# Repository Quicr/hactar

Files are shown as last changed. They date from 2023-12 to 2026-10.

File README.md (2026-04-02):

# HACTAR

Hardware design for test device

## Table of contents:
1. [License](#license)
2. [Quick Start](#quick-start)
3. [Where To Find Things](#where-to-find-things)
4. [LED Definitions](#led-definitions)
5. [Hardware Technologies](#hardware-technologies)
6. [Prerequisites](#prerequisites)
    1. [Debian](#debian-prerequisites)
    2. [MacOS](#macos-prerequisites)
    3. [Windows](#windows-prerequisites)
7. [Firmware](#firmware)
    1. [Management](#management)
    2. [User Interface](#user-interface)
    3. [Network](#network)
    4. [STM32 Toolchain](#stm32-toolchain-installation)
    5. [ESP32 Toolchain](#esp32-toolchain-installation)
8. [Software](#software)
    1. [Hactar-cli](#hactar-cli)
9. [Hactar Setup](#hactar_setup)
10. [Troubleshooting](#troubleshooting)

## License

The license for information in this repository is in [LICENSE](https://github.com/Quicr/hactar/blob/main/LICENSE).  This license covers everything in the repository except for the directory `firmware/ui/dependencies/cmox`, which is covered by the license in [firmware/ui/dependencies/cmox/LICENSE].

## Quick Start

The easiest way to build and flash all firmware is from the repository root:

```bash
# Build everything (requires Rust and ESP-IDF)
make all

# Flash all chips (requires device connected via USB)
make flash

# Or flash individual chips
make flash-mgmt
make flash-ui
make flash-net
```

For new developers looking to start developing on Hactar quickly there are quick start python scripts located in etc/quick-start, that will automatically download and setup your dev environment.

## Where To Find Things

- etc - Extra files

- firmware - Code for UI, Net, and Mgmt chips

- hardware - Schematics and PCB designs

- models - 3D models for project

- software - Tools and Utilities

## LED definitions

LED 1 - Power and Network status:
- Solid Blue - Everything is OK (Connected to MoQ + WiFi + Relay + AI)
- Pulsing Blue - Connecting / Searching (WiFi or MoQ)
- Pulsing Orange - WiFi OK but not connected MoQ
- Blinking Orange - Network Error (bad credentials or no WiFI in range)
- Solid Yellow - Low battery (<20%) - overrides blue states.
- Pulsing Yellow - Charging
- Solid Red - Unprogrammed
- Blinking Red - Hardware/Firmware Failure
- Blinking Purple - AI not connected/not working when user attempts to use it

LED 2 - User Activity & Notifications:
- Off - No messages / actions 
- Blinking Blue - Unread messages/notifications waiting
- Blinking Orange - User error (no headset detected)
- Solid Blue - User holding a PTT/PTTAI button.

## Hardware Technologies
- [KiCad 9](https://www.kicad.org/)
- [FreeCAD v1.0](https://www.freecad.org/)

## Prerequistites

### Debian Prerequistites

#### Groups
``` usermod $USER -aG dialout -aG plugdev ```

#### Rules.d

``` cp etc/rules.d/* /etc/udev/rules.d/ ```

### MacOS Prerequistites

[Homebrew](https://brew.sh/) is the recommended for installing everything in this project.

### Windows Prerequistites

We only support using [WSL2](https://learn.microsoft.com/en-us/windows/wsl/install) for development, you are free to use native windows, but it is untested on actually getting everything in this codebase running.

Any and all instructions for Debian will work on WSL and is recommended you follow those.

## Firmware

### Firmware Technologies
- [Rust](https://www.rust-lang.org/tools/install) (for MGMT chip and CTL tool)
- [GNU arm-none-eabi](https://developer.arm.com/downloads/-/gnu-rm) (for UI chip)
- [ESP-IDF v5.4.2](https://docs.espressif.com/projects/esp-idf/en/v5.4.2/esp32/get-started/index.html) (for NET chip)
- [STM32 CubeMX](https://www.st.com/en/development-tools/stm32cubemx.html)

The Firmware is split into 3 categories. Management, User Interface, and Network.
- Management - STM32F072 (Rust, in `link/mgmt`)
- User Interface - STM32F405 (C++, in `firmware/ui`)
- Network - ESP32S3 (C++, in `firmware/net`)

### CTL Tool

The `ctl` tool (in `link/ctl`) is a Rust command-line program that handles flashing and device communication. It auto-detects connected Hactar devices and provides commands for:

- Flashing firmware to all chips
- Sending commands to chips (ping, version, config)
- Monitoring device logs

Build and run the CTL tool:
```bash
# From repository root
make run-ctl

# Or directly
cd link/ctl && cargo run --release
```

### [___Management___](#management)

The management chip (STM32F072) is responsible for flashing firmware to the UI and NET chips, and routing communication between the USB interface and the other chips.

The MGMT firmware is written in Rust and located in `link/mgmt`.

##### To view your device list

- ##### Debian/MacOS

    `ls /dev/ttyUSB*` or `ls /dev/cu.usbserial-*`

- ##### Windows

    `Open printers and devices`

    `Find serial com ports`

    [Attach to WSL](https://learn.microsoft.com/en-us/windows/wsl/connect-usb)

    `In WSL check dmesg to find which serial port your device binded to`

*Flashing*

From the repository root:

```bash
make flash-mgmt
```

Or using the CTL tool directly:

```bash
link/ctl/target/release/ctl mgmt flash link/mgmt/target/thumbv6m-none-eabi/release/mgmt.bin
```

#### Commands

Run the CTL tool to interact with the device:

```bash
make run-ctl
```

Or use individual commands directly:

```bash
# Test connectivity
link/ctl/target/release/ctl hello

# Ping that traverses all chips (MGMT -> UI -> NET -> MGMT)
link/ctl/target/release/ctl circular-ping

# MGMT commands
link/ctl/target/release/ctl mgmt ping
link/ctl/target/release/ctl mgmt version

# UI commands
link/ctl/target/release/ctl ui ping
link/ctl/target/release/ctl ui version

# NET commands
link/ctl/target/release/ctl net ping
link/ctl/target/release/ctl net version
```

Legacy commands (via hactar-cli monitor):

- **hard reset** - Restarts the main function of the management chip
- **reset** - Resets `ui` chip and then `net` chip
- **reset ui** - Resets `ui` chip
- **reset net** - Resets `net` chip
- **stop ui** - Hold `ui` chip in reset
- **stop net** - Hold `net` chip in reset
- **enable logs** - Enables logs on the management side
- **disable logs** - Disable logs on the management side

#### UI commands

- **ui version** - Get the ui version
- **ui clear_config** - Clear the eeprom config on the ui
- **ui set_sframe** - Sets the sframe key
- **ui get_sframe** - Gets the sframe key
- **ui toggle_logs** - Toggles logging on the ui side
- **ui disable_logs** - Disables logging on the ui side
- **ui enable_logs** - Enables logging on the ui side

#### NET commands

- **net version** - Get the net version
- **net clear_storage** - Clears the storage to default values
- **net set_ssid** - Sets the wifi ssid name and password and saves it in the NVS
- **net get_ssid_names** - Gets all of the ssid names stored
- **net get_ssid_passwords** - Gets all of the ssid passwords stored
- **net clear_ssids** - Clears all ssids from storage
- **net set_moq_url** - Sets the moq url
- **net get_moq_url** - Gets the current moq url
- **net toggle_logs** - Toggles logs on the net side
- **net disable_logs** - Disables logs on the net side
- **net enable_logs** - Enables logs on the net side
- **net disable_loopback** - Disables looping outputted data back in
- **net enable_loopback** - Enables looping outputted data back in
- **net set_fl_config** - Sets the frontline config
- **net burn_efuse** - Burns the efuse to enable jtag debugging

#### Root Makefile Targets

From the repository root:

- `make all` - Build all firmware (MGMT, UI, NET) and the CTL tool
- `make flash` - Flash all chips
- `make flash-mgmt` - Flash only the MGMT chip
- `make flash-ui` - Flash only the UI chip
- `make flash-net` - Flash only the NET chip
- `make run-ctl` - Run the CTL tool interactively
- `make clean` - Clean all build artifacts

**Source code**

The Management Chip firmware is written in Rust and located in `link/mgmt`.

### User Interface

The User Interface chip is where most of the processing takes place. It utilizes a STM32F405 chip empowered by the STM HAL Library. To generate the baseline HAL Library code and Makefile, ST's CubeMX was used.

**Makefile Target Overview**

- `all` - Builds the target bin, elf, and binary files and uploads the code to the User Interface chip. Output firmware/build/ui

- `compile` - Builds the target bin, elf, and binary. Output firmware/build/ui

- `upload` - Uploads the build target to the User Interface chip using the our custom flasher tool with serial usb-c uploading. See [Python Flasher](#py_flasher)

- `upload_debugger` - Uploads the build target to the User Interface chip using the st-flash tools. Please see
[st-flash installation](#stflash_installation) for instructions on installing.

- `upload_cube_uart` - Uploads the build target to the User Interface chip using the STM32_Programmer_CLI with serial usb-c uploading. See [Installation](#stm_installation) for instructions on installing the STM32_Programmer_CLI.

- `upload_cube_swd` - Uploads the build target to the User Interface chip using the STM32_Programmer_CLI with st-link using SWD uploading. See [Installation](#stm_installation) for instructions on installing the STM32_Programmer_CLI.

- `docker` - Uses docker to compile, flash, and monitor the ui chip. By default it will compile the code. To change the functionality, pass a target of the Makefile into the parameter `mft` when being invoked.
    - Ex. `make docker mft=upload`
    - Ex. `make docker mft=monitor`

- `monitor` - Opens a serial communication line with the management chip with a python script that allows for sending of commands.

- `openocd` - Opens a openocd debugging instance. See [Installation](#stm_installation) for instructions on installing openocd.

- `docker-clean` - Removes dockere image that was generated when running docker target.

- `clean` - Deletes the firmware/build/ui directory.

**Source code**

All source code for the User Interface can be found in firmware/ui, firmware/shared, and firmware/shared_inc. Adding C/C++ files in firmware/ui/src and firmware/ui/inc does not require any changes in the makefile.

Making a shared header between chips should be added into firmware/shared_inc.

### **Network**

The network chip is a MOQ client using [quicr](https://github.com/Quicr/libquicr). The network chip communicates with the UI chip via UART serial communication.

We are leveraging the **esp-idf** framework.

**Makefile Target Overview**

- `all` - Runs the `compile` and `upload` targets.

- `compile` - Compiles the net code using the command `idf.py compile`

- `upload` - Uploads the build target to the Network chip using the our custom flasher tool with serial usb-c uploading. See [Python Flasher](#py_flasher)

- `upload_debugger` - Uploads the net code using openocd over an ESP-PROG

- `upload_esptool` - Uploads the network chip code by first sending a command to the mgmt chip to put the board into **net upload** mode. Then uses `esptool.py upload`

- `docker` - Uses docker to compile, flash, and monitor the ui chip. By default it will compile the code. To change the functionality, pass a target of the Makefile into the parameter `mft` when being invoked.
    - Ex. `make docker mft=upload`
    - Ex. `make docker mft=monitor`

- `monitor` - Opens a serial communication line with the management chip with a python script that allows for sending of commands.

- `clean` - Deletes the firmware/net/build directory.

- `fullclean` - Invokes idf.py fullclean.

- `docker-clean` - Removes dockere image that was generated when running docker target.

<b>Source code</b>

All source code for the network chip can be found in `firmware/net`, `firmware/shared`, and `firmware/shared_inc`.

## MGMT Toolchain Installation

The following tools are required for building the Management chip firmware and CTL tool.
- [Make](#make) \[required]
- [Rust](#rust) \[required]

##### **Make**

Make is used for compiling and uploading automation for each chip firmware.

*Debian*

```bash
sudo apt install make
```
*MacOS*

```brew
brew install make
```

##### Rust with Embedded ARM Target

Rust is required for building the MGMT firmware and CTL tool. **The MGMT chip requires the `thumbv6m-none-eabi` target** for cross-compilation to the STM32F072 (ARM Cortex-M0).

*All Platforms*

1. Install Rust:
```bash
curl --proto '=https' --tlsv1.2 -sSf https://sh.rustup.rs | sh
```

2. **Required:** Add the ARM Cortex-M0 target and tools for MGMT firmware:
```bash
rustup target add thumbv6m-none-eabi
cargo install cargo-binutils
rustup component add llvm-tools
```

Without the `thumbv6m-none-eabi` target, you will not be able to build the MGMT firmware.

## UI Toolchain Installation

The following tools are used for building the User Interface chip firmware.
- [ARM None Eabi Toolchain](#arm-none-eabi-toolchain) \[required]
- [Python3](https://www.python.org/downloads/) \[optional]
- [ST-Flash](#st-flash) \[optional]
- [STM32_Programmer_CLI](#stm32-programmer-cli) \[optional]
- [OpenOCD](#openocd) \[optional]

##### ARM None Eabi Toolchain

*Debian*

```bash
sudo apt install gcc-arm-none-eabi binutils-arm-none-eabi
```

*MacOS*

```sh
brew install --cask gcc-arm-embedded
```

##### ST Flash

*Debian*

```bash
sudo apt install stlink-tools
```

*MacOS*

```bash
brew install stm32flash
```

##### STM32 Programmer CLI

The STM32 Programmer CLI comes packages with the STM32 Cube Programmer. You'll need to download and install The STM32 Cube Programmer and add the STM32_Programmer_CLI binary to your path.
```
https://www.st.com/en/development-tools/stm32cubeprog.html
```

*Debian*

- Open your `.bashrc` file:
    ```
    sudo nano ~/.bashrc
    ```

- Add the following line to the `.bashrc` file
    ```bash
    export PATH="$PATH:/path/to/stm_cube_programmer/bin"
    ```

*MacOS*

- TODO

#### OpenOCD

Open On Chip Debugger, created by Dominic Rath, is a debugging software that can be used with micro-controllers to run debugging tools and stepping through code.

*Debian*

Run the following command:

```bash
sudo apt install openocd gdb-arm-none-eabi libnewlib-arm-none-eabi libstdc++-arm-none-eabi-newlib
```

If you don't have python3.8 installed, which is used for arm-none-eabi-gdb, then you'll need to install it
```bash
sudo add-apt-repository ppa:deadsnakes/ppa
apt update
sudo apt install python3.8
```

*MacOS*

Run the following commands in a terminal to install `openocd`

```brew
brew update
```

```brew
brew install open-ocd --HEAD
```
## ESP32 Toolchain Installation

This project leverages the usage of the ESP-IDF Library for the network chip.

The following tools are used for the Network.
- [Make](#make) \[required]
- [esp-idf v5.4.2](#esp-idf) \[required]

##### ESP IDF

- [Debian](https://docs.espressif.com/projects/esp-idf/en/v5.4.2/esp32/get-started/linux-macos-setup.html)
- [MacOS](https://docs.espressif.com/projects/esp-idf/en/v5.4.2/esp32/get-started/linux-macos-setup.html)

## Software 

### Hactar-cli

Hactar-cli is a multi-faceted tool, where it can flash, monitor, and send commands. We ship a version of python that includes pyserial with it.

#### Flasher

Generally the flasher is used automatically in the Makefile. However, you can flash whatever binary you want onto a chip that the flasher is designed for by running it as python script in the firmware/flasher folder.

ex.

```sh
python3 main.py flash --port=<port> --baud=<baudrate> --chip="<chip>" -bin="./build/app.bin"
```

You can omit passing a port and the flasher will attempt to find a Hactar board by searching your active usb serial ports.

```sh
python3 main.py flash --baud=115200 --chip="ui" -bin="./build/ui.bin"
```

#### Monitor

The serial monitor is a very simple serial monitor that allows a user to send commands to the mgmt chip as well as read serial logs.

This monitor can be used by the following command:

```sh
python main.py monitor --port=<port> --baud=<baudrate>
```

Ex.
```sh
python main.py monitor --port=/dev/ttyUSB0
```

### Hactar Setup

#### Prerequisites

- USB-C Cable
- [Rust](https://www.rust-lang.org/tools/install) with `thumbv6m-none-eabi` target
- arm-none-eabi toolchain (for UI chip)
- ESP-IDF v5.4 (for NET chip)
- make

Install Rust target for MGMT:
```bash
rustup target add thumbv6m-none-eabi
cargo install cargo-binutils
rustup component add llvm-tools
```

#### Flash All Chips

The simplest way to set up a Hactar device is to flash all chips at once from the repository root:

```bash
# Build everything
make all

# Flash all chips (MGMT, UI, NET)
make flash
```

#### Flash Individual Chips

*Management Chip*

```bash
make flash-mgmt
```

The MGMT chip must be flashed first as it handles flashing the other chips.

*UI Chip*

```bash
make flash-ui
```

*Network Chip*

```bash
make flash-net
```

Note: The NET chip firmware is large and takes about 4 minutes to upload.

*Debug mode example*

- Prerequisites
    - Python3
        - **pyserial** - download using `pip3 install pyserial`
    - make
    - USB-C Cable
- Have your hactar board programmed and plugged in using a USB-C cable
- Navigate to either `hactar/firmware/ui` or `hactar/firmware/net`
    - **NOTE** - Update your ports appropriately in the makefile
- Enter `make py_monitor` into your terminal
- You should see a serial monitor open in your terminal requesting a command. Enter `debug` to put the hactar board into debugging mode.
    - See [Management Commands](#management_commands) for more commands that can be sent to the hactar board.
- The first and third LED from the left will turn blue indicating debug mode and your console will receive serial debug messages from the UI and Net chips.
- Enter `exit` to leave the monitor

## Troubleshooting

### USB device disconnects shortly after connecting randomly

- CH340 chips are shared with a program called brltty which is for braille devices. Debian automatically will try to connect it to brltty and therefore is in use, you can unplug and replug until it doesn't take control of the device or you can uninstall brltty if you don't need braille device.
    - ``` sudo apt remove brltty ```

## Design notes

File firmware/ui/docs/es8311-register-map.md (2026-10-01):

# ES8311 Register Map

Transcribed from `ES8311 DS.pdf`, revision 8.0 (May 2020). Fields not listed in a table are reserved or undocumented by the datasheet.

## 0x00 Reset (default `0x1F`)

- `CSM_ON` [7]: 0 = CSM power down (default); 1 = CSM power on.
- `MSC` [6]: 0 = serial port slave (default); 1 = serial port master.
- `SEQ_DIS` [5]: 0 = power-up sequence enabled (default); 1 = disabled.
- `RST_DIG` [4]: 0 = digital logic not reset; 1 = reset digital logic except control port (default).
- `RST_CMG` [3]: 0 = clock manager not reset; 1 = reset clock manager (default).
- `RST_MST` [2]: 0 = master block not reset; 1 = reset master block (default).
- `RST_ADC_DIG` [1]: 0 = ADC digital block not reset; 1 = reset ADC digital block (default).
- `RST_DAC_DIG` [0]: 0 = DAC digital block not reset; 1 = reset DAC digital block (default).

Remarks:
Chip must be reset at the start of each program. 0b0011'1111
given we are using ES8311 as master, then we should ensure that we select slave mode on bit 6

Hold in reset: 0b0011'1111
Running: 0b1100'0000

## 0x01 Clock Manager (default `0x00`)

- `MCLK_SEL` [7]: 0 = use MCLK pin (default); 1 = use BCLK pin.
- `MCLK_INV` [6]: 0 = normal MCLK (default); 1 = invert MCLK.
- `MCLK_ON` [5]: 0 = MCLK off (default); 1 = MCLK on.
- `BCLK_ON` [4]: 0 = BCLK off (default); 1 = BCLK on.
- `CLKADC_ON` [3]: 0 = ADC digital clock off (default); 1 = on.
- `CLKDAC_ON` [2]: 0 = DAC digital clock off (default); 1 = on.
- `ANACLKADC_ON` [1]: 0 = ADC analog clock off; 1 = on (default).
- `ANACLKDAC_ON` [0]: 0 = DAC analog clock off; 1 = on (default).

Remarks:
Using MCLK. Bit 5, MLK in control, enables/disables the mclk input pin. Since we are using our ES8311 in master, then we need sdp, adc, dac, analog adc and analog dac on

Set to: 0b0011'1111

## 0x02 Clock Manager (default `0x00`)

- `DIV_PRE` [7:5]: MCLK pre-divider; `mclk_prediv = mclk / (DIV_PRE + 1)`.
- `MULT_PRE` [4:3]: pre-multiplier; 0 = x1 (default), 1 = x2, 2 = x4, 3 = x8.
- `PATHSEL` [2]: 0 = no DFF path (default); 1 = DFF path.
- `DELYSEL` [1:0]: clock-doubler delay; 0 = 5 ns (default), 1 = 10 ns, 2 = 15 ns, 3 = 15 ns.

Remarks:
Digital clock aim is to be some defaulted value provided by the table on page 16 in the User Guide 
At MCLK 12Mhz 0x00 DIV1, MULT1 - 0b0000'0000, which doesn't make sense, because that gives an internal clock of 12Mhz, which
according to the User Guide, on page 14, that the clock divider needs to output <10Mhz. Their table is whack.
Roughly, I think given we are running at 3.0V, then we should be no higher than 8.9Mhz, by some crazy math, on the divider.

Therefore, to get the ratio integral ratio of 16 mentioned on pg 15 of the user guide, we can divide by 5, and multiply by 8
to get dig_mclk = 19.2Mhz.

This should be acceptable for 8Khz too.

For 19.2Mhz set register to 0x98

## 0x03 Clock Manager (default `0x10`)

- `ADC_FSMODE` [6]: 0 = single speed (default); 1 = double speed.
- `ADC_OSR` [5:0]: ADC delta-sigma oversampling rate. 0-14 unused; 15 = 60 x Fs; 16 = 64 x Fs single-speed or 32 x Fs double-speed (default); 31 = 124 x Fs or 62 x Fs; 32 = 128 x Fs or 64 x Fs; 63 = 252 x Fs or 126 x Fs.

Remarks:
Defaulting to table entry 12mhz 48khz 0x19 - 0b0001'1001
Not sure what the function of 

## 0x04 Clock Manager (default `0x10`)

- `DAC_OSR` [6:0]: DAC oversampling rate. 0-15 unused; 16 = 64 x Fs (default); 17 = 68 x Fs; 32 = 128 x Fs; 64 = 256 x Fs; 127 = 508 x Fs.

Remarks:
Defaulting to table entry 12mhz 48khz 0x19 - 0b0001'1001

## 0x05 Clock Manager (default `0x00`)

- `DIV_CLKADC` [7:4]: ADC MCLK divider; `adc_mclk = dig_mclk / (DIV_CLKADC + 1)`.
- `DIV_CLKDAC` [3:0]: DAC MCLK divider; `dac_mclk = dig_mclk / (DIV_CLKDAC + 1)`.

Remarks:
The ratio for 48khz with a dig_mclk = 19.2mhz is 400 % 16 = 0
The ratio for 8Khz with a dig_mclk = 19.2mhz = 2400 % 16 = 0
This can stay untouched at 0x00

## 0x06 Clock Manager (default `0x03`)

- `BCLK_CON` [6]: master BCLK output control; 0 = continuous (default); 1 = stop after transfer.
- `BCLK_INV` [5]: 0 = normal BCLK (default); 1 = inverted BCLK.
- `DIV_BCLK` [4:0]: master BCLK divider. 0-19 = MCLK / (`DIV_BCLK` + 1), default 3; 20 = /22; 21 = /24; 22 = /25; 23 = /30; 24 = /32; 25 = /33; 26 = /34; 27 = /36; 28 = /44; 29 = /48; 30 = /66; 31 = /72.

Remarks:
Since we are using a non-standard clock, we need to stop the BCLK early, so bit 6 should be a 1
Note, we are aiming to have a BCLK = LRCLK * 32 bits * 2 channels, given we are early stopping the bclk then 
we can need to have a bclk > than our minimum bclk in a perfect division.

Ex. 
48KHz * 32 * 2 = 3.072MHz
12Mhz / 3.072Mhz = 3.90625

So we need to divide by 3 so we still have a faster bclk

Therefore, DIV_BCLK = 2
Giving us 

BCLK = MCLK / DIV_BCLK+1 
BCLK = 12MHz / 2+1 = 4MHz

## 0x07 Clock Manager (default `0x00`)

- `TRI_BLRCK` [5]: 0 = normal BCLK/LRCK output (default); 1 = tri-state output.
- `TRI_ADCDAT` [4]: 0 = normal ADCDAT output (default); 1 = tri-state output.
- `DIV_LRCK[11:8]` [3:0]: upper four bits of the master LRCK divider; `LRCK = MCLK / (LRCK_DIV + 1)`.

Remarks:
48KHz DIV_LRCK=0
32KHz DIV_LRCK=1
8KHz DIV_LRCK=5

## 0x08 Clock Manager (default `0xFF`)

- `DIV_LRCK[7:0]` [7:0]: lower eight bits of the master LRCK divider; `LRCK = MCLK / (LRCK_DIV + 1)`. A divider of zero holds LRCK high.

Remarks:
48Khz DIV_LCK=249
32Khz DIV_LCK=118
8Khz DIV_LCK=219

## 0x09 SDP Input (default `0x00`)

- `SDP_IN_SEL` [7]: 0 = left input data to DAC (default); 1 = right input data to DAC.
- `SDP_IN_MUTE` [6]: 0 = unmute (default); 1 = mute.
- `SDP_IN_LRP` [5]: I2S/justified: 0 = normal L/R polarity (default), 1 = inverted. DSP/PCM: 0 = MSB on second BCLK rising edge after LRCK (default), 1 = first edge.
- `SDP_IN_WL` [4:2]: 0 = 24 bit (default); 1 = 20 bit; 2 = 18 bit; 3 = 16 bit; 4 = 32 bit.
- `SDP_IN_FMT` [1:0]: 0 = I2S (default); 1 = left justified; 2 = reserved; 3 = DSP/PCM.

Remarks: 
Soft mute exists in this register. 
We are doing 16 bit on 32 bit frames, could change if needed
I2S serial audio data format is what we normally use

In the STM32 settings it is set to I2S Phillips, and so should the ES8311,
but there is an error in the datasheet.

Correction!
bit[1:0] - 0 = Left justified, 1 = I2S Phillips, 2 = reserved 3 = DSP/PCM

Set to 0b0|0|0|1'00|00 (0x10)

## 0x0A SDP Output (default `0x00`)

- `SDP_OUT_MUTE` [6]: 0 = unmute (default); 1 = mute.
- `SDP_OUT_LRP` [5]: I2S/justified: 0 = normal L/R polarity (default), 1 = inverted. DSP/PCM: 0 = MSB on second BCLK rising edge after LRCK (default), 1 = first edge.
- `SDP_OUT_WL` [4:2]: 0 = 24 bit (default); 1 = 20 bit; 2 = 18 bit; 3 = 16 bit; 4 = 32 bit.
- `SDP_OUT_FMT` [1:0]: 0 = I2S (default); 1 = left justified; 2 = reserved; 3 = DSP/PCM.

Remarks:
Same as above

Set to 0b0|0|0|1'00|00 (0x10)

## 0x0B System (default `0x00`)

- `PWRUP_A` [7:3]: power-up stage A delay. At 8 kHz, 0-31 corresponds to 120 us-1392 ms.
- `PWRUP_B[3:1]` [2:0]: upper three bits of power-up stage B delay. At 8 kHz, 0-31 corresponds to 120 us-624 ms.

Remarks:
Leave at zero

## 0x0C System (default `0x20`)

- `PWRUP_B[0]` [7]: low bit of power-up stage B delay.
- `PWRUP_C` [6:0]: power-up stage C delay. At 8 kHz, 0-31 corresponds to 120 us-1401 ms.

Remarks:
Leave at zero

## 0x0D System (default `0xFC`)

- `PDN_ANA` [7]: 0 = enable analog circuits; 1 = power down (default).
- `PDN_IBIASGEN` [6]: 0 = enable analog bias; 1 = power down (default).
- `PDN_ADCBIASGEN` [5]: 0 = enable ADC bias; 1 = power down (default).
- `PDN_ADCVERFGEN` [4]: 0 = enable ADC reference; 1 = power down (default).
- `PDN_DACVREFGEN` [3]: 0 = enable DAC reference; 1 = power down (default).
- `PDN_VREF` [2]: 0 = disable internal reference; 1 = enable (default).
- `VMIDSEL` [1:0]: 0 = VMID power down (default); 1 = normal-speed startup; 2 = normal operation; 3 = fast startup.

Remarks:
0xFE

## 0x0E System (default `0x6A`)

- `PDN_PGA` [6]: 0 = enable analog PGA; 1 = power down (default).
- `PDN_MOD` [5]: 0 = enable analog ADC modulator; 1 = power down (default).
- `RST_MOD` [4]: 0 = normal (default); 1 = reset modulator.
- `VROI` [3]: 0 = normal impedance; 1 = low impedance (default).
- `LPVREFBUF` [2]: 0 = normal internal reference mode (default); 1 = low-power mode.

Remarks:
0b000'1010
0x0A

## 0x0F System (default `0x00`)

- `LPDAC` [7]: 0 = normal (default); 1 = DAC low-power mode.
- `LPPGA` [6]: 0 = normal (default); 1 = PGA low-power mode.
- `LPPGAOUT` [5]: 0 = normal (default); 1 = PGA output low-power mode.
- `LPVCMMOD` [4]: 0 = normal (default); 1 = ADC low-power mode.
- `LPADCVRP` [3]: 0 = normal (default); 1 = ADC reference low-power mode.
- `LPDACVRP` [2]: 0 = normal (default); 1 = DAC reference low-power mode.
- `LPFLASH` [1]: 0 = normal (default); 1 = ADC low-power mode.
- `LPINT1` [0]: 0 = normal (default); 1 = ADC low-power mode.

Remarks:
Only need to worry about this when we want to do low power

## 0x10 System (default `0x13`)

- `SYNCMODE` [7]: 0 = normal (default); 1 = sync mode.
- `VMIDLOW` [6:5]: 0 = VDDA/2 (default); 1 = VDDA/2 - 75 mV; 2 = VDDA/2 - 145 mV; 3 = VDDA/2 - 175 mV.
- `DAC_IBIAS_SW` [4]: 0 = normal DAC bias; 1 = higher DAC bias (default).
- `IBIAS_SW` [3:2]: 0 = bias level 0 (default); 1 = level 1; 2 = level 2; 3 = level 3.
- `VX2OFF` [1]: 0 = enable internal reference doubler; 1 = off (default).
- `VX1SEL` [0]: 0 = 1.45 V; 1 = 1.65 V (default).

- Remarks, not sure what sync mode means, but we can leave this for now

## 0x11 System (default `0x7C`)

- `VSEL` [6:0]: internal use.

## 0x12 System (default `0x02`)

- `PDN_DAC` [1]: 0 = enable DAC; 1 = power down (default).
- `ENREFR` [0]: 0 = disable DAC output reference (default); 1 = enable it.

Remarks:
0x01

## 0x13 System (default `0x40`)

- `HPSW` [4]: 0 = line-output drive (default); 1 = headphone drive.

Remarks:
We want headphones not line output
0x50

## 0x14 System (default `0x10`)

- `DMIC_ON` [6]: 0 = no DMIC; 1 = select DMIC and DMIC_SDA from MIC1P.
- `LINSEL` [4]: 0 = no input selection; 1 = select MIC1P-MIC1N.
- `PGAGAIN` [3:0]: ADC PGA gain: 0 = 0 dB through 10 = 30 dB in 3 dB steps.

Remarks:
We are using an analog mic 
0x10

## 0x15 ADC (default `0x00`)

- `ADC_RAMPRATE` [7:4]: ADC volume-control ramp: 0 = disabled; 1-15 = 0.25 dB per 4-65536 LRCKs.
- `DMIC_SENSE` [0]: 0 = latch DMIC on positive edge; 1 = negative edge.

Remarks:
We are not using DMIC 
Keep the ramp rate at default
0x00

## 0x16 ADC (default `0x04`)

- `ADC_SYNC` [5]: 0 = non-standard audio clock; 1 = standard audio clock.
- `ADC_INV` [4]: 0 = normal; 1 = inverted.
- `ADC_RAMCLR` [3]: clear ADC RAM when LRCK/ADC MCLK is active.
- `ADC_SCALE` [2:0]: ADC gain scale: 0 = 0 dB; 1 = 6 dB; 2 = 12 dB; 3 = 18 dB; 4 = 24 dB (default); 5 = 30 dB; 6 = 36 dB; 7 = 42 dB.

Remarks: 48khz and 8khz are standard audio clocks so we should keep ADC_SYNC=0

## 0x17 ADC Volume (default `0x00`)

- `ADC_VOLUME` [7:0]: 0x00 = -95.5 dB; 0x01 = -90.5 dB; then 0.5 dB/step; 0xBE = -0.5 dB; 0xBF = 0 dB; 0xC0 = +0.5 dB; 0xFF = +32 dB. With ALC enabled, this is `MAXGAIN`.

Remarks: Leave as default

## 0x18 ADC ALC (default `0x00`)

- `ALC_EN` [7]: 0 = disable (default); 1 = enable ADC automatic level control.
- `ADC_AUTOMUTE_EN` [6]: 0 = disable (default); 1 = enable ADC automute.
- `ALC_WINSIZE` [3:0]: ALC window: 0 = 0.25 dB/2 LRCK; 1-15 increase through 0.25 dB/65536 LRCK.

Remarks: Leave as default, we don't want the ALC yet

## 0x19 ADC ALC Level (default `0x00`)

- `ALC_MAXLEVEL` [7:4]: ALC maximum target: 0 = -30.1 dB through 15 = -6.0 dB.
- `ALC_MINLEVEL` [3:0]: ALC minimum target: 0 = -30.1 dB through 15 = -6.0 dB.

## 0x1A ADC Automute (default `0x00`)

- `ADC_AUTOMUTE_WS` [7:4]: detect window: samples = 2048 x (`winsize` + 1); 0 = 2048 samples / 42 ms, 15 = 32768 samples / 688 ms.
- `ADC_AUTOMUTE_NG` [3:0]: noise gate: 0 = -96 dB, increasing by 6 dB through 7 = -54 dB, then 3 dB through 15 = -30 dB.

## 0x1B ADC Automute/HPF (default `0x0C`)

- `ADC_AUTOMUTE_VOL` [7:5]: mute output gain; gain = value x -4 dB, 0 = 0 dB through 7 = -28 dB.
- `ADC_HPFS1` [4:0]: ADC HPF stage-1 coefficient.

## 0x1C ADC EQ/HPF (default `0x4C`)

- `ADC_EQBYPASS` [6]: 0 = normal; 1 = bypass (default).
- `ADC_HPF` [5]: 0 = freeze offset; 1 = dynamic HPF.
- `ADC_HPFS2` [4:0]: ADC HPF stage-2 coefficient.

## 0x1D ADCEQ B0[29:24] (default `0x00`

- `ADCEQ_B0[29:24]` [5:0]: upper six bits of the 30-bit ADCEQ B0 coefficient.

## 0x1E ADCEQ B0[23:16] (default `0x00`)

- `ADCEQ_B0[23:16]` [7:0]: ADCEQ B0 coefficient bits 23:16.

## 0x1F ADCEQ B0[15:8] (default `0x00`)

- `ADCEQ_B0[15:8]` [7:0]: ADCEQ B0 coefficient bits 15:8.

## 0x20 ADCEQ B0[7:0] (default `0x00`)

- `ADCEQ_B0[7:0]` [7:0]: ADCEQ B0 coefficient bits 7:0.

## 0x21 ADCEQ A1[29:24] (default `0x00`)

- `ADCEQ_A1[29:24]` [7:0]: upper byte of the 30-bit ADCEQ A1 coefficient, per datasheet.

## 0x22 ADCEQ A1[23:16] (default `0x00`)

- `ADCEQ_A1[23:16]` [7:0]: ADCEQ A1 coefficient bits 23:16.

## 0x23 ADCEQ A1[15:8] (default `0x00`)

- `ADCEQ_A1[15:8]` [7:0]: ADCEQ A1 coefficient bits 15:8.

## 0x24 ADCEQ A1[7:0] (default `0x00`)

- `ADCEQ_A1[7:0]` [7:0]: ADCEQ A1 coefficient bits 7:0.

## 0x25 ADCEQ A2[29:24] (default `0x00`)

- `ADCEQ_A2[29:24]` [7:0]: upper byte of the 30-bit ADCEQ A2 coefficient, per datasheet.

## 0x26 ADCEQ A2[23:16] (default `0x00`)

- `ADCEQ_A2[23:16]` [7:0]: ADCEQ A2 coefficient bits 23:16.

## 0x27 ADCEQ A2[15:8] (default `0x00`)

- `ADCEQ_A2[15:8]` [7:0]: ADCEQ A2 coefficient bits 15:8. The datasheet has a likely typo calling this B0.

## 0x28 ADCEQ A2[7:0] (default `0x00`)

- `ADCEQ_A2[7:0]` [7:0]: ADCEQ A2 coefficient bits 7:0.

## 0x29 ADCEQ B1[29:24] (default `0x00`)

- `ADCEQ_B1[29:24]` [7:0]: upper byte of the 30-bit ADCEQ B1 coefficient, per datasheet.

## 0x2A ADCEQ B1[23:16] (default `0x00`)

- `ADCEQ_B1[23:16]` [7:0]: ADCEQ B1 coefficient bits 23:16.

## 0x2B ADCEQ B1[15:8] (default `0x00`)

- `ADCEQ_B1[15:8]` [7:0]: ADCEQ B1 coefficient bits 15:8. The datasheet has a likely typo calling this B0.

## 0x2C ADCEQ B1[7:0] (default `0x00`)

- `ADCEQ_B1[7:0]` [7:0]: ADCEQ B1 coefficient bits 7:0.

## 0x2D ADCEQ B2[29:24] (default `0x00`)

- `ADCEQ_B2[29:24]` [7:0]: upper byte of the 30-bit ADCEQ B2 coefficient, per datasheet.

## 0x2E ADCEQ B2[23:16] (default `0x00`)

- `ADCEQ_B2[23:16]` [7:0]: ADCEQ B2 coefficient bits 23:16.

## 0x2F ADCEQ B2[15:8] (default `0x00`)

- `ADCEQ_B2[15:8]` [7:0]: ADCEQ B2 coefficient bits 15:8.

## 0x30 ADCEQ B2[7:0] (default `0x00`)

- `ADCEQ_B2[7:0]` [7:0]: ADCEQ B2 coefficient bits 7:0.

## 0x31 DAC (default `0x00`)

- `DAC_DSMMUTE_TO` [7]: 0 = mute to 8 (default); 1 = mute to 7/9.
- `DAC_DSMMUTE` [6]: 0 = unmute (default); 1 = mute.
- `DAC_DEMMUTE` [5]: 0 = unmute (default); 1 = mute.
- `DAC_INV` [4]: 0 = no phase inversion (default); 1 = 180 degree phase inversion.
- `DAC_RAMCLR` [3]: 0 = normal (default); 1 = clear DAC RAM when LRCK/DAC MCLK is active.
- `DAC_DSMDITH_OFF` [2]: 0 = dither on (default); 1 = dither off.

## 0x32 DAC Volume (default `0x00`)

- `DAC_VOLUME` [7:0]: 0x00 = -95.5 dB; 0x01 = -95.0 dB; then 0.5 dB/step; 0xBE = -0.5 dB; 0xBF = 0 dB; 0xC0 = +0.5 dB; 0xFF = +32 dB.

## 0x33 DAC Offset (default `0x00`)

- `DAC_OFFSET` [7:0]: DAC offset.

## 0x34 DAC DRC (default `0x00`)

- `DRC_EN` [7]: 0 = disable DRC (default); 1 = enable.
- `DRC_WINSIZE` [3:0]: DRC window: 0 = 0.25 dB/2 LRCK (default); 1-15 increase through 0.25 dB/65536 LRCK.

## 0x35 DAC DRC Level (default `0x00`)

- `DRC_MAXLEVEL` [7:4]: DRC maximum target: 0 = -30.1 dB through 15 = -6.0 dB.
- `DRC_MINLEVEL` [3:0]: DRC minimum target: 0 = -30.1 dB through 15 = -6.0 dB.

## 0x36 DAC (default `0x00`)

- No bit mappings are provided for this register in the supplied datasheet.

## 0x37 DAC (default `0x08`)

- `DAC_RAMPRATE` [7:4]: DAC VC/DRC ramp: 0 = disabled (default); 1-15 = 0.25 dB per 4-65536 LRCKs.
- `DAC_EQBYPASS` [3]: 0 = DACEQ enabled (default); 1 = bypass.

## 0x38 DACEQ B0[29:24] (default `0x00`)

- `DACEQ_B0[29:24]` [5:0]: upper six bits of the 30-bit DACEQ B0 coefficient.

## 0x39 DACEQ B0[23:16] (default `0x00`)

- `DACEQ_B0[23:16]` [7:0]: DACEQ B0 coefficient bits 23:16.

## 0x3A DACEQ B0[15:8] (default `0x00`)

- `DACEQ_B0[15:8]` [7:0]: DACEQ B0 coefficient bits 15:8.

## 0x3B DACEQ B0[7:0] (default `0x00`)

- `DACEQ_B0[7:0]` [7:0]: DACEQ B0 coefficient bits 7:0.

## 0x3C DACEQ B1[29:24] (default `0x00`)

- `DACEQ_B1[29:24]` [7:0]: upper byte of the 30-bit DACEQ B1 coefficient, per datasheet.

## 0x3D DACEQ B1[23:16] (default `0x00`)

- `DACEQ_B1[23:16]` [7:0]: DACEQ B1 coefficient bits 23:16.

## 0x3E DACEQ B1[15:8] (default `0x00`)

- `DACEQ_B1[15:8]` [7:0]: DACEQ B1 coefficient bits 15:8.

## 0x3F DACEQ B1[7:0] (default `0x00`)

- `DACEQ_B1[7:0]` [7:0]: DACEQ B1 coefficient bits 7:0.

## 0x40 DACEQ A1[29:24] (default `0x00`)

- `DACEQ_A1[29:24]` [7:0]: upper byte of the 30-bit DACEQ A1 coefficient, per datasheet.

## 0x41 DACEQ A1[23:16] (default `0x00`)

- `DACEQ_A1[23:16]` [7:0]: DACEQ A1 coefficient bits 23:16.

## 0x42 DACEQ A1[15:8] (default `0x00`)

- `DACEQ_A1[15:8]` [7:0]: DACEQ A1 coefficient bits 15:8.

## 0x43 DACEQ A1[7:0] (default `0x00`)

- `DACEQ_A1[7:0]` [7:0]: DACEQ A1 coefficient bits 7:0.

## 0x44 GPIO (default `0x00`)

- `ADC2DAC_SEL` [7]: 0 = disable ADC-to-DAC path (default); 1 = enable.
- `ADCDAT_SEL` [6:4]: ADCDAT output: 0 = ADC + ADC (default); 1 = ADC + 0; 2 = 0 + ADC; 3 = 0 + 0; 4 = DACL + ADC; 5 = ADC + DACR; 6 = DACL + DACR; 7 = N/A.
- `I2C_WL` [3]: internal use.
- `GPIO_SEL` [2:0]: internal use.

## 0x45 GP (default `0x00`)

- `FORCECSM` [7:4]: internal use.
- `ADC_DLY_SEL` [3]: internal use.
- `DAC_DLY_SEL` [2]: internal use.
- `DAC_AUTOCHN` [1]: internal use.
- `PULLUP_SE` [0]: BCLK/LRCK pull-up: 0 = on (default); 1 = off.

## 0xFA I2C (default `0x00`)

- `I2C_RETIME` [1]: internal use.
- `INI_REG` [0]: 0 = no reset (default); 1 = reset registers to defaults except this register.

## 0xFC Flag (default `0x00`, read-only fields)

- `FLAG_CSM_CHIP` [6:4]: CSM state: 0 = S0; 1 = S1; 2 = S2; 3 = S3; 6 = S6; 7 = S7; other values are dummy states.
- `FLAG_ADCAM` [1]: ADC automute flag.
- `FLAG_DACAM` [0]: internal use.

## 0xFD Chip ID 1 (default `0x83`)

- `CHIP_ID1` [7:0]: chip ID, `0x83`.

## 0xFE Chip ID 2 (default `0x11`)

- `CHIP_ID2` [7:0]: chip ID, `0x11`.

## 0xFF Chip Version (default `0x00`)

- `CHIP_VER` [7:0]: chip version information.

## Comments

- The datasheet states that MCLK, LRCK, and SCLK should be present before control-register configuration; otherwise reset the codec after the clocks are provided.
- Registers `0x21`, `0x25`, `0x29`, `0x2D`, `0x3C`, and `0x40` describe 30-bit coefficient upper portions as `[29:24]` while exposing eight bits. This is reproduced as documented.
- Register `0x36` has no bit definitions in the supplied revision.
- Do not write undocumented or internal-use fields unless validated by the vendor.

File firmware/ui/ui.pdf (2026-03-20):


20/03/2026

ui Project
Configuration Report

## 1. Description

### 1.1. Project

Project Name | ui
Board Name | custom
Generated with: | STM32CubeMX 6.16.1
Date | 03/20/2026

### 1.2. MCU

MCU Series | STM32F4
MCU Line | STM32F405/415
MCU name | STM32F405RGTx
MCU Package | LQFP64
MCU Pin number | 64

### 1.3. Core(s) information

Core(s) | Arm Cortex-M4

## 2. Pinout Configuration

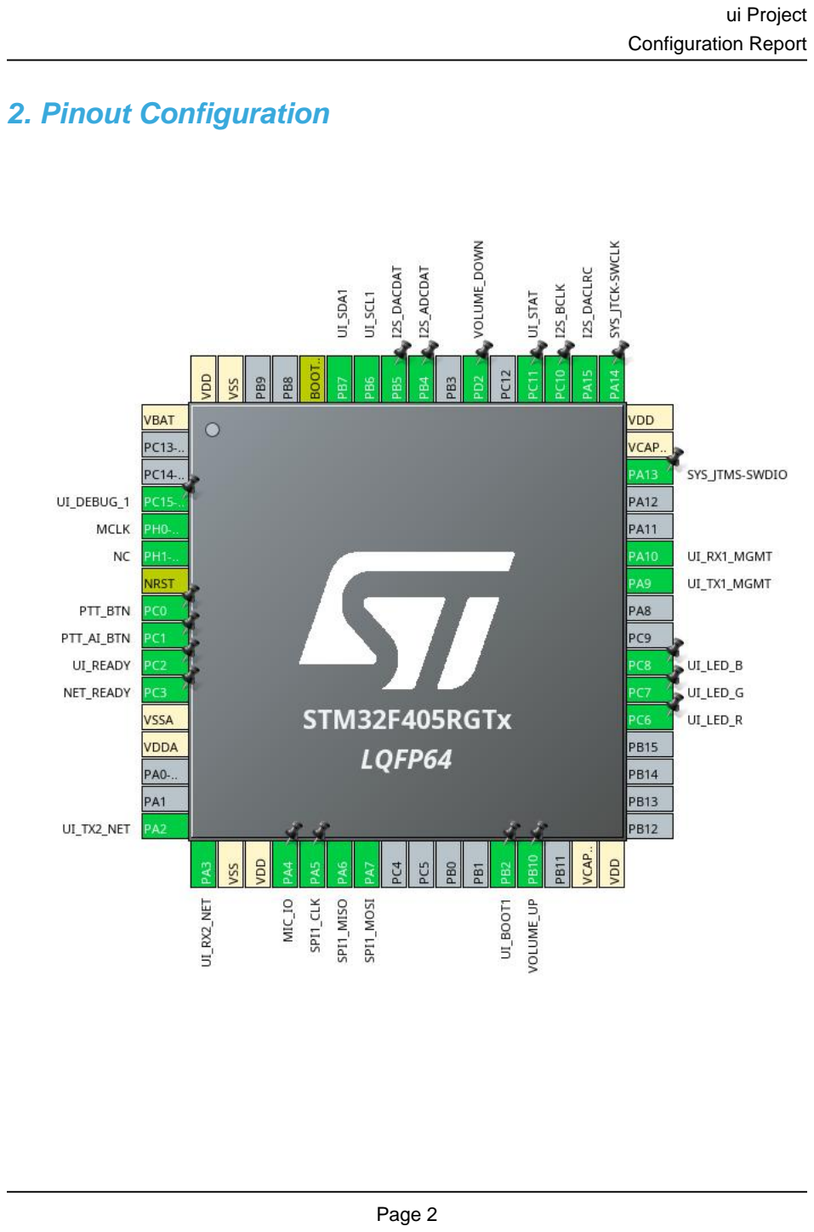
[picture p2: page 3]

## 3. Pins Configuration

Pin Number LQFP64 | Pin Name (function after reset) | Pin Type | Alternate Function(s) | Label
1 | VBAT | Power
4 | PC15-OSC32_OUT * | I/O | GPIO_Output | UI_DEBUG_1
5 | PH0-OSC_IN | I/O | RCC_OSC_IN | MCLK
6 | PH1-OSC_OUT | I/O | RCC_OSC_OUT | NC
7 | NRST | Reset
8 | PC0 * | I/O | GPIO_Input | PTT_BTN
9 | PC1 * | I/O | GPIO_Input | PTT_AI_BTN
10 | PC2 * | I/O | GPIO_Output | UI_READY
11 | PC3 | I/O | GPIO_EXTI3 | NET_READY
12 | VSSA | Power
13 | VDDA | Power
16 | PA2 | I/O | USART2_TX | UI_TX2_NET
17 | PA3 | I/O | USART2_RX | UI_RX2_NET
18 | VSS | Power
19 | VDD | Power
20 | PA4 * | I/O | GPIO_Input | MIC_IO
21 | PA5 | I/O | SPI1_SCK | SPI1_CLK
22 | PA6 | I/O | SPI1_MISO
23 | PA7 | I/O | SPI1_MOSI | SPI1_MOSI
28 | PB2 * | I/O | GPIO_Input | UI_BOOT1
29 | PB10 * | I/O | GPIO_Input | VOLUME_UP
31 | VCAP_1 | Power
32 | VDD | Power
37 | PC6 | I/O | TIM3_CH1 | UI_LED_R
38 | PC7 | I/O | TIM3_CH2 | UI_LED_G
39 | PC8 | I/O | TIM3_CH3 | UI_LED_B
42 | PA9 | I/O | USART1_TX | UI_TX1_MGMT
43 | PA10 | I/O | USART1_RX | UI_RX1_MGMT
46 | PA13 | I/O | SYS_JTMS-SWDIO
47 | VCAP_2 | Power
48 | VDD | Power
49 | PA14 | I/O | SYS_JTCK-SWCLK
50 | PA15 | I/O | I2S3_WS | I2S_DACLRC
51 | PC10 | I/O | I2S3_CK | I2S_BCLK
52 | PC11 * | I/O | GPIO_Output | UI_STAT
54 | PD2 * | I/O | GPIO_Input | VOLUME_DOWN

Pin Number LQFP64 | Pin Name (function after reset) | Pin Type | Alternate Function(s) | Label
56 | PB4 | I/O | I2S3_ext_SD | I2S_ADCDAT
57 | PB5 | I/O | I2S3_SD | I2S_DACDAT
58 | PB6 | I/O | I2C1_SCL | UI_SCL1
59 | PB7 | I/O | I2C1_SDA | UI_SDA1
60 | BOOT0 | Boot
63 | VSS | Power
64 | VDD | Power

* The pin is affected with an I/O function

## 4. Clock Tree Configuration

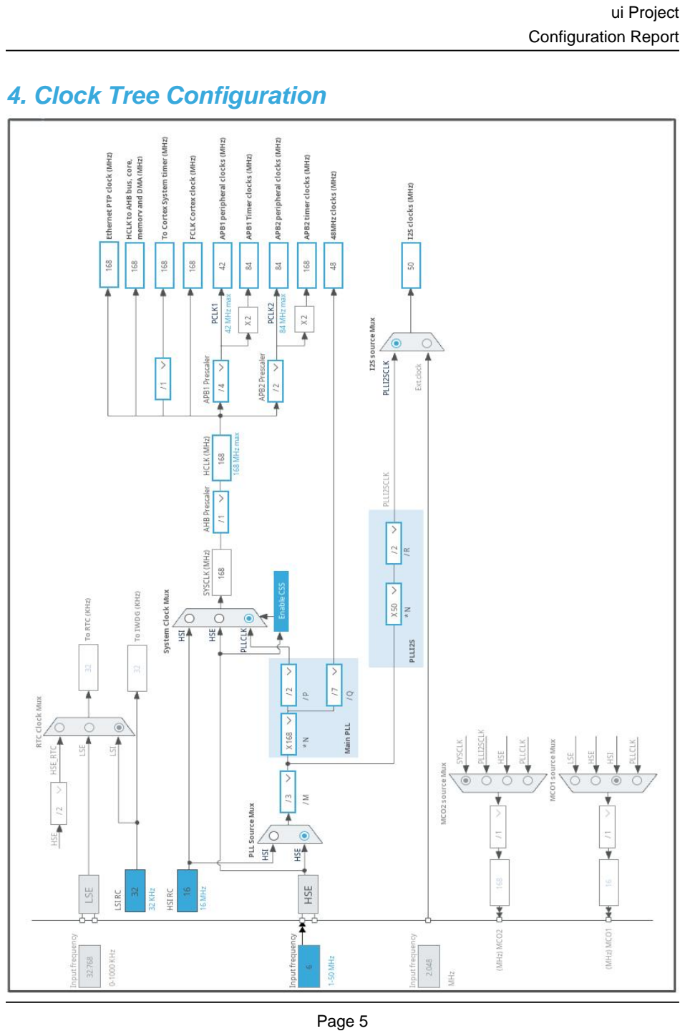
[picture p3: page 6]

## 1. Power Consumption Calculator report

### 1.1. Microcontroller Selection

Series | STM32F4
Line | STM32F405/415
MCU | STM32F405RGTx
Datasheet | DS8626_Rev8

### 1.2. Parameter Selection

Temperature | 25
Vdd | 3.3

### 1.3. Battery Selection

Battery | Li-SOCL2(A3400)
Capacity | 3400.0 mAh
Self Discharge | 0.08 %/month
Nominal Voltage | 3.6 V
Max Cont Current | 100.0 mA
Max Pulse Current | 200.0 mA
Cells in series | 1
Cells in parallel | 1

### 1.4. Sequence

Step | Step1 | Step2
Mode | RUN | STOP
Vdd | 3.3 | 3.3
Voltage Source | Battery | Battery
Range | Scale1-High | No Scale
Fetch Type | FLASH | n/a
CPU Frequency | 168 MHz | 0 Hz
Clock Configuration | HSE PLL | Regulator_LP Flash-PwrDwn
Clock Source Frequency | 4 MHz | 0 Hz
Peripherals
Additional Cons. | 0 mA | 0 mA
Average Current | 46 mA | 280 µA
Duration | 0.1 ms | 0.9 ms
DMIPS | 210.0 | 0.0
Ta Max | 98.02 | 104.96
Category | In DS Table | In DS Table

### 1.5. Results

Sequence Time | 1 ms | Average Current | 4.85 mA
Battery Life | 29 days, 4 hours | Average DMIPS | 210.0 DMIPS

### 1.6. Chart

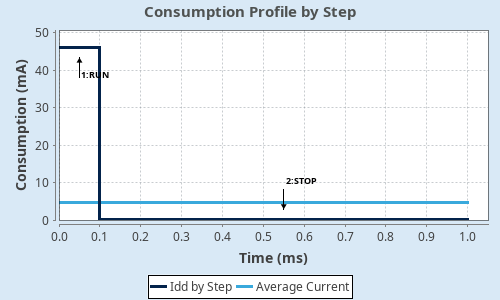
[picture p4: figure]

## 2. Software Project

### 2.1. Project Settings

Name | Value
Project Name | ui
Project Folder | /mnt/cisco/code/hactar/firmware/ui
Toolchain / IDE | CMake
Firmware Package Name and Version | STM32Cube FW_F4 V1.28.1
Application Structure | Advanced
Generate Under Root | No
Do not generate the main() | No
Minimum Heap Size | 0x200
Minimum Stack Size | 0x400

### 2.2. Code Generation Settings

Name | Value
STM32Cube MCU packages and embedded software | Copy all used libraries into the project folder
Generate peripheral initialization as a pair of '.c/.h' files | No
Backup previously generated files when re-generating | No
Keep User Code when re-generating | Yes
Delete previously generated files when not re-generated | Yes
Set all free pins as analog (to optimize the power consumption) | No
Enable Full Assert | No

### 2.3. Advanced Settings - Generated Function Calls

Rank | Function Name | Peripheral Instance Name
1 | SystemClock_Config | RCC
2 | MX_GPIO_Init | GPIO
3 | MX_DMA_Init | DMA
4 | MX_I2C1_Init | I2C1
5 | MX_I2S3_Init | I2S3
6 | MX_SPI1_Init | SPI1
7 | MX_USART1_UART_Init | USART1
8 | MX_USART2_UART_Init | USART2
9 | MX_TIM2_Init | TIM2
10 | MX_RNG_Init | RNG
11 | MX_CRC_Init | CRC

Rank | Function Name | Peripheral Instance Name
12 | MX_TIM3_Init | TIM3
13 | MX_TIM4_Init | TIM4
14 | MX_TIM5_Init | TIM5

## 3. Peripherals and Middlewares Configuration

### 3.1. CRC

mode: Activated

### 3.2. I2C1

I2C: I2C
3.2.1. Parameter Settings:

Master Features:

I2C Speed Mode | Standard Mode
I2C Clock Speed (Hz) | 100000
Slave Features:
Clock No Stretch Mode | Disabled
Primary Address Length selection | 7-bit
Dual Address Acknowledged | Disabled
Primary slave address | 0
General Call address detection | Disabled

### 3.3. I2S3

Mode: Full-Duplex Slave
3.3.1. Parameter Settings:

Generic Parameters:

Transmission Mode | Mode Slave Transmit
Communication Standard | I2S Philips
Data and Frame Format | 16 Bits Data on 32 Bits Frame *
Selected Audio Frequency | 8 KHz
Real Audio Frequency | 7.971 KHz *
Error between Selected and Real | -0.36 % *
Clock Parameters:
Clock Source | I2S PLL Clock
Clock Polarity | Low

### 3.4. RCC

High Speed Clock (HSE): BYPASS Clock Source
3.4.1. Parameter Settings:

System Parameters:

VDD voltage (V) | 3.3
Instruction Cache | Enabled
Prefetch Buffer | Enabled
Data Cache | Enabled
Flash Latency(WS) | 5 WS (6 CPU cycle)
RCC Parameters:
HSI Calibration Value | 16
HSE Startup Timout Value (ms) | 100
LSE Startup Timout Value (ms) | 5000
Power Parameters:
Power Regulator Voltage Scale | Power Regulator Voltage Scale 1

### 3.5. RNG

mode: Activated

### 3.6. SPI1

Mode: Full-Duplex Master
3.6.1. Parameter Settings:

Basic Parameters:

Frame Format | Motorola
Data Size | 8 Bits
First Bit | MSB First
Clock Parameters:
Prescaler (for Baud Rate) | 2
Baud Rate | 42.0 MBits/s *
Clock Polarity (CPOL) | Low
Clock Phase (CPHA) | 1 Edge
Advanced Parameters:
CRC Calculation | Disabled
NSS Signal Type | Software

### 3.7. SYS

Debug: Serial Wire
Timebase Source: SysTick

### 3.8. TIM2

Clock Source : Internal Clock
3.8.1. Parameter Settings:

Counter Settings:

Prescaler (PSC - 16 bits value) | 16800 *
Counter Mode | Up
Counter Period (AutoReload Register - 32 bits value ) | 200 *
Internal Clock Division (CKD) | No Division
auto-reload preload | Disable
Trigger Output (TRGO) Parameters:
Master/Slave Mode (MSM bit) | Disable (Trigger input effect not delayed)
Trigger Event Selection | Reset (UG bit from TIMx_EGR)

### 3.9. TIM3

Clock Source : Internal Clock
Channel1: PWM Generation CH1 Channel2: PWM Generation CH2 Channel3: PWM Generation CH3 mode: One Pulse Mode
3.9.1. Parameter Settings:

Counter Settings:

Prescaler (PSC - 16 bits value) | 168 *
Counter Mode | Up
Counter Period (AutoReload Register - 16 bits value ) | 10 *
Internal Clock Division (CKD) | No Division
auto-reload preload | Disable
Trigger Output (TRGO) Parameters:
Master/Slave Mode (MSM bit) | Disable (Trigger input effect not delayed)
Trigger Event Selection | Reset (UG bit from TIMx_EGR)
PWM Generation Channel 1:
Mode | PWM mode 1

Pulse (16 bits value) | 0
Output compare preload | Enable
Fast Mode | Disable
CH Polarity | High
PWM Generation Channel 2:
Mode | PWM mode 1
Pulse (16 bits value) | 0
Output compare preload | Enable
Fast Mode | Disable
CH Polarity | High
PWM Generation Channel 3:
Mode | PWM mode 1
Pulse (16 bits value) | 0
Output compare preload | Enable
Fast Mode | Disable
CH Polarity | High

### 3.10. TIM4

mode: Clock Source
3.10.1. Parameter Settings:

Counter Settings:

Prescaler (PSC - 16 bits value) | 8399 *
Counter Mode | Up
Counter Period (AutoReload Register - 16 bits value ) | 4999 *
Internal Clock Division (CKD) | No Division
auto-reload preload | Disable
Trigger Output (TRGO) Parameters:
Master/Slave Mode (MSM bit) | Disable (Trigger input effect not delayed)
Trigger Event Selection | Reset (UG bit from TIMx_EGR)

### 3.11. TIM5

mode: Clock Source
3.11.1. Parameter Settings:

Counter Settings:

Prescaler (PSC - 16 bits value) | 8399 *

Counter Mode | Up
Counter Period (AutoReload Register - 32 bits value ) | 4999 *
Internal Clock Division (CKD) | No Division
auto-reload preload | Disable
Trigger Output (TRGO) Parameters:
Master/Slave Mode (MSM bit) | Disable (Trigger input effect not delayed)
Trigger Event Selection | Reset (UG bit from TIMx_EGR)

### 3.12. USART1

Mode: Asynchronous
3.12.1. Parameter Settings:

Basic Parameters:

Baud Rate | 115200
Word Length | 9 Bits (including Parity) *
Parity | Even *
Stop Bits | 1
Advanced Parameters:
Data Direction | Receive and Transmit
Over Sampling | 16 Samples

### 3.13. USART2

Mode: Asynchronous
3.13.1. Parameter Settings:

Basic Parameters:

Baud Rate | 460800 *
Word Length | 8 Bits (including Parity)
Parity | None
Stop Bits | 2 *
Advanced Parameters:
Data Direction | Receive and Transmit
Over Sampling | 16 Samples

* User modified value

## 4. System Configuration

### 4.1. GPIO configuration

IP | Pin | Signal | GPIO mode | GPIO pull/up pull down | Max Speed | User Label
I2C1 | PB6 | I2C1_SCL | Alternate Function Open Drain | No pull-up and no pull-down | Very High * | UI_SCL1
| PB7 | I2C1_SDA | Alternate Function Open Drain | No pull-up and no pull-down | Very High * | UI_SDA1
I2S3 | PA15 | I2S3_WS | Alternate Function Push Pull | No pull-up and no pull-down | Low | I2S_DACLRC
| PC10 | I2S3_CK | Alternate Function Push Pull | No pull-up and no pull-down | Low | I2S_BCLK
| PB4 | I2S3_ext_SD | Alternate Function Push Pull | No pull-up and no pull-down | Low | I2S_ADCDAT
| PB5 | I2S3_SD | Alternate Function Push Pull | No pull-up and no pull-down | Low | I2S_DACDAT
RCC | PH0-OSC_IN | RCC_OSC_IN | n/a | n/a | n/a | MCLK
| PH1-OSC_OUT | RCC_OSC_OUT | n/a | n/a | n/a | NC
SPI1 | PA5 | SPI1_SCK | Alternate Function Push Pull | No pull-up and no pull-down | Very High * | SPI1_CLK
| PA6 | SPI1_MISO | Alternate Function Push Pull | No pull-up and no pull-down | Very High *
| PA7 | SPI1_MOSI | Alternate Function Push Pull | No pull-up and no pull-down | Very High * | SPI1_MOSI
SYS | PA13 | SYS_JTMS-SWDIO | n/a | n/a | n/a
| PA14 | SYS_JTCK-SWCLK | n/a | n/a | n/a
TIM3 | PC6 | TIM3_CH1 | Alternate Function Push Pull | No pull-up and no pull-down | Low | UI_LED_R
| PC7 | TIM3_CH2 | Alternate Function Push Pull | No pull-up and no pull-down | Low | UI_LED_G
| PC8 | TIM3_CH3 | Alternate Function Push Pull | No pull-up and no pull-down | Low | UI_LED_B
USART1 | PA9 | USART1_TX | Alternate Function Push Pull | No pull-up and no pull-down | Very High * | UI_TX1_MGMT
| PA10 | USART1_RX | Alternate Function Push Pull | No pull-up and no pull-down | Very High * | UI_RX1_MGMT
USART2 | PA2 | USART2_TX | Alternate Function Push Pull | No pull-up and no pull-down | Very High * | UI_TX2_NET
| PA3 | USART2_RX | Alternate Function Push Pull | Pull-down * | Very High * | UI_RX2_NET
GPIO | PC15-OSC32_OU T | GPIO_Output | Output Push Pull | No pull-up and no pull-down | Low | UI_DEBUG_1

IP | Pin | Signal | GPIO mode | GPIO pull/up pull down | Max Speed | User Label
| PC0 | GPIO_Input | Input mode | Pull-up * | n/a | PTT_BTN
| PC1 | GPIO_Input | Input mode | Pull-up * | n/a | PTT_AI_BTN
| PC2 | GPIO_Output | Output Push Pull | No pull-up and no pull-down | Low | UI_READY
| PC3 | GPIO_EXTI3 | External Interrupt Mode with Rising edge trigger detection | No pull-up and no pull-down | n/a | NET_READY
| PA4 | GPIO_Input | Input mode | No pull-up and no pull-down | n/a | MIC_IO
| PB2 | GPIO_Input | Input mode | No pull-up and no pull-down | n/a | UI_BOOT1
| PB10 | GPIO_Input | Input mode | No pull-up and no pull-down | n/a | VOLUME_UP
| PC11 | GPIO_Output | Output Push Pull | Pull-down * | Medium * | UI_STAT
| PD2 | GPIO_Input | Input mode | No pull-up and no pull-down | n/a | VOLUME_DOWN

### 4.2. DMA configuration

DMA request | Stream | Direction | Priority
USART2_RX | DMA1_Stream5 | Peripheral To Memory | Very High *
USART2_TX | DMA1_Stream6 | Memory To Peripheral | Very High *
USART1_RX | DMA2_Stream5 | Peripheral To Memory | Low
USART1_TX | DMA2_Stream7 | Memory To Peripheral | Low
SPI3_TX | DMA1_Stream7 | Memory To Peripheral | High *
I2S3_EXT_RX | DMA1_Stream0 | Peripheral To Memory | High *
SPI1_RX | DMA2_Stream0 | Peripheral To Memory | Low
SPI1_TX | DMA2_Stream3 | Memory To Peripheral | Low

USART2_RX: DMA1_Stream5 DMA request Settings:

Mode: | Circular *
Use fifo: | Disable
Peripheral Increment: | Disable
Memory Increment: | Enable *
Peripheral Data Width: | Byte
Memory Data Width: | Byte

USART2_TX: DMA1_Stream6 DMA request Settings:

Mode: | Normal
Use fifo: | Disable
Peripheral Increment: | Disable
Memory Increment: | Enable *
Peripheral Data Width: | Byte
Memory Data Width: | Byte

USART1_RX: DMA2_Stream5 DMA request Settings:

Mode: | Circular *
Use fifo: | Disable
Peripheral Increment: | Disable
Memory Increment: | Enable *
Peripheral Data Width: | Byte
Memory Data Width: | Byte

USART1_TX: DMA2_Stream7 DMA request Settings:

Mode: | Normal
Use fifo: | Disable
Peripheral Increment: | Disable
Memory Increment: | Enable *
Peripheral Data Width: | Byte
Memory Data Width: | Byte

SPI3_TX: DMA1_Stream7 DMA request Settings:

Mode: | Circular *
Use fifo: | Disable
Peripheral Increment: | Disable
Memory Increment: | Enable *
Peripheral Data Width: | Half Word *
Memory Data Width: | Half Word *

I2S3_EXT_RX: DMA1_Stream0 DMA request Settings:

Mode: | Circular *
Use fifo: | Disable
Peripheral Increment: | Disable
Memory Increment: | Enable *
Peripheral Data Width: | Half Word *
Memory Data Width: | Half Word *

SPI1_RX: DMA2_Stream0 DMA request Settings:

Mode: | Normal
Use fifo: | Disable
Peripheral Increment: | Disable
Memory Increment: | Enable *
Peripheral Data Width: | Byte
Memory Data Width: | Byte

SPI1_TX: DMA2_Stream3 DMA request Settings:

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

### 4.3. NVIC configuration

4.3.1. NVIC
Interrupt Table | Enable | Preenmption Priority | SubPriority
Non maskable interrupt | true | 0 | 0
Hard fault interrupt | true | 0 | 0
Memory management fault | true | 0 | 0
Pre-fetch fault, memory access fault | true | 0 | 0
Undefined instruction or illegal state | true | 0 | 0
System service call via SWI instruction | true | 0 | 0
Debug monitor | true | 0 | 0
Pendable request for system service | true | 0 | 0
System tick timer | true | 15 | 0
RCC global interrupt | true | 0 | 0
DMA1 stream0 global interrupt | true | 0 | 0
DMA1 stream5 global interrupt | true | 1 | 0
DMA1 stream6 global interrupt | true | 1 | 0
TIM2 global interrupt | true | 0 | 0
TIM3 global interrupt | true | 0 | 0
TIM4 global interrupt | true | 0 | 0
SPI1 global interrupt | true | 0 | 0
USART1 global interrupt | true | 0 | 0
USART2 global interrupt | true | 0 | 0
DMA1 stream7 global interrupt | true | 0 | 0
TIM5 global interrupt | true | 0 | 0
SPI3 global interrupt | true | 0 | 0
DMA2 stream0 global interrupt | true | 0 | 0
DMA2 stream3 global interrupt | true | 0 | 0
DMA2 stream5 global interrupt | true | 1 | 0
DMA2 stream7 global interrupt | true | 1 | 0
PVD interrupt through EXTI line 16 | | unused
Flash global interrupt | | unused
EXTI line3 interrupt | | unused
I2C1 event interrupt | | unused
I2C1 error interrupt | | unused
HASH and RNG global interrupts | | unused
FPU global interrupt | | unused
4.3.2. NVIC Code generation

Enabled interrupt Table Select for init
sequence ordering
| | Generate IRQ
| | handler | Call HAL handler

Enabled interrupt Table | Select for init sequence ordering | Generate IRQ handler | Call HAL handler
Non maskable interrupt | false | true | false
Hard fault interrupt | false | true | false
Memory management fault | false | true | false
Pre-fetch fault, memory access fault | false | true | false
Undefined instruction or illegal state | false | true | false
System service call via SWI instruction | false | true | false
Debug monitor | false | true | false
Pendable request for system service | false | true | false
System tick timer | false | true | true
RCC global interrupt | false | true | false
DMA1 stream0 global interrupt | false | true | true
DMA1 stream5 global interrupt | false | true | true
DMA1 stream6 global interrupt | false | true | true
TIM2 global interrupt | false | true | true
TIM3 global interrupt | false | true | true
TIM4 global interrupt | false | true | true
SPI1 global interrupt | false | true | true
USART1 global interrupt | false | true | true
USART2 global interrupt | false | true | true
DMA1 stream7 global interrupt | false | true | true
TIM5 global interrupt | false | true | true
SPI3 global interrupt | false | true | true
DMA2 stream0 global interrupt | false | true | true
DMA2 stream3 global interrupt | false | true | true
DMA2 stream5 global interrupt | false | true | true
DMA2 stream7 global interrupt | false | true | true

* User modified value

## 5. System Views

5.1. Category view
5.1.1. Current

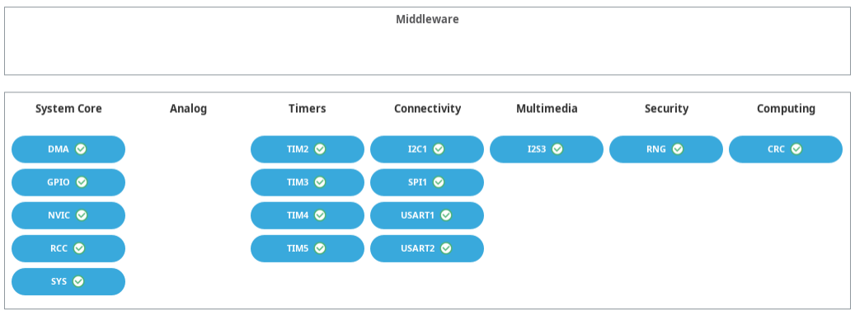
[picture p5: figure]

## 6. Docs & Resources

Type | Link
BSDL files | https://www.st.com/resource/en/bsdl_model/stm32f405-415_407-417_bsdl.zip
IBIS models | https://www.st.com/resource/en/ibis_model/stm32f405-415_407-417_ibis.zip
System View Description | https://www.st.com/resource/en/svd/stm32f4-svd.zip
Presentations | https://www.st.com/resource/en/product_presentation/stm32-stm8_embedded_software_solutions.pdf
Presentations | https://www.st.com/resource/en/product_presentation/stm32_eval-tools_portfolio.pdf
Presentations | https://www.st.com/resource/en/product_presentation/stm32_stm8_functi onal-safety-packages.pdf
Presentations | https://www.st.com/resource/en/product_presentation/stm32-stm8_software_development_tools.pdf
Presentations | https://www.st.com/resource/en/product_presentation/microcontrollers-stm32-family-overview.pdf
Brochures | https://www.st.com/resource/en/brochure/products-and-solutions-for-plcs-and-smart-i-os.pdf
Brochures | https://www.st.com/resource/en/brochure/expansion-boards-for-intelligent-power-switches.pdf
Flyers | https://www.st.com/resource/en/flyer/flstm32nucleo.pdf
Flyers | https://www.st.com/resource/en/flyer/flstm32trust.pdf
Product Certifications | https://www.st.com/resource/en/certification_document/stm32_authentication_can.pdf
Security Bulletin | https://www.st.com/resource/en/technical_note/tn1489-security-bulletin-tn1489stpsirt-physical-attacks-on-stm32-and-stm32cube-firmware-stmicroelectronics.pdf
Application Notes | https://www.st.com/resource/en/application_note/an1709-emc-design-guide-for-stm8-stm32-and-legacy-mcus-stmicroelectronics.pdf

Application Notes | https://www.st.com/resource/en/application_note/an2945-stm8s-and-stm32-mcus-a-consistent-832bit-product-line-for-painless-migration-stmicroelectronics.pdf
Application Notes | https://www.st.com/resource/en/application_note/an3070-managing-the-driver-enable-signal-for-rs485-and-iolink-communications-with-the-stm32s-usart-stmicroelectronics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
Application Notes | https://www.st.com/resource/en/application_note/an3126-audio-and-waveform-generation-using-the-dac-in-stm32-products-stmicroelectronics.pdf
Application Notes | https://www.st.com/resource/en/application_note/an3155-usart-protocol-used-in-the-stm32-bootloader-stmicroelectronics.pdf
Application Notes | https://www.st.com/resource/en/application_note/an3156-usb-dfu-protocol-used-in-the-stm32-bootloader-stmicroelectronics.pdf
Application Notes | https://www.st.com/resource/en/application_note/an3364-migration-and-compatibility-guidelines-for-stm32-microcontroller-applications-stmicroelectronics.pdf
Application Notes | https://www.st.com/resource/en/application_note/an3371-using-the-hardware-realtime-clock-rtc-in-stm32-f0-f2-f3-f4-and-l1-series-of-mcus-stmicroelectronics.pdf
Application Notes | https://www.st.com/resource/en/application_note/an3997-audio-playback-and-recording-using-the-stm32f4discovery-stmicroelectronics.pdf
Application Notes | https://www.st.com/resource/en/application_note/an3998-pdm-audio-software-decoding-on-stm32-microcontrollers-stmicroelectronics.pdf
Application Notes | https://www.st.com/resource/en/application_note/an4031-using-the-stm32f2-stm32f4-and-stm32f7-series-dma-controller-stmicroelectronics.pdf
Application Notes | https://www.st.com/resource/en/application_note/an4073-how-to-improve-adc-accuracy-when-using-stm32f2xx-and-stm32f4xx-microcontrollers-stmicroelectronics.pdf
Application Notes | https://www.st.com/resource/en/application_note/an4076-two-or-three-shunt-resistor-based-current-sensing-circuit-design-in-3phase-inverters-stmicroelectronics.pdf
Application Notes | https://www.st.com/resource/en/application_note/an4221-i2c-protocol-used-in-the-stm32-bootloader-stmicroelectronics.pdf

Application Notes | https://www.st.com/resource/en/application_note/an4286-spi-protocol-used-in-the-stm32-bootloader-stmicroelectronics.pdf
Application Notes | https://www.st.com/resource/en/application_note/an4488-getting-started-with-stm32f4xxxx-mcu-hardware-development-stmicroelectronics.pdf
Application Notes | https://www.st.com/resource/en/application_note/an4640-peripherals-interconnections-on-stm32f4057xx-stm32f4157xx-stm32f42xxx-stm32f43xxx-stm32f446xx-and-stm32f469479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
Application Notes | https://www.st.com/resource/en/application_note/an4655-virtually-increasing-the-number-of-serial-communication-peripherals-in-stm32-applications-stmicroelectronics.p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
Application Notes | https://www.st.com/resource/en/application_note/an4739-stm32cube-firmware-examples-for-stm32f4-series-stmicroelectronics.pdf
Application Notes | https://www.st.com/resource/en/application_note/an4750-handling-of-soft-errors-in-stm32-applications-stmicroelectronics.pdf
Application Notes | https://www.st.com/resource/en/application_note/an4776-generalpurpose-timer-cookbook-for-stm32-microcontrollers-stmicroelectronics.pdf
Application Notes | https://www.st.com/resource/en/application_note/an4803-highspeed-si-simulations-using-ibis-and-boardlevel-simulations-using-hyperlynx-si-on-stm32-mcus-and-mpus-stmic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
Application Notes | https://www.st.com/resource/en/application_note/an4821-migrating-from-stm32f405415-line-and-stm32f407417-line-to-stm32l4-series-and-stm32l4-series-microcontrollers-s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
Application Notes | https://www.st.com/resource/en/application_note/an4850-stm32-mcus-spreadspectrum-clock-generation-principles-properties-and-implementation-stmicroelectronics.pdf
Application Notes | https://www.st.com/resource/en/application_note/an4989-stm32-microcontroller-debug-toolbox-stmicroelectronics.pdf
Application Notes | https://www.st.com/resource/en/application_note/an4995-using-an-electromyogram-technique-to-detect-muscle-activity-stmicroelectronics.pdf
Application Notes | https://www.st.com/resource/en/application_note/an5027-interfacing-pdm-digital-microphones-using-stm32-mcus-and-mpus-stmicroelectronics.pdf
Application Notes | https://www.st.com/resource/en/application_note/an5073-receiving-spdif-

| audio-stream-with-the-stm32f4f7h7-series-stmicroelectronics.pdf
Application Notes | https://www.st.com/resource/en/application_note/an4899-stm32-microcontroller-gpio-hardware-settings-and-lowpower-consumption-stmicroelectronics.pdf
Application Notes | https://www.st.com/resource/en/application_note/an5612-esd-protection-of-stm32-mcus-and-mpus-stmicroelectronics.pdf
Application Notes | https://www.st.com/resource/en/application_note/an4838-introduction-to-memory-protection-unit-management-on-stm32-mcus-stmicroelectronics.pdf
Application Notes | https://www.st.com/resource/en/application_note/an4879-introduction-to-usb-hardware-and-pcb-guidelines-using-stm32-mcus-stmicroelectronics.pdf
Application Notes | https://www.st.com/resource/en/application_note/an5225-introduction-to-usb-typec-power-delivery-for-stm32-mcus-and-mpus-stmicroelectronics.pdf
Application Notes | https://www.st.com/resource/en/application_note/an5537-how-to-use-adc-oversampling-techniques-to-improve-signaltonoise-ratio-on-stm32-mcus-stmicroelectronics.pdf
Application Notes | https://www.st.com/resource/en/application_note/an5036-guidelines-for-thermal-management-on-stm32-applications-stmicroelectronics.pdf
Application Notes | https://www.st.com/resource/en/application_note/an4230-introduction-to-random-number-generation-validation-using-the-nist-statistical-test-suite-for-stm32-mcus-and-m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
Application Notes | https://www.st.com/resource/en/application_note/an2867-guidelines-for-oscillator-design-on-stm8afals-and-stm32-mcusmpus-stmicroelectronics.pdf
Application Notes | https://www.st.com/resource/en/application_note/an4013-introduction-to-timers-for-stm32-mcus-stmicroelectronics.pdf
Application Notes | https://www.st.com/resource/en/application_note/an4277-how-to-use-pwm-shutdown-for-motor-control-and-digital-power-conversion-on-stm32-mcus-stmicroelectronics.pdf
Application Notes | https://www.st.com/resource/en/application_note/an4759-introduction-to-using-the-hardware-realtime-clock-rtc-and-the-tamper-management-unit-tamp-with-stm32-mcus-stmi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

Application Notes | https://www.st.com/resource/en/application_note/an4908-getting-started-with-usart-automatic-baud-rater-detection-for-stm32-mcus-stmicroelectronics.pdf
Application Notes | https://www.st.com/resource/en/application_note/an5156-introduction-to-security-for-stm32-mcus-stmicroelectronics.pdf
Application Notes | https://www.st.com/resource/en/application_note/an5543-guidelines-for-enhanced-spi-communication-on-stm32-mcus-and-mpus-stmicroelectronics.pdf
Application Notes | https://www.st.com/resource/en/application_note/cd00211314-how-to-optimize-the-adc-accuracy-in-the-stm32-mcus-stmicroelectronics.pdf
Application Notes | https://www.st.com/resource/en/application_note/an2639-soldering-recommendations-and-package-information-for-leadfree-ecopack2-mcus-and-mpus-stmicroelectronics.pdf
Application Notes | https://www.st.com/resource/en/application_note/an3154-how-to-use-can-protocol-in-bootloader-on-stm32-mcus-stmicroelectronics.pdf
Application Notes | https://www.st.com/resource/en/application_note/an4566-how-to-extend-the-dac-performance-on-stm32-mcus-stmicroelectronics.pdf
Application Notes | https://www.st.com/resource/en/application_note/an5647-the-goertzel-algorithm-to-compute-individual-terms-of-the-discrete-fourier-transform-dft-in-stm32-products-stm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
Application Notes | https://www.st.com/resource/en/application_note/an2606-introduction-to-system-memory-boot-mode-on-stm32-mcus-stmicroelectronics.pdf
Application Notes for related Tools & Software | https://www.st.com/resource/en/application_note/an2656-stm32f10xxx-lcd-glass-driver-firmware-stmicroelectronics.pdf
Application Notes for related Tools & Software | https://www.st.com/resource/en/application_note/an2790-tft-lcd-interfacing-with-the-highdensity-stm32f10xxx-fsmc-stmicroelectronics.pdf
Application Notes for related Tools & Software | https://www.st.com/resource/en/application_note/an3078-stm32-inapplication-programming-over-the-ic-bus-stmicroelectronics.pdf
Application Notes for related Tools & Software | https://www.st.com/resource/en/application_note/an3116-stm32s-adc-modes-and-their-applications-stmicroelectronics.pdf

Application Notes for related Tools & Software | https://www.st.com/resource/en/application_note/an3174-implementing-receivers-for-infrared-remote-control-protocols-using-stm32f10xxx-microcontrollers-stmicroelectro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
Application Notes for related Tools & Software | https://www.st.com/resource/en/application_note/an3241-qvga-tftlcd-direct-drive-using-the-stm32f10xx-fsmc-peripheral-stmicroelectronics.pdf
Application Notes for related Tools & Software | https://www.st.com/resource/en/application_note/an3307-guidelines-for-obtaining-iec-60335-class-b-certification-for-any-stm32-application-stmicroelectronics.pdf
Application Notes for related Tools & Software | https://www.st.com/resource/en/application_note/an3364-migration-and-compatibility-guidelines-for-stm32-microcontroller-applications-stmicroelectronics.pdf
Application Notes for related Tools & Software | https://www.st.com/resource/en/application_note/an3965-stm32f40xstm32f41x-inapplication-programming-using-the-usart-stmicroelectronics.pdf
Application Notes for related Tools & Software | https://www.st.com/resource/en/application_note/an3969-eeprom-emulation-in-stm32f40xstm32f41x-microcontrollers-stmicroelectronics.pdf
Application Notes for related Tools & Software | https://www.st.com/resource/en/application_note/an3988-clock-configuration-tool-for-stm32f40xx41xx427x437x-microcontrollers-stmicroelectronics.pdf
Application Notes for related Tools & Software | https://www.st.com/resource/en/application_note/an3990-upgrading-stm32f4discovery-board-firmware-using-a-usb-key-stmicroelectronics.pdf
Application Notes for related Tools & Software | https://www.st.com/resource/en/application_note/an3997-audio-playback-and-recording-using-the-stm32f4discovery-stmicroelectronics.pdf
Application Notes for related Tools & Software | https://www.st.com/resource/en/application_note/an3998-pdm-audio-software-decoding-on-stm32-microcontrollers-stmicroelectronics.pdf
Application Notes for related Tools & Software | https://www.st.com/resource/en/application_note/an4044-floating-point-unit-demonstration-on-stm32-microcontrollers-stmicroelectronics.pdf
Application Notes | https://www.st.com/resource/en/application_note/an4323-getting-started-

for related Tools & Software | with-stemwin-library-stmicroelectronics.pdf
Application Notes for related Tools & Software | https://www.st.com/resource/en/application_note/an4365-using-stm32f4-mcu-power-modes-with-best-dynamic-efficiency-stmicroelectronics.pdf
Application Notes for related Tools & Software | https://www.st.com/resource/en/application_note/an4435-guidelines-for-obtaining-ulcsaiec-607301603351-class-b-certification-in-any-stm32-application-stmicroelectroni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
Application Notes for related Tools & Software | https://www.st.com/resource/en/application_note/an4457-implementing-an-emulated-uart-on-stm32f4-microcontrollers-stmicroelectronics.pdf
Application Notes for related Tools & Software | https://www.st.com/resource/en/application_note/an4499-stm32--nrf51822-bluetooth-low-energy-system-solution-stmicroelectronics.pdf
Application Notes for related Tools & Software | https://www.st.com/resource/en/application_note/an4657-stm32-inapplication-programming-iap-using-the-usart-stmicroelectronics.pdf
Application Notes for related Tools & Software | https://www.st.com/resource/en/application_note/an4666-parallel-synchronous-transmission-using-gpio-and-dma-stmicroelectronics.pdf
Application Notes for related Tools & Software | https://www.st.com/resource/en/application_note/an4678-full-duplex-spi-emulation-for-stm32f4-microcontrollers-stmicroelectronics.pdf
Application Notes for related Tools & Software | https://www.st.com/resource/en/application_note/an4701-proprietary-code-readout-protection-on-microcontrollers-of-the-stm32f4-series-stmicroelectronics.pdf
Application Notes for related Tools & Software | https://www.st.com/resource/en/application_note/an4739-stm32cube-firmware-examples-for-stm32f4-series-stmicroelectronics.pdf
Application Notes for related Tools & Software | https://www.st.com/resource/en/application_note/an4758-proprietary-code-readout-protection-on-stm32l4-stm32l4-stm32g4-and-stm32wb-series-mcus-stmicroelectronics.pdf

Application Notes
for related Tools

https://www.st.com/resource/en/application_note/an4841-digital-signalprocessing-for-stm32-microcontrollers-using-cmsis-stmicroelectronics.pdf

& Software
Application Notes for related Tools & Software | https://www.st.com/resource/en/application_note/an4968-proprietary-code-read-out-protection-pcrop-on-stm32f72xxx-and-stm32f73xxx-microcontrollers-stmicroelectronics.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
Application Notes for related Tools & Software | https://www.st.com/resource/en/application_note/an5056-integration-guide-for-the-xcubesbsfu-stm32cube-expansion-package-stmicroelectronics.pdf
Application Notes for related Tools & Software | https://www.st.com/resource/en/application_note/an5360-getting-started-with-projects-based-on-the-stm32mp1-series-in-stm32cubeide-stmicroelectronics.pdf
Application Notes for related Tools & Software | https://www.st.com/resource/en/application_note/an5361-getting-started-with-projects-based-on-dualcore-stm32h7-microcontrollers-in-stm32cubeide-stmicroelectronics.pd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
Application Notes for related Tools & Software | https://www.st.com/resource/en/application_note/an5394-getting-started-with-projects-based-on-the-stm32l5-series-in-stm32cubeide-stmicroelectronics.pdf
Application Notes for related Tools & Software | https://www.st.com/resource/en/application_note/an5418-how-to-build-a-simple-usbpd-sink-application-with-stm32cubemx-stmicroelectronics.pdf
Application Notes for related Tools & Software | https://www.st.com/resource/en/application_note/an5426-migrating-graphics-middleware-projects-from-stm32cubemx-540-to-stm32cubemx-550-stmicroelectronics.pdf
Application Notes for related Tools & Software | https://www.st.com/resource/en/application_note/an5464-position-control-of-a-threephase-permanent-magnet-motor-using-xcubemcsdk-or-xcubemcsdkful-stmicroelectronics.p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
Application Notes for related Tools & Software | https://www.st.com/resource/en/application_note/an5564-getting-started-with-projects-based-on-dualcore-stm32wl-microcontrollers-in-stm32cubeide-stmicroelectronics.pd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
Application Notes for related Tools & Software | https://www.st.com/resource/en/application_note/an5698-adapting-the-xcubestl-functional-safety-package-for-stm32-iec-61508-compliant-to-other-safety-standards-stmicr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
Application Notes for related Tools & Software | https://www.st.com/resource/en/application_note/an5731-stm32cubemx-and-stm32cubeide-threadsafe-solution-stmicroelectronics.pdf

Application Notes for related Tools & Software | https://www.st.com/resource/en/application_note/an4502-stm32-smbuspmbus-expansion-package-for-stm32cube-stmicroelectronics.pdf
Application Notes for related Tools & Software | https://www.st.com/resource/en/application_note/an5952-how-to-use-cmake-in-stm32cubeide-stmicroelectronics.pdf
Application Notes for related Tools & Software | https://www.st.com/resource/en/application_note/an5054-how-to-perform-secure-programming-using-stm32cubeprogrammer-stmicroelectronics.pdf
Application Notes for related Tools & Software | https://www.st.com/resource/en/application_note/an6179-how-to-integrate-the-stl-firmware-into-a-time-critical-user-application-stmicroelectronics.pdf
Application Notes for related Tools & Software | https://www.st.com/resource/en/application_note/an6127-getting-started-with-stm32h7rx7sx-mcus-in-stm32cubeide-stmicroelectronics.pdf
Application Notes for related Tools & Software | https://www.st.com/resource/en/application_note/an6265-getting-started-with-stm32n6-mcus-in-stm32cubeide-stmicroelectronics.pdf
Errata Sheets | https://www.st.com/resource/en/errata_sheet/es0182-stm32f405407xx-and-stm32f415417xx-device-errata-stmicroelectronics.pdf
Datasheet | https://www.st.com/resource/en/datasheet/dm00037051.pdf
Programming Manuals | https://www.st.com/resource/en/programming_manual/pm0214-stm32-cortexm4-mcus-and-mpus-programming-manual-stmicroelectronics.pdf
Reference Manuals | https://www.st.com/resource/en/reference_manual/rm0090-stm32f405415-stm32f407417-stm32f427437-and-stm32f429439-advanced-armbased-32bit-mcus-stmicroelectronics.pdf
Technical Notes & Articles | https://www.st.com/resource/en/technical_note/tn0516-overview-of-the-stm32f0xf100xxf103xx-and-stm32f2xxf30xf4xx-mcus-pmsm-singledual-foc-sdk-v40-stmicroelectronics.p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
Technical Notes & Articles | https://www.st.com/resource/en/technical_note/tn1163-description-of-wlcsp-for-microcontrollers-and-recommendations-for-its-use-stmicroelectronics.pdf

Technical Notes
& Articles

https://www.st.com/resource/en/technical_note/tn1204-tape-and-reelshipping-media-for-stm32-microcontrollers-in-bga-packages-

| stmicroelectronics.pdf
Technical Notes & Articles | https://www.st.com/resource/en/technical_note/tn1205-tape-and-reel-shipping-media-for-stm8-and-stm32-microcontrollers-in-fpn-packages-stmicroelectronics.pdf
Technical Notes & Articles | https://www.st.com/resource/en/technical_note/tn1206-tape-and-reel-shipping-media-for-stm8-and-stm32-microcontrollers-in-qfp-packages-stmicroelectronics.pdf
Technical Notes & Articles | https://www.st.com/resource/en/technical_note/tn1207-tape-and-reel-shipping-media-for-stm8-and-stm32-microcontrollers-in-so-packages-stmicroelectronics.pdf
Technical Notes & Articles | https://www.st.com/resource/en/technical_note/tn1208-tape-and-reel-shipping-media-for-stm8-and-stm32-microcontrollers-in-tssop-and-ssop-packages-stmicroelectronics.p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
Technical Notes & Articles | https://www.st.com/resource/en/technical_note/tn1433-reference-device-marking-schematics-for-stm32-microcontrollers-and-microprocessors-stmicroelectronics.pdf
User Manuals | https://www.st.com/resource/en/user_manual/um3461-stm32f4-series-ulcsaiec-607301603351-selftest-library-user-guide-stmicroelectronics.pdf

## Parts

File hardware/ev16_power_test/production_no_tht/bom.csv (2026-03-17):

Designator | Footprint | Quantity | Value | LCSC Part #
C1, C13, C17, C21, C23, C25, C38, C39, C40, C41, C42, C43, C46, C47, C49, C50, C6, C8, C9 | 0402 | 19 | 100n | C1525
C10, C11, C14, C19, C22 | 0805 | 5 | 100n | C85866
C12, C4, C5 | 0402 | 3 | 10u | C307415
C15, C16 | 0805 | 2 | 10u | C17024
C18, C32, C36, C7 | 0402 | 4 | 1u | C52923
C2, C3 | 0805 | 2 | 33p | C107115
C20 | 0805 | 1 | 2p2 | C519933
C24, C27, C29, C30, C31, C35 | 0805 | 6 | 22u | C5674
C26, C28, C33, C37 | 0402 | 4 | 4u7 | C23733
C34, C48 | 1206 | 2 | 100u | C15008
C44, C45 | 0402 | 2 | 2u2 | C12530
CN1 | IDC-SMD_10P-P1.27_X1270WVS-2X05B-6TV01 | 1 | Conn_05x02_Female | C2962222
CN2 | AUDIO-SMD_PJ-242D-SMT | 1 | PJ-242 | C431536
D1 | 0805 | 1 | LED | C130114
D5 | LED-ARRAY-SMD_4P-L1.6-W1.5-TL_NH-B1515RGBA | 1 | LED_BGAR | C2874115
D7, D9 | LED-ARRAY-SMD_HS-1204-RGB | 2 | LED_BGAR | C965884
J1 | USB-C_SMD-TYPE-C-31-M-12 | 1 | USB_C_Receptacle | C165948
J11, J6, J7, J8, J9 | HDR-SMD_10P-P2.54-V-F-R2-C5-LS7.1-1 | 5 | Conn_02x05_Counter_Clockwise | C3975150
J2 | JST_PH_S2B-PH-SM4-TB_1x02-1MP_P2.00mm_Horizontal | 1 | Conn_01x02_Socket | C295747
J3 | AUDIO-SMD_PJ-320D | 1 | AudioJack4 | C431535
J4, J5 | HDR-SMD_6P-P2.54-V-M-R2-C3-LS7.5-2 | 2 | Conn_02x03_Odd_Even | C3294461
L2 | L_Coilcraft_XxL4020 | 1 | 1.5uH | C3033018
Q1, Q2, Q3 | SOT-23 | 3 | 2N7002 | C8545
R1 | 0402 | 1 | 680R | C25130
R10, R17, R24, R4, R40, R44, R45, R46, R49, R5, R50, R57, R58, R70, R71, R72, R73, R74, R9 | 0402 | 19 | 1k0 | C11702
R11, R16, R19 | 0402 | 3 | 1k5 | C25867
R12, R47, R6 | 0402 | 3 | 10k | C25744
R13, R29, R53 | 0402 | 3 | 15k | C25756
R14, R48, R52 | 0603 | 3 | 0R1 | C111027
R15, R33, R56 | 0402 | 3 | 180R | C25087
R18, R28, R32, R65, R75 | 0402 | 5 | 100k | C25741
R2, R22, R23, R30, R36, R37, R38, R39, R41, R42, R43, R51, R54, R55, R61, R62, R66, R67, R68, R69 | 0402 | 20 | 4k7 | C25900
R20, R21, R34, R35, R59, R60 | 0402 | 6 | 150R | C25082
R25, R3, R64 | 0402 | 3 | 47k | C25792
R26 | 0402 | 1 | 360k | C45956
R27 | 0402 | 1 | 64k9 | C26984
R31 | 0402 | 1 | 2k2 | C25879
R7, R8 | 0402 | 2 | 5k1 | C25905
SW2, SW3 | KEY-SMD_4P-L4.2-W3.2-P2.20-LS4.6 | 2 | SW_Push | C139797
SW4, SW5 | SW-SMD_4P-L5.1-W5.1-P3.70-LS6.5-TL_H1.5 | 2 | SW_Push | C318884
SW6, SW7 | SW-SMD_SHOU_TS36CA-0.6 | 2 | SW_Push | C2906288
U1 | SOT-23-6 | 1 | BQ21040DBV | C202311
U10 | LQFP-64_10x10mm_P0.5mm | 1 | STM32F405RGTx | C15742
U12 | SOT-23-5 | 1 | XC6227C301MR-G | C484285
U2 | SOT-666 | 1 | USBLC6-2P6 | C2827693
U3 | LQFP-48_7x7mm_P0.5mm | 1 | STM32F072CBTx | C80488
U4 | SOIC-16_3.9x9.9mm_P1.27mm | 1 | CH340C | C84681
U5 | Texas_S-PWSON-N10_ThermalVias | 1 | TPS63060 | C48567
U6 | QFN-32-1EP_5x5mm_P0.5mm_EP3.45x3.45mm_ThermalVias | 1 | WM8960CGEFL/RV | C18752
U7 | ESP32-S3-WROOM-1 | 1 | ESP32-S3-WROOM-1 | C2913204
U8 | SOIC-8_3.9x4.9mm_P1.27mm | 1 | M24C02-RMN6TP | C83836
U9 | SOT-583-8 | 1 | TPS2116DRL | C3235557
Y1 | Crystal_SMD_3225-4Pin_3.2x2.5mm | 1 | Crystal_GND24 | C13738

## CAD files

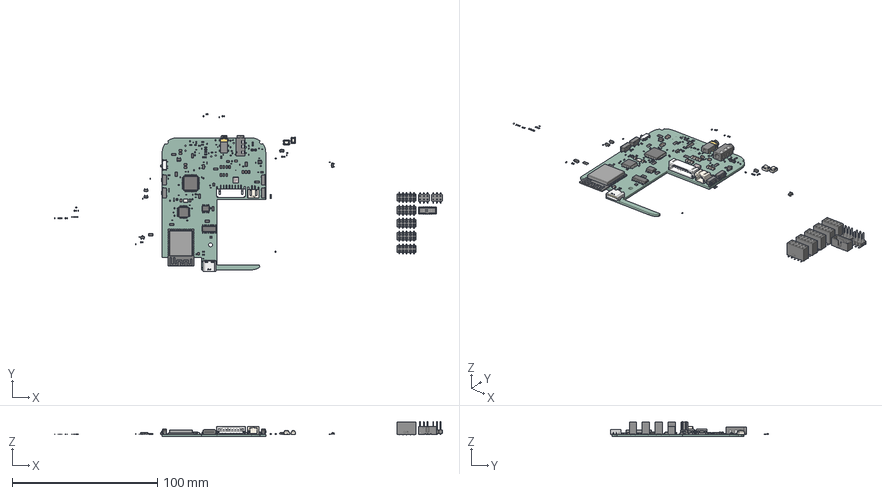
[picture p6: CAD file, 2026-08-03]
hardware/debug_board/.step
267.4 x 108.7 x 10.6 mm
SOIC-8_3.9x4.9mm_P1.27mm
C_0805_2012Metric x 19
R_1206_3216Metric x 11
R_0402_1005Metric x 79
SOT-23 x 6
C_0402_1005Metric x 42
ESP32-S3-WROOM-1
HDR-SMD_10P-P2.54-V-F-R2-C5-LS7.1-1 x 5
USB-C_SMD-TYPE-C-31-M-12
LQFP-48_7x7mm_P0.5mm
SOT-23-6
LED-ARRAY-SMD_4P-L1.6-W1.5-TL_NH-B1515RGBA x 3
HDR-SMD_6P-P2.54-V-M-R2-C3-LS7.5-2 x 2
SOT-23-5
R_0603_1608Metric x 4
KEY-SMD_4P-L4.2-W3.2-H2.5-LS4.6-P2.2 x 2
L_0402_1005Metric x 4
C_0603_1608Metric x 4
SW-SMD_SHOU_TS36CA-0.6 x 4
AUDIO-SMD_L12.1-W6.1-H5.0-4P
SOIC-16_3.9x9.9mm_P1.27mm
D_0805
IDC-SMD_10P-P1.27_X1270WVS-2X05B-6TV01
零件16
CONN-SMD_P2.00_S2B-PH-SM4-TB-LF-SN
LQFP-64_10x10mm_P0.5mm
SOT_666
Crystal_SMD_3225-4Pin_3.2x2.5mm
AUDIO-SMD_L10.5-W5.0-H3.2
S8B-PH-SM4-TB(LF)(SN)
SOT-583-8
ev19-unsaved-export-IkgWtF_PCB

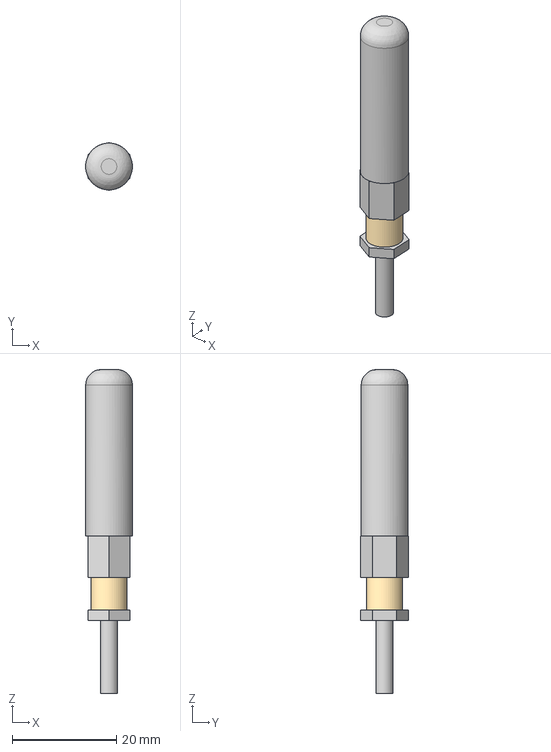
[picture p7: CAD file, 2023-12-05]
models/antenna/Antenna.stp
9.00 x 9.24 x 62.2 mm

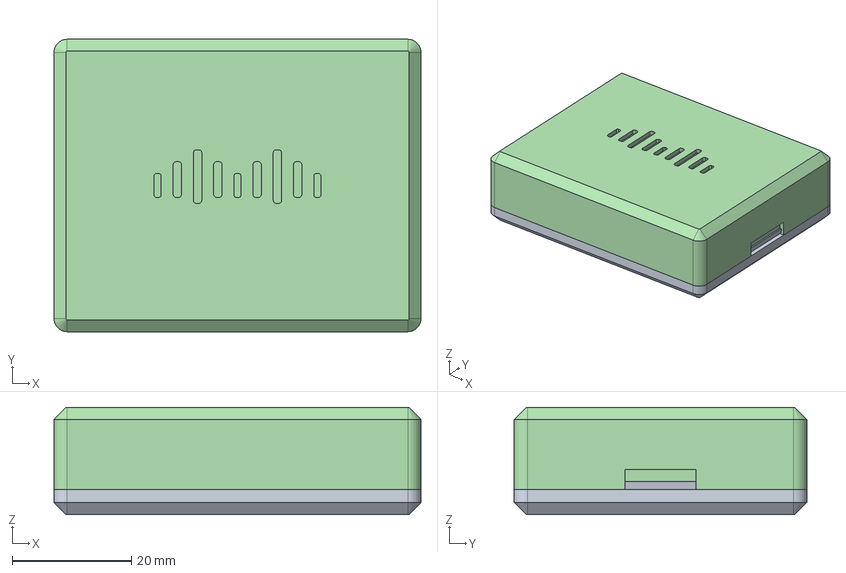
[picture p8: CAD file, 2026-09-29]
models/debug_board_case/debug-board-case.FCStd
61.6 x 49.1 x 18.0 mm
bottom
IDC-SMD_10P-P1.27_X1270WVS-2X05B-6TV01
lock
pins
PinHeader_2x03_P254mm_Vertical_SMD
PinHeader_2x17_P254mm_Vertical_SMD
PinHeader_2x17_P254mm_Vertical_SMD001
PinSocket_2x05_P2.54mm_Vertical_SMD
debug_board-unsaved-export-d8EK0W_silkscreen
debug_board-unsaved-export-d8EK0W_PCB
top

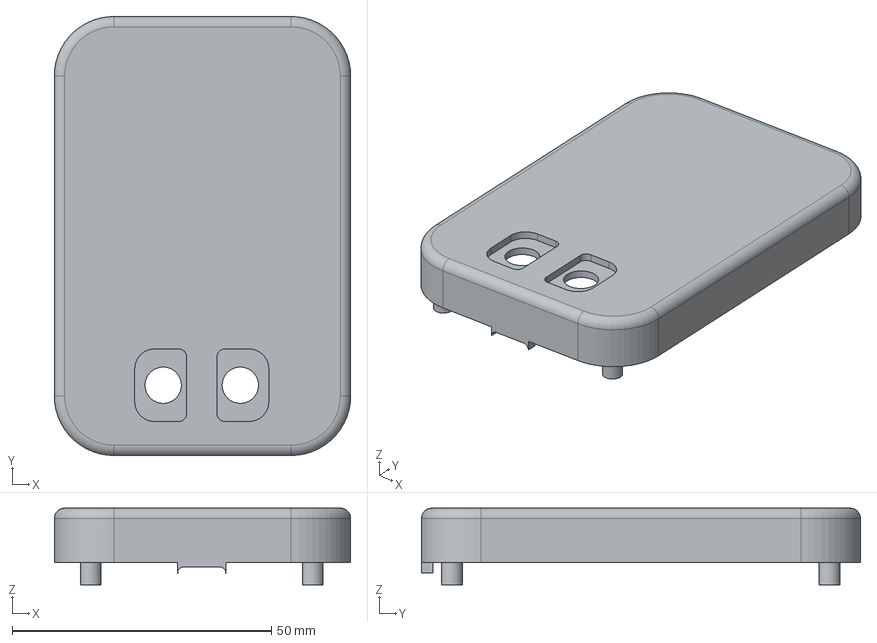
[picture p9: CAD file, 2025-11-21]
models/ev15/brett_model/demo/demo-ev15-case-top-screenless.step
57.2 x 84.7 x 14.8 mm

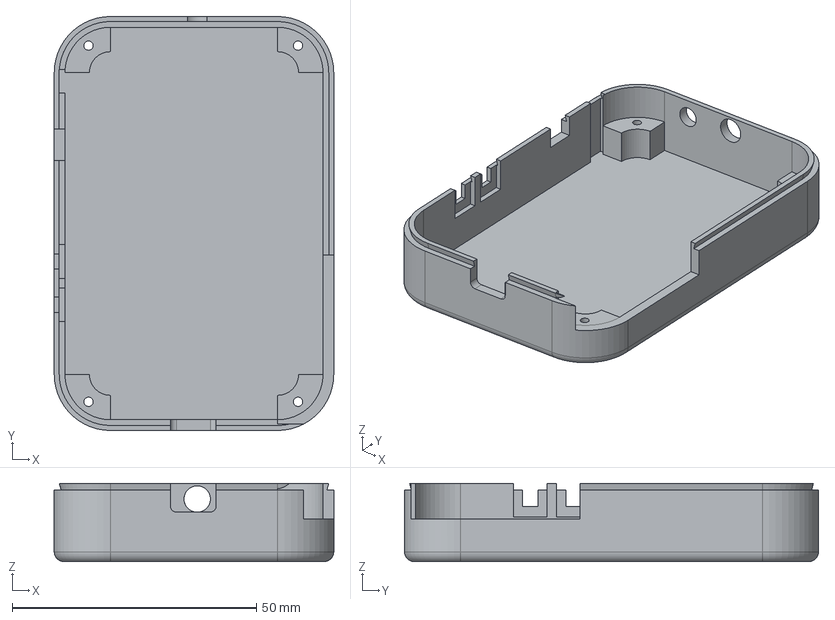
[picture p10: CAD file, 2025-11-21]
models/ev15/brett_model/step/dev-ev15-case-bottom.step
57.2 x 84.7 x 16.0 mm

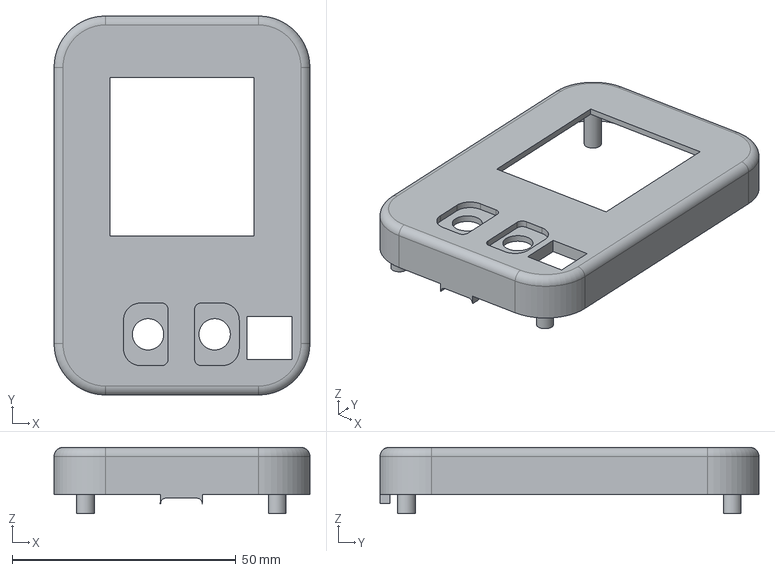
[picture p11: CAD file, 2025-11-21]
models/ev15v2/case-steps/ev15-case-top-screen-dev.step
57.2 x 84.7 x 14.8 mm

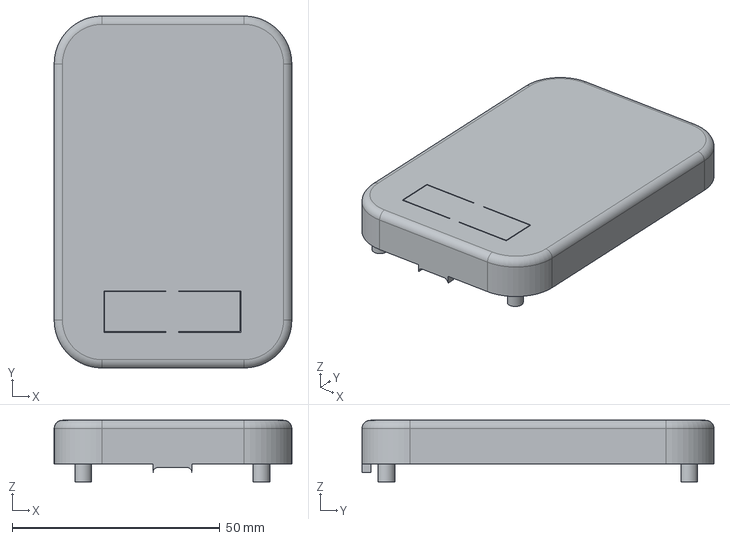
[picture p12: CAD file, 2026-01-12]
models/ev15v2/ev15-case-top-screenless.step
57.2 x 84.7 x 14.8 mm

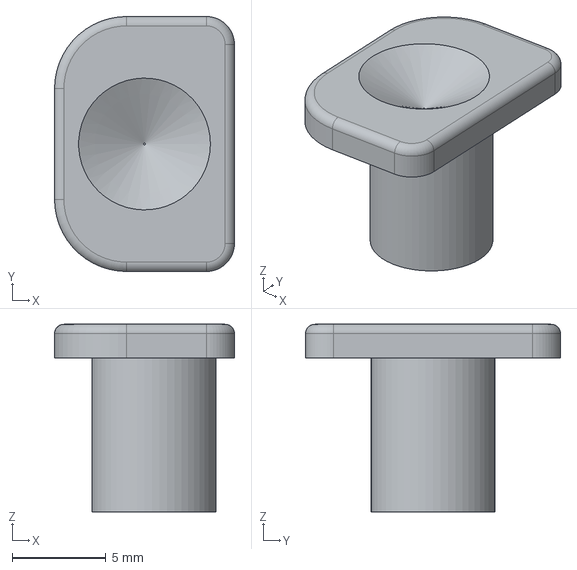
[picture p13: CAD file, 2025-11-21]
models/ev15v2/front-buttons-steps/ev15-case-front-button-divot.step
9.60 x 13.6 x 10.0 mm

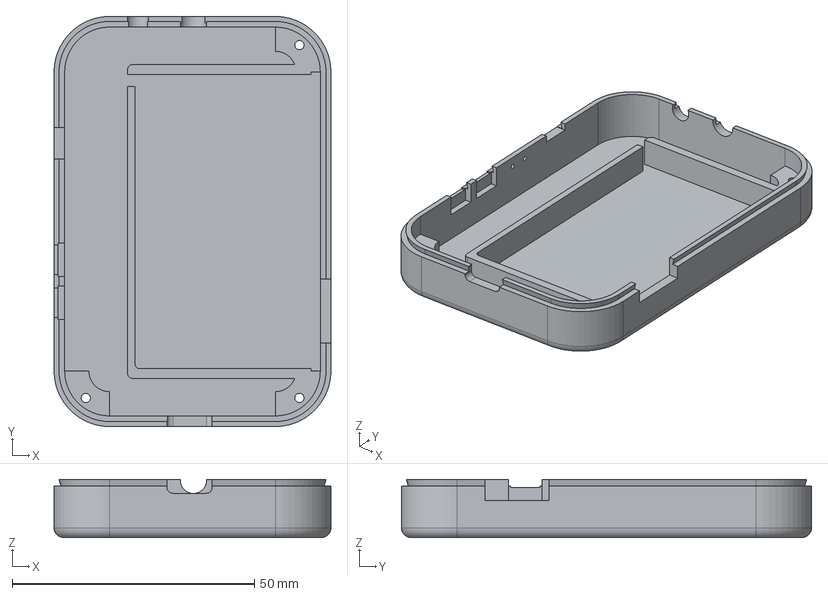
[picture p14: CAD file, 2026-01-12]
models/ev16/ev16-case-bottom-dev.step
57.2 x 84.7 x 12.0 mm

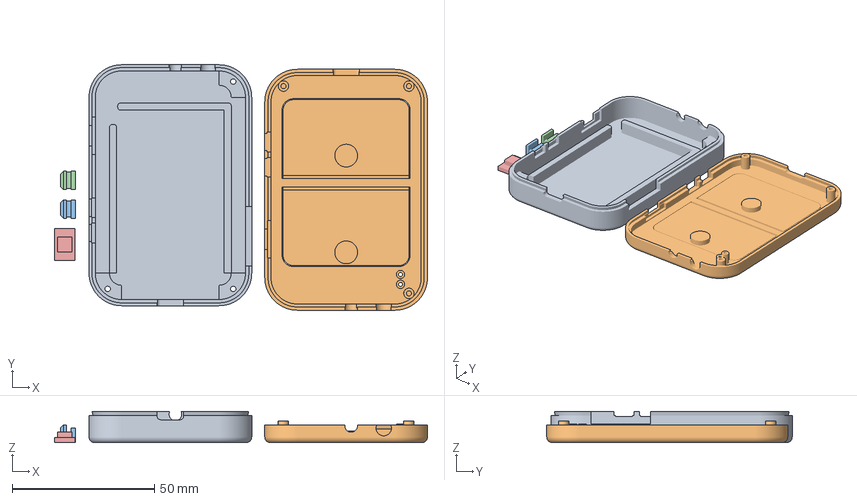
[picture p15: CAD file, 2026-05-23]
models/ev17/ev17-case.3mf
131.1 x 86.3 x 11.0 mm
ev17-case-bottom.step
ev17-case-top.step
ev17-case-side-buttons.step x 2
ev17-case-power-switch.step

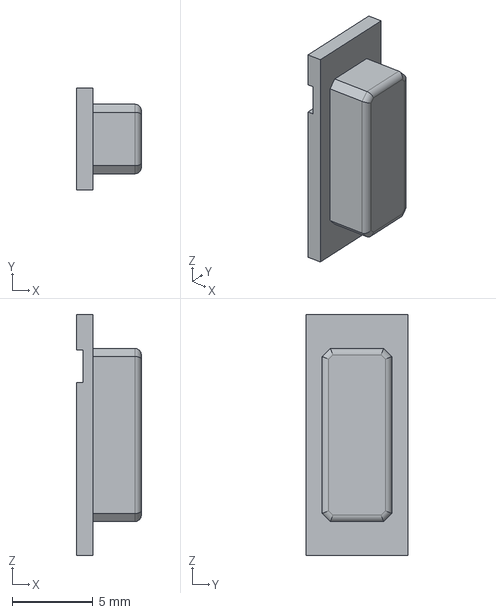
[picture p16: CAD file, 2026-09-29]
models/ev19/keytar/ev19-keytar-case-side-buttons.step
4.00 x 6.30 x 14.9 mm

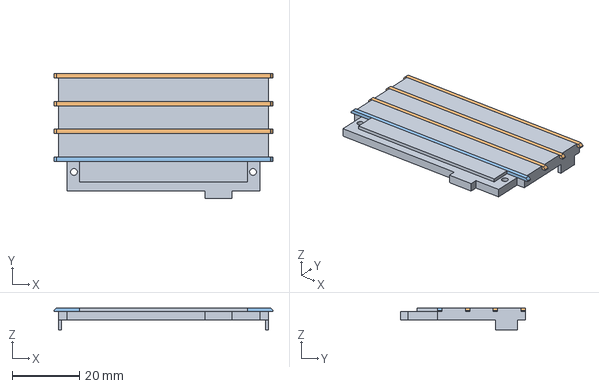
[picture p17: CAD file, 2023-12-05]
models/keyboard/keyboard.stp
65.2 x 37.1 x 6.50 mm

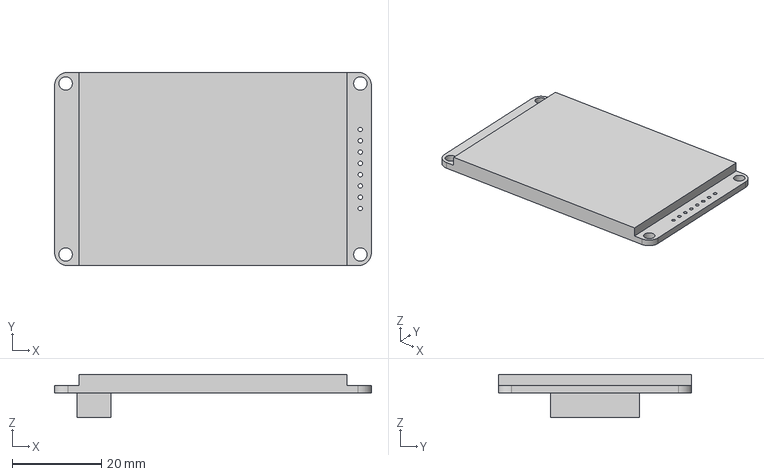
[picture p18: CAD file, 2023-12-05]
models/lcd/lcd.stp
71.0 x 43.3 x 9.67 mm

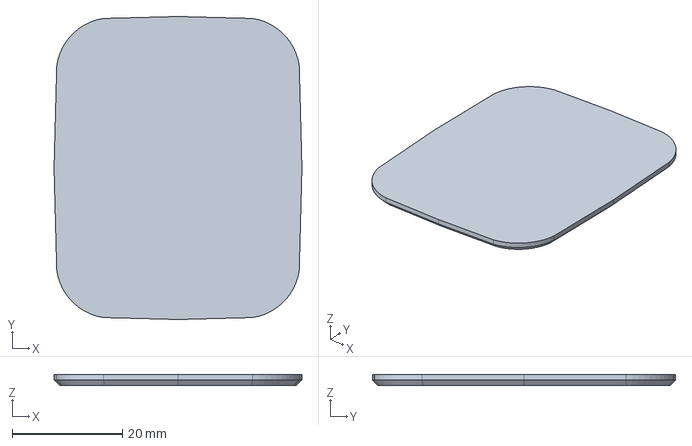
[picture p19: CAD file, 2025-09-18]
models/lcd_cover_glass/lcd_cover_glass.FCStd
45.0 x 55.0 x 2.00 mm

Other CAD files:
hardware/ev19/ev19.step
models/debug_board_case/debug-board-case-top.step
models/ev15/brett_model/demo/demo-ev15-case-top.step
models/debug_board_case/debug-board-case-bottom.step
models/ev15/brett_model/demo/demo-ev15-case-bottom.step
models/ev15/brett_model/demo/ev15-case-front-button.step
models/ev15/brett_model/demo/ev15-case-screen-platform.step
models/ev15/brett_model/demo/ev15-case-top-screenless.step
models/ev15/brett_model/step/dev-ev15-case-top.step
models/ev15v2/case-steps/ev15-case-bottom-demo.step
models/ev15v2/case-steps/ev15-case-bottom-dev.step
models/ev15v2/case-steps/ev15-case-screen-platform.step
models/ev15v2/case-steps/ev15-case-top-screen-demo.step
models/ev15v2/case-steps/ev15-case-top-screenless-demo.step
models/ev15v2/case-steps/ev15-case-top-screenless-dev.step
models/ev15v2/ev15-case-topPad051.step
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

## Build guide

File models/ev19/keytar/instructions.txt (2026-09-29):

Print collection:
1 ev19-keytar-case-top.step
1 ev19-keytar-case-bottom.step
1 ev19-keytar-case-keyboard-shim.step
1 ev19-keytar-case-shelf.step
1 ev19-keytar-case-power-switch.step
4 ev19-keytar-case-side-buttons.step

How to print: 
- Print everything flat
- supports should be enabled only for the bottom half of the case 
- Bambu labs 0.20mm Standard @BBL X1C
- Let er rip!

What you need:
2 M1.4x3 for keyboard to shim.
6 M2x4 for screen to shelf and shim to shelf.
4 M2x14 or M2x15 to close the case. 
Electrical tape 
Precision acrew driver

Steps: 
1. Using the 2 M1.4x3 screws attach the keyboard to the shim at the bottom with the two screw holes.
2. Using 2 M2x4 screws attach the shim to the shelf.
3. Position the screen and attach using 4 M2x4 screws
4. Plug in the screen connectors other end into the EV19 board.
5. Bend the cables enough out of the way that the battery can slip under.
6. Flip over the shelf and run the screen cable very sharply into the cable management channel. Once run, add electrical tape to hold the cable in the channel.
7. Plug in the battery to the EV19 board
8. Tape battery cable flat on top of the battery.
9. Attach the power switch 3D print to the power switch such that the little hole will be near the bottom of the EV19 board.
10. Put EV19 board, power switch, and battery into the bottom of the case. The battery cable should be coming out of the battery on the left hand side with the battery protection circuit face up.
11. Put all 4 buttons into the button imprints on the left and right side of the case.
12. Add some electrical tape to the outside of the buttons and power switch to hold them in place while you finangle. 
13. Carefully place the shelf into the bottom of the case, the pegs should align to the screw holes on the board. 
14. Carefully place the top onto the bottom+shelf make sure the buttons and the power switch are aligned to the holes.
15. Tightly hold the top and bottom case closed and use 4 M2x14 or M2x15 screws to attach the bottom and top together, the screw should slide into the hole until it hits the top screw holes where it will need to be driven into the plastic.
16. Congratulations! Enjoy your EV19.

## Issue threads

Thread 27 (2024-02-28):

Move battery connector so does not interfere with keyboard connector

fluffy, 2024-02-28:

BrettRegnier, 2024-08-09:
Fixed on EV11
https://github.com/Quicr/hactar/tree/ev11

Closed 2024-08-09.

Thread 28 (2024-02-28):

Add on / off switch to case

fluffy, 2024-02-28:

BrettRegnier, 2024-03-25:
Could these be a good candidate for the switch?
https://www.aliexpress.com/item/4001207529493.html?spm=a2g0o.order_list.order_list_main.41.23e41802mUHuyH

fluffy, 2024-03-26:
I think we would be better off to get a switch we could source from JLCPCB or a place like digikey. We need to figure out how it mounts in the case and then figure out if goes on the PCB, or if it is seperate with wires that go to a connector on the PCB.

BrettRegnier, 2024-08-09:
Added to EV11 https://github.com/Quicr/hactar/tree/ev11

Closed 2024-08-09.

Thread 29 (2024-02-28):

Add battery low voltage turn off protection

fluffy, 2024-02-28:

BrettRegnier, 2024-03-25:
Where could I find more information on how to design the circuit for this?

fluffy, 2024-03-26:
This is a bit complicated - lets push it out to after EV11.

fluffy, 2025-05-01:
I want to push this off to later - we have too many other problems first. The rough design is there is CPU monitors voltage, and if too low, it can turn off the power supply chip. The chip stays off until the device gets turned off then on again.

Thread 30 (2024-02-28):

move reset / boot buttons so easier to push

fluffy, 2024-02-28:

BrettRegnier, 2024-08-09:
Hopefully its better on EV11, but it could be annoying since the screen may make it harder to get to
https://github.com/Quicr/hactar/tree/ev11

Closed 2024-08-09.

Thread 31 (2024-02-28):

one led that is RED before MGMT chip is programmed

fluffy, 2024-02-28:

BrettRegnier, 2024-03-25:
Tested this out, I erased the firmware on ui, net, and mgmt chips, all of the leds were off before they were programmed, I think the mgmt chip in the Hactar you observed must've been programmed.

fluffy, 2024-03-26:
Ah, I was unclear what I want. When nothing is programmed, I want one of the LEDs to be red (or some color) so we have a clear error for the board works but is not programmed. Overall we need to sort out what color the LEDs are for all the states.

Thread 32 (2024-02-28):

Design and document what all the LEDs mean

fluffy, 2024-02-28:

GhostofCookie, 2025-04-22:
Replaced by #196

GhostofCookie, 2025-04-22:
Related to #196

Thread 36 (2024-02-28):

OTA based debug of net firmware

fluffy, 2024-02-28:

BrettRegnier, 2024-03-25:
Would this be a replacement for a jtag connector for Net?

fluffy, 2024-03-26:
No - this would be for people other than the developers, the direct connectors are much faster and enable debug which this will not.

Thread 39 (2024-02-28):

Cloud relay

fluffy, 2024-02-28:
Get a global DNS based relay running at relay.quicr.io with auto upgrade relased version on github and test.quicr.io being a build of latest version of main.

GhostofCookie, 2025-04-22:
We are currently able to use cloud deployed libquicr relays, though no auto upgrade features.

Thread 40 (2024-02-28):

Make sure audio codec chip can not mess up other chips

fluffy, 2024-02-28:
Right now the serial data out is messing up the auto boot load mode of other things.

fluffy, 2024-02-28:
One possibility is to have and gate on output of codec with a enable line default low and controlled by UI cpu

fluffy, 2024-02-28:
@BrettRegnier - Can you provide more detail about what is going wrong right now

BrettRegnier, 2024-03-22:
The pins that the wm8960 ADC is connect to can also be configured as USART3_RX, which when in bootloader mode all of the possible USART pins are configured into USART mode, and select the first configured USART bus as the communication line. Since the audio chip is always sending data unless it is reset then the bootloader will attempt to communicate using USART3 instead of USART1.

So, all we need to do is change which pin our i2s is connect to by swapping PC11 to PB4 (I2S_ADCDAT)

fluffy, 2024-03-25:
Did this happen on 10.1 ?

BrettRegnier, 2024-04-22:
Yes! This is fixed in 10.1

Closed 2024-04-22.

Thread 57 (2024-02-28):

Auto reset circuit with the ch340

fluffy, 2024-02-28:

Closed 2024-03-05.

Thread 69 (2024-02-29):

Workweek exit test

shamim-pirzada, 2024-02-29:
Two Hactar systems exchange MLS messages with each other via a UDP relay.
UX experience:
Login to hactar device
Connect to Wifi
Join a preconfigured room/space
Send text message (verify received by other device)
Receive text message (send by other device)

Underlying message exchange (ignoring OKs)
Publish intent
subscribe
key exchange
welcome
message send

BrettRegnier, 2024-06-25:
Closing as this was completed at Calgary offsite.

Closed 2024-06-25.

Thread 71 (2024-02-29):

Test plan for next two step after work week (Feb 2024)

shamim-pirzada, 2024-02-29:
N party hactar "conference"

Not user visible:
Clean up code - resolve all the TODOs
Define clean protocol between UI and Net processors
Re architect/design UI proc code
Implement enough instrumentation/metrics to determine performance, footprint, etc

Potential new element
Lock server

UX
same as three party but expanded to N party (5-20)

MLS exchange
TBD

Closed 2025-06-10.

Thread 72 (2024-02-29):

Use regular relay, not a "special" UDP one

shamim-pirzada, 2024-02-29:

BrettRegnier, 2025-02-18:
Fixed in [main](https://github.com/Quicr/hactar/tree/main) branch

Closed 2025-02-18.

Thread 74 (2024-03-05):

Mac CLI to drive other Hactars in the same room

GhostofCookie, 2024-03-05:
Since Hactar boards (ev10 currently) are in short supply, a simple test CLI for joining rooms and sending/recieiving messages to/from Hactar devices would help speed up development. This CLI should be as simple as:
- Asking for relay ip
- Showing list of rooms
- Showing joined room incoming/outgoing messages

Closed 2025-04-22.

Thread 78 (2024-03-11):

EV11

BrettRegnier, 2024-03-11:
Changes for EV11
- [x] Fix schematic errors
- [x] Fix schematic warnings
- [x] Fix PCB errors
- [x] Fix PCB warnings
- [x] C33 does not have LCSC part number but other caps of same value do
- [x]  snap EDA stuff seems to have leaked in on BQ21040DBVR
- [x] Swap PB5 and PC12
- [x] Swap PB4 and PC11
- [x] Test points on ALL signal traces, including clocks, and mics (using a normal 90 degree header)
- [x] SDO and JTAG connectors
- [x] Move battery connector to not be in the way of the keyboard connector.
- [x] The EEPROM should have an identifier like U? not CR1
- [x] U4 has the wrong footprint
- [x] ESP32s3 might have the wrong foot print
- [x] Attach SPKGND and AGND for wm8960
- [x] Move boot and reset buttons to be easier to press.
- [x] ADC for measuring battery voltage (Needs a voltage divider to protect ADC).
      - This should come after the power switch to not burn energy through the divider
- [x] Plug in detect (Also voltage divider but on the 5v rail)
     - Can be on the USB power in?
- [x] Move LEDS to left side of the board.
- [x] Add push to talk button
- [x] Add push to talk to ai button
- [x] Add power switch on side
- [x] Headphone jack bottom right
- [x] Mounting holes for screen (no longer applicable)

BrettRegnier, 2024-03-26:
@fluffy I've moved a lot of the requested changes from the PR #89 to here.

BrettRegnier, 2024-08-08:
https://github.com/Quicr/hactar/commit/1fbbdc0f04e59ff6a59bf5608b80b71c2ae7d91c

Closed 2024-08-08.

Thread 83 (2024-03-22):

EV10.1

BrettRegnier, 2024-03-22:
EV10.5 changes:
- [x] Fix warnings and errors
- [x] Match JLCPCB USB-C Footprint and Symbol
- [x] Swap PB5 and PC12
- [x] Swap PB4 and PC11
- [x] Test points on all signal traces
- [x] U4 has the wrong footprint
- [x] ESP32s3 might have the wrong foot print
- [x] Attach SPKGND and
- [x]  AGND for wm8960

Closed 2024-06-25.

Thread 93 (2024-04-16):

Fix footprint for RGB LED

fluffy, 2024-04-16:

BrettRegnier, 2024-04-22:
Fixed on this [commit](https://github.com/Quicr/hactar/commit/2cca55100d0706a94bcb737841d3a4a8f9549fbf)

Closed 2024-04-22.

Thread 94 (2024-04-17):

origin not set correct on PCB files

fluffy, 2024-04-17:
Getting the huge inverted offsets on JLCPC on 10.1 - need to set origin on PCB layout

BrettRegnier, 2024-04-22:
I'm not getting that issue, on JLCPCB it looks pristine to me... here is a screenshot from their website for Hactar 10.1 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

fluffy, 2024-07-20:
Just add an origin mark in the PCB tool to the bottom left corner of the board.

BrettRegnier, 2024-08-08:
https://github.com/Quicr/hactar/commit/a4b23601647d7e29d31fb3f6082b4056d6f6e17b

Closed 2024-08-08.

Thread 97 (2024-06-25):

Remake serial transmission on stm32

BrettRegnier, 2024-06-25:
Expected behaviour:
- Using DMA transmissions
- Use FIFO hardware buffer
- Circular buffers (no need to restart receive functionality)

Current behaviour:
- Uses blocking transmissions

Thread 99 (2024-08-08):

EV11 Revisions

BrettRegnier, 2024-08-08:
- SCH
    - Collate symbol/footprint libraries.
    - Replace as many custom footprints with kicad built-in
    - Make Schematic power flow left to right
    - Remaster the schematic for USB
    - Redo MGMT decoupling caps
    - Redo MGMT decoupling caps
    - Add test points on either side of amperage resistors
    - Update voltage divider use 0402 package
    - Look up why io46 on the net chip has a resistor and add a note
    - Fix i2c schematic style
    - Replace the wafer connectors with the generic 6 pin and footprint with the proper jst_sh connector
    - Use a more common headphone jack

    - Move WM8960 decouple caps to the top left
    - Clean up C31 so that it is up and down with its own GND symbol
    - Create a new symbol for WM8960:
        - VIN at top and GND at the bottom
        - all digital pins on the left hand side
        - all analog pins on the right hand side

    - Add a capacitor per voltage supply

    - On UI cpu, annotate the pins based on which one influence boot-loader mode

- PCB
    - Some resistors are too close
        - R29
        - R38
        - R37
        - R36
    - Add courtyards footprints that are missing them
    - Add analog ground plane
    - Add analog 3.3V plane
    - Move audio chip and headphone jack to sit on analog plane
    - Update holes to 6mm/3mm
    - Rotate the 2x5 connectors to point outward

- Misc
    - Add a datasheet folder into docts/datasheets

BrettRegnier, 2024-08-08:
https://github.com/Quicr/hactar/commit/1fbbdc0f04e59ff6a59bf5608b80b71c2ae7d91c

Closed 2024-08-08.

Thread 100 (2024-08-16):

Add missing JST and Inductor footprints

BrettRegnier, 2024-08-16:

BrettRegnier, 2025-02-18:
https://github.com/Quicr/hactar/tree/ev12

Closed 2025-02-18.

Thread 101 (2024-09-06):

EV11 Hardware issues

BrettRegnier, 2024-09-06:
- [x]    Some labels are impossible to read
- [x]     Most of the connector labels have gnd and 3.3v reversed.
- [x]     Battery connector pwr and gnd pins are backwards.
- [x]     Screen's extra connector is ramming into the connector on the board. So either we need to flip the screen the other way, or need to move the connector on the board. (probably move the board connector since the screen's connector will ram into the antenna.)
- [x]     The case's screen bezel is too high on the bottom of the screen and too low on the top of the screen.
- [x]     Rename "UI_BOOT" to "UI_BOOT0"
- [x]     Need auto reset circuit for esp32 -> https://preview.redd.it/esp32-auto-reset-circuit-mystery-v0-0qqsa3sm2zpc1.png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

BrettRegnier, 2024-10-22:
https://github.com/Quicr/hactar/commit/2d45fae43cff08c95839c0f43e915653743d5955

Closed 2024-10-22.

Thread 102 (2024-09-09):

Make mgmt turn boot and reset ios to inputs after asserting

BrettRegnier, 2024-09-09:
Right now it holds them in output io pins as it should, but given we want to use a debug board and stm link and esp-prog boards we need them to be inputs so we can source/sink power to the pins for uploading and debugging.

Closed 2025-02-18.

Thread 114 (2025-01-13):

Swap where mgmt boot and reset buttons

BrettRegnier, 2025-01-13:
We cannot touch the reset button, and there is no way because the screen sits on it.
Swap the locations so that we can get to the reset button.

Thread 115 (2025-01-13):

Move the ui stlink connector

BrettRegnier, 2025-01-13:
Move the ui stlink connector so its accessible when the case is on.

BrettRegnier, 2025-02-18:
Will be moved with all other connectors to a monolithic connector to a breakout board.

Closed 2025-02-18.

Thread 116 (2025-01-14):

Test points for signals

fluffy, 2025-01-14:
Need to sort out which ones needs test points

BrettRegnier, 2025-02-18:
We have them going to connectors currently

Closed 2025-07-25.

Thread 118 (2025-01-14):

teminate MCO antenna

fluffy, 2025-01-14:

fluffy, 2025-02-20:
THe MCO is routed to the cnnector, but when nothing is on the connector, this is basically an antena. I think we could dramtically reduce the RF signal if we put a roughly 47K resistor that from MCO to GND that was very close to the connector would help terminate it

BrettRegnier, 2025-02-25:
Updated on this [commit](https://github.com/Quicr/hactar/commit/045eaa244fdc71db71947094fca388237f65e33b)

Closed 2025-07-25.

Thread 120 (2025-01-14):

check routing all high speed signals

fluffy, 2025-01-14:

Finnberg9, 2025-05-15:
are there any specific ones? I checked all the high speed traces for the current PCB and they all seem pretty much as short as possible. Removing the connectors will certainly help shorten them.

BrettRegnier, 2025-05-29:
One thing we have neglected, but maybe can be pushed out to EV14 is that parallel high speed lines are not the same length.

For example, the length of mosi and miso and clk lines should be the same total length.

Same with UI_RX2_NET and UI_TX2_NET, those should be the same length as each other going to the net chip.

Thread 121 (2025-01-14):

Pull up and down for MGMG NRST/Boot

fluffy, 2025-01-14:

BrettRegnier, 2025-02-25:
I am not sure if we need to add an external pull-up resistor to the nrst for mgmt. We are currently using their recommended external reset circuit.

pg 84 of the stm32f702 [datasheet](file:///home/brett/Downloads/stm32f072c8-1.pdf)
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

BrettRegnier, 2025-02-25:
As well, the mgmt_boot has a pulldown resistor.

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

BrettRegnier, 2025-04-09:
@fluffy
Added pull-down to UI_BOOT0 for normal operation on this [commit](https://github.com/Quicr/hactar/commit/fca9c4b6ff0e0127da8520f6f3ede625ea799450)

fluffy, 2025-04-17:
LGTM

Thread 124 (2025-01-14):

tie unused analog inputs to GNDA

fluffy, 2025-01-14:

fluffy, 2025-04-17:
OK - I gave you bad instructions on this sorry

The inputs for Rinput1, 2, 3 look good. You also need to do LINPUT3 to GNDA.

The outputs, so OUTPUT3, SPK_LP,LN and SPK_RP,RN should not be connected to anything.

BrettRegnier, 2025-04-22:
Updated on this [commit](https://github.com/Quicr/hactar/commit/12b7f9c43e1aad6f66e19925c21185e5a9665ce1)

fluffy, 2025-05-01:
OK - this still seem wrong when I grab the latest and I can't  make heads or tails of the commit.

As far as I can tell it is still wrong.

BrettRegnier, 2025-05-06:
Were you perhaps on the main branch?

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

Closed 2025-05-14.

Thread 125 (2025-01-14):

make sure all buttons can be reached with box closed

fluffy, 2025-01-14:

BrettRegnier, 2025-02-18:
For the boot and reset buttons we could add a pin-hole access? Otherwise, I have no idea where we can fit them in the candy-bar style

fluffy, 2025-04-09:
Yep, that makes sense but they probably need to move so they are not under the screen.

fluffy, 2025-04-09:
The way you printed the case for them works well.

BrettRegnier, 2025-04-22:
I like the way it is setup, with the screen-less version, but I am very uncertain where we will put it once it has a screen?.

What about if we put some very small 90 degree buttons that we could add a pin hole beside the usb or something?

fluffy, 2025-05-01:
Can you propose some right angle buttons

Closed 2025-07-25.

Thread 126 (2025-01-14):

make sure all needed connectors can be reached with box closed

fluffy, 2025-01-14:
need to figure out which connectors are needed

GhostofCookie, 2025-04-22:
ev12 case has debug hole on top case with plug.

Closed 2025-04-22.

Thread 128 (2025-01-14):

New case, no snaps

fluffy, 2025-01-14:

GhostofCookie, 2025-04-22:
New case has screws.

Closed 2025-04-22.

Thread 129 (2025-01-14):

Add missing pull up resistors from mgmt and ui boot and nrst

BrettRegnier, 2025-01-14:

BrettRegnier, 2025-04-09:
@fluffy Should we be adding pull up resistors to the nrst?

stm32f405 datasheet
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

stm32f072 datasheet
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

BrettRegnier, 2025-04-09:
@fluffy
Added pull-down to UI_BOOT0 for normal operation on this [commit](https://github.com/Quicr/hactar/commit/fca9c4b6ff0e0127da8520f6f3ede625ea799450)

BrettRegnier, 2025-04-09:
Duplicate of #121

Closed 2025-04-09.

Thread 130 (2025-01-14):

Print EV9 and EV12 schematics and mark off what parts are there and what are missing.

BrettRegnier, 2025-01-14:

Closed 2025-06-25.

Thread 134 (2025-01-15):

Esp32s3 shows signs of browning out

BrettRegnier, 2025-01-15:
Net chip will begin boot sequence and will repeat multiple times before stabilizing with no error implying a possible brown out.

BrettRegnier, 2025-06-10:
This may be a red-herring.

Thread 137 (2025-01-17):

deisgn breakout board

fluffy, 2025-01-17:
- [ ] pick connecter
- [ ] figure out what signals on it
- [ ] design board

fluffy, 2025-01-17:
If we were doing 10 pin, perhaps two of the
S10B-ZR-SM4A

On one we could have
UI_SWCLK
UI_DATA
MGMT_SWCLK
MGMT_DATA
NET_MTMS
NET_MTCK
NET_MTDIO
NET_MTDI
MGMT_NRST
GND

On other could have
GND
UI_DEBUG1
UI_DEBUG2
UI_DEBUG3
NET_DEBUG1
NET_DEBUG2
UI_TX_NET
UI_RX_NET
USB_TX_MGMT
USB_RX_MGMT

I don't know if I like this idea but at least a starting point for discution

fluffy, 2025-05-13:
dup of #150

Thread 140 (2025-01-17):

burn fuses simplier

fluffy, 2025-01-17:
make good instructions for board bring up

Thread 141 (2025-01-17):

Fix footprint audio connector

fluffy, 2025-01-17:

Closed 2025-06-17.

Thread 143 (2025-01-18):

Move to all surface mount parts

fluffy, 2025-01-18:
- [ ] Change power switch to surface mount
- [ ] Investigate if USB is OK

BrettRegnier, 2025-02-18:
>Investigate if USB is OK

Can you give more details? Do you mean ok because its half surface mount, half not?

fluffy, 2025-02-20:
Move to all thing that we can reflow solder.

I think this means changing:

- [ ] power on/off switch

Not sure it means changing anything else.

Closed 2025-07-25.

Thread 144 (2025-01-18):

Add mount holes to PCB

fluffy, 2025-01-18:
Prob set up for M2.5 bolts

BrettRegnier, 2025-02-24:
Do we have specific spots we want them?

fluffy, 2025-04-09:
Well roghly speaking withing 2 cm of each corrner. But they need to be more than 3 mm from the edge and we have lots of other stuff we need to avoid

BrettRegnier, 2025-05-29:
The mount hole near the boost converter is 1mm too close to the edge

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

The mount hole near the headphones jacks is about 0.5mm too close to the edge.

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

Mount hole near the top right is about 0.5mm too close

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

Same with the top left.

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

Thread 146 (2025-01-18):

Test point holes too small to get pin into

fluffy, 2025-01-18:

BrettRegnier, 2025-02-18:
Are you looking for a 2.54mm hole?

fluffy, 2025-02-20:
Well lets say something we could get a 22 gauge wire into

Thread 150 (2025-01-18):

Dev Break Off board in battery space ?

fluffy, 2025-01-18:
talk to cullen about hair brain idea

BrettRegnier, 2025-02-21:
I love this hair brain idea!

fluffy, 2025-05-13:
I think we shoiuld move this out of EV13 and think abotu later

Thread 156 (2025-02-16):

Add schematic note on MGMT boot pins

fluffy, 2025-02-16:
Add to the schematic pins that have to be stable at boot to not be detected as bootloader input

PA9/PA10 is used for actually bootload

PA15 - input usart2
PA14 - output usart2

PB6,PB7 - in/out for I2C

PA11/PA12 - in/out for USB

Notes on current setup

PA14,PA15 prob need pull down.

PB6/PB7 - need pull down restores - currently floating

PA11,12 - need pull down resistors - currently floating.

fluffy, 2025-02-16:
From datasheet

> The boot loader is located in System Memory. It is used to reprogram the Flash memory by
> using USART on pins PA14/PA15, or PA9/PA10 or I2C on pins PB6/PB7 or through the USB
> DFU interface.

Finnberg9, 2025-05-15:
Note that on EV13, the pins are totally different. TO solve this issue, I added 4.7k pull down resistors to all unused GPIO pins on the STM32F0. These pins were PA5, PB12, and PC13

BrettRegnier, 2025-05-29:
I think it would be helpful to put "bootloader" on each pin like we have on the ui so its more clear and easier to hunt down the pins than reading the note.

BrettRegnier, 2025-05-29:
Otherwise, I think it looks fine

Closed 2025-07-25.

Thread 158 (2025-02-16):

Boot mode floating pins

fluffy, 2025-02-16:
Add 4.7K pull down to followinig on MGMT chip so they do not float when trying to find bootloader

PA14,PA15 prob need pull down.

PB6/PB7 - need pull down restores - currently floating

PA11,12 - need pull down resistors - currently floating.

fluffy, 2025-02-20:
LGTM

Closed 2025-02-20.

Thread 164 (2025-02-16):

Does R30 have correct value ?

fluffy, 2025-02-16:

BrettRegnier, 2025-02-18:
Yeah the goal was to just have it there and remove it if it was a problem. The keyboard has a built in resistor for the led.

Closed 2025-05-14.

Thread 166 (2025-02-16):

Replace D2 with ideal diode

fluffy, 2025-02-16:

Finnberg9, 2025-05-13:
figure out how to replace this with a mosfet

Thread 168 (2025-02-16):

Feed barCHG from charger to MGMT chip

fluffy, 2025-02-16:
Allow MGMT chip to monitor if charged or not

Finnberg9, 2025-05-13:
Add trace from MGMT GPIO to CHG line between diode and resistor

fluffy, 2025-07-26:
Could PC13 or PB1 be used ?

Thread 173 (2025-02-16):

make the PTT buttons have debounce like Boot SW

fluffy, 2025-02-16:

BrettRegnier, 2025-02-27:
Would this rc circuit be more effective? (Removing the schmitt trigger)

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

fluffy, 2025-04-04:
Lets talk about this next time we have a call

BrettRegnier, 2025-04-09:
Added rc circuits to ptt and ptt ai on this [commit](https://github.com/Quicr/hactar/commit/f4009a771059fcb9606afce7b49600ad3dd055cb)

fluffy, 2025-04-15:
LGTM

Closed 2025-04-22.

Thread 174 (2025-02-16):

Safety resistors on KB_COL outputs

fluffy, 2025-02-16:
Add 680R  output resistors on KB_COL lines so if two keys pressed same time does not short the outputs together

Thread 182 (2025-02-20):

Is kbd connector too close to battery ?

fluffy, 2025-02-20:

BrettRegnier, 2025-02-20:
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

Looks like it fits pretty good! Tight, but the battery and connector don't touch

fluffy, 2025-02-23:
Uh, I don't think flex cables are supposed to have that tight of a bend anywhere on them. It should come more straight of the connector then slowly flex. We can try to find the specs on flex but doubt that is ok

BrettRegnier, 2025-02-25:
In the photo I did exaggerate the bend in the flex cable to get a good shot. Regardless, it does have bend we may need to reconsider it's position in relation to where the keyboard will be sitting with a case. Otherwise, the bend isn't too sharp.

Finnberg9, 2025-05-13:
Move keyboard connector down as much as possible

Closed 2025-05-14.

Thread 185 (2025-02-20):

Remove RCC_OSC_IN & RCC_OSC_OUT nets

BrettRegnier, 2025-02-20:
@fluffy Do we need these nets? Or at they just supposed to be a label?

fluffy, 2025-02-21:
Technically you do not need them as all wires connect but the advantage of keeping them is when you are laying traces on the PCB, you can see what they are. It also makes it easier to apply properties to these traces on PCB layout if we want to.

I tent to label most things but some others don't - can go either way on this.

BrettRegnier, 2025-02-25:
You convinced me!

Closed 2025-02-25.

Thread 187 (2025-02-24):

Change sizes of caps and resistors on schematic

BrettRegnier, 2025-02-24:
No room to add new symbols

BrettRegnier, 2025-02-24:
Completed in this [commit](https://github.com/Quicr/hactar/commit/93ba59c604541234d66661bc789cc41a77f867a6)

Closed 2025-02-24.

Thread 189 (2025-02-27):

Measure current on oscilloscope using current sense resistor

BrettRegnier, 2025-02-27:
Using 3 probes:
- Attach 1 on each side of the current sense resistor
- Attach 1 to a net debug and add a gpio pulse around where quicr pushes to the udp stack to trigger the measurement.

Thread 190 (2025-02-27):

Move MIC_P to LINPUT3 so we can use jack detect

BrettRegnier, 2025-02-27:
Assuming @fluffy agrees.

fluffy, 2025-02-28:
I want to review this really carefully before we do it. I'm not sure it will do what you want to reduce clicks and I'm actually more keen on moving to the mics with a PTT button. It's just I think we put a bunch of thought into this before

BrettRegnier, 2025-02-28:
As I read more about it, the big benefit I would see for it is that we could keep our audio levels at zero, and when the headphone jack detect signal is sent we can raise our output volumes to the headphones to try and avoid the "DC pop".

Alternatively, according to this forum we could try adding a RC circuit on the output to a speaker, I don't know if this would also work for a headphone or not.

https://electronics.stackexchange.com/questions/323356/loud-pop-noise-while-plugging-to-a-headphones-jack

BrettRegnier, 2025-04-10:
From the WM8960 chip, before or after the capacitor?

fluffy, 2025-04-14:
after the capacitor

fluffy, 2025-05-01:
LGTM

Closed 2025-05-01.

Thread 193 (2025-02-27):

Check current sense resistor footprint

BrettRegnier, 2025-02-27:

Finnberg9, 2025-05-13:
Can you elaborate what this means.

Finnberg9, 2025-05-13:
R42

Finnberg9, 2025-05-14:
Should be right, footprint is for an 0603 1608 smd resistor and based on the JLC# C111027 is also an 0603 1608 smd resistor.

Closed 2025-05-14.

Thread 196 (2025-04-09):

Move LEDs to make sense from UI point of view

fluffy, 2025-04-09:
Right now it is hard to even describe to people which LED is which and the pairs are so close togehter it is sometimes hard to know which is which. I'm not sure exactly what we should do here but seems like we need a bit of design of where LEDs are on case

vcostama, 2025-04-23:
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

this is current state of the led lights, we'll be updating the position of the led lights when Brett returns from pto. i'll also be updating this docu audio to compliment the leds.

fluffy, 2025-04-25:
Sounds good.

Eventually, I suspect we need indicate at least the following:

Software Error
No Wifi Connection
No Relay Connection
Low Battery

Later we might want to indicate:

Message waiting

I'm not sure what else is needed but would want over time.

vcostama, 2025-04-25:
thanks for bringing those up. definitely i'll incorporate those items and any additional items we need to convey status/state.

vcostama, 2025-05-15:
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

version 2

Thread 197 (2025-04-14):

Remove corner of PCB to make room for interior bolt holes for case

fluffy, 2025-04-14:
Right now the bolts to put together the case are outside the edge of the case but would look better if moved inside. But to do that, we need to have some free space at the corners of the PCB.

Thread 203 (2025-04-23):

Find new capacitor for power supply

BrettRegnier, 2025-04-23:
Previous capacitor
https://jlcpcb.com/partdetail/C495959

In case the page gets taken down here are the specs.
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

BrettRegnier, 2025-04-23:
https://jlcpcb.com/partdetail/28983-CL21B104KCFNNNE/C28233

This seems like it has similar attributes with the same package.

fluffy, 2025-05-01:
Interesting. It looks like EV10 schmatic had a mistake and did not specity a part numnber for that then on a later one the wrong one got added. The cap we had was not a good choice.

I think we should go with
https://jlcpcb.com/partdetail/MurataElectronics-GCM21BR72A104KA37L/C85866

BrettRegnier, 2025-05-01:
Ok!

BrettRegnier, 2025-05-05:
#209

Closed 2025-05-05.

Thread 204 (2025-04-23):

Find new ptt buttons

BrettRegnier, 2025-04-23:
Previous buttons
https://jlcpcb.com/partdetail/Yuandi-Yuandi_TS_1037_A11B3D2/C499331

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

BrettRegnier, 2025-04-23:
https://jlcpcb.com/partdetail/ShouHan-TS665TPZJ/C557600

If we did the above part I could design some 3d printed buttons that get pinched between the case top and bottom and will wrap around the tip of the button so it doesn't slide around and then it will still feel nice and tactile but we can then design how we want the button look like!

BrettRegnier, 2025-04-30:
One more alternative:
https://jlcpcb.com/partdetail/Yuandi-TS_1045_A13B3D2/C557898

fluffy, 2025-05-01:
I think I lean towards trying the https://jlcpcb.com/partdetail/Yuandi-TS_1045_A13B3D2/C557898

Do we have stl models for it ?

BrettRegnier, 2025-05-01:
EasyEDA has models so I could download the model

Closed 2025-05-05.

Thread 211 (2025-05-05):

Replace screen connector with connector that comes with our screen module.

BrettRegnier, 2025-05-05:

Closed 2025-05-13.

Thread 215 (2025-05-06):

Update Buttons/capacitors/connectors part #

Finnberg9, 2025-05-06:
replace C37, C40, C42 from C495959 to C85866

replace SW1 and SW3 to C557898

Replace CN2, CN7, CN5, CN6 to C2962222

Finnberg9, 2025-05-07:
https://github.com/Quicr/hactar/commit/94ec07b123e42fb343a2fe5d77ed2aa2cae33283

Closed 2025-05-07.

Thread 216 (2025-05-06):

Connect Unconnected Traces

Finnberg9, 2025-05-06:
Several traces are no longer connected on EV13 PCB that need to be re-attatched.

Finnberg9, 2025-05-12:
https://github.com/Quicr/hactar/commit/0ca7f08b6da65539a1499016c6ed63c16ecd7baa

This commit connects the missing 20 traces from the earlier commit and cleans up some of the existing traces. No changes made to the schematic.

Closed 2025-05-13.

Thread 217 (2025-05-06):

Create EV13 Dev board

Finnberg9, 2025-05-06:
Remove all existing connectors except (Jtag?) and move them to an extra area of the board with through holes for probing and debugging.

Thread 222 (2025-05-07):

Connect additional pull-down resistors.

Finnberg9, 2025-05-07:

Finnberg9, 2025-05-07:
https://github.com/Quicr/hactar/commit/ebf4b7e42d9b1ed77588c2dfcf7d374f6462a1e2 closes this issue

Closed 2025-05-07.

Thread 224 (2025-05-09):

update new part changes for EV13

Finnberg9, 2025-05-09:
Update part number for connectors, C37, C40, C42, and the two buttons

Finnberg9, 2025-05-09:
https://github.com/Quicr/hactar/commit/94ec07b123e42fb343a2fe5d77ed2aa2cae33283 fixes this issue

Closed 2025-05-13.

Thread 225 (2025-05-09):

Remove incorrect traces from PCB and connect all new pull down resistors

Finnberg9, 2025-05-09:
Remove all the traces from EV13 that no longer match the schematic and add all the additional pull down resistors to the PCB. Just leaving the unconnected traces empty for now sine there is another issue directly related to that.

Finnberg9, 2025-05-09:
https://github.com/Quicr/hactar/commit/ebf4b7e42d9b1ed77588c2dfcf7d374f6462a1e2 fixes this

Closed 2025-05-13.

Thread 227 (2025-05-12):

Fix the "Footprint does not match copy in library" warning

Finnberg9, 2025-05-12:
Fix the 13 errors for U1, CN3, JP3, SW5, U6, SW4, U3, J3, CN4, U11, J9, U8, and U5.

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

Finnberg9, 2025-05-13:
f086c1a fixes this issue

Finnberg9, 2025-05-13:
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

Closed 2025-05-13.

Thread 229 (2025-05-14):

Reconsider what buttons and connectors we have to have on EV13

fluffy, 2025-05-14:

Finnberg9, 2025-05-30:
For EV13, there will be five buttons, PWR, P2T, and P2T2AI, boot and nrst.
There will only be 2 connectors: 2mm screen connector and keyboard connector
All debug connectors on dev board side will be removed for EV13.

Closed 2025-07-25.

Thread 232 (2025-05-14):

Consider new dual jack headset connector for EV13

fluffy, 2025-05-14:
This might have to wait for EV14

BrettRegnier, 2025-05-15:
I've made an adapter board [here](https://github.com/Quicr/hactar/pull/223) for testing.

Closed 2025-07-25.

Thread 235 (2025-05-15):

Fix stm32 flasher code.

BrettRegnier, 2025-05-15:

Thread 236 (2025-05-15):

Consider slimmer battery and remove battery cut out

Finnberg9, 2025-05-15:
I think we could optimize this PCB design by switching to a larger but slimmer battery and having it mounted either directly on top or below the PCB. No cut out, just a small rectangular PCB with a battery above it. Some possible solutions are:

This battery is off of an old garmin, and has great dimensions: Product Type: Li-Polymer, Voltage: 3.7V, Capacity: 1250mAh / 4.63Wh. Size: 60.00 x 36.00 x 6.00mm, Weight: 48g.
https://www.amazon.ca/dp/B0B7783HBQ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

This one is from an old logitech mouse, and is about the same dimensions: lithium ion polymer battery, nominal voltage 3.7V, full charge voltage 4.2V, capacity 1150mAh, power 4.25Wh, size 50.5×34×5.2mm(1.988×1.338×0.204inch）(L*W*T), Weight:21g(0.74oz)，Maximum current:1.1A。 It can prevent overcharge, overdischarge, overcurrent, and short circuit.
https://www.amazon.ca/dp/B098XJDGTT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

This seller has a ton of batteries that would work great. They have all sizes and dimensions and some batteries are as thin as 3mm.
Depending on case size we can find one that fit's perfectly. But here is a potentially good one, 3.8x 56 x 77mm so super thin, and 2,500mAh which is 3x our current battery life. https://www.amazon.ca/Qimoo-Battery-Rechargeable-Connector-Electronic/dp/B0CNLMN6GR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

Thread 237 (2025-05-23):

Add 2 headers, one that is all gnd and the other that is all 3.3v for dev board

BrettRegnier, 2025-05-23:

BrettRegnier, 2025-05-29:
@Finnberg9 The added test points are not necessary on the dev cut out.

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

It probably will make the dev cut out longer than you currently have it, but I'd like a female header, like the one you are currently using for the rest. To have all 3.3v on one side, and on the other side all gnd

Closed 2025-05-29.

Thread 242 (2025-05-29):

Add UI_Ready gpio pin to net and NET_Ready gpio pin to ui.

BrettRegnier, 2025-05-29:
For example, with a series resistor, attach (ui stm32) PC2 to (esp32) IO8 and (esp32) IO9 to (ui stm32) PC3

Finnberg9, 2025-05-30:
Update:
NET_READY: runs from IO8 on the ESP32 with a 1k resistor to PC3 on STM32.
UI_READY: runs from PC2 on STM32 with a 1k resistor to IO9 on ESP32.

BrettRegnier, 2025-07-25:
Closed by #247

Closed 2025-07-25.

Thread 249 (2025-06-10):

MIC IO voltage dividers on hactar 13

fluffy, 2025-06-10:
Could the resisotrs be replace with 100k and 47k to reduce the number of differnt resotrs that have to be loaded into machines

Closed 2025-06-17.

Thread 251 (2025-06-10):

battery mon circuit

fluffy, 2025-06-10:
Replace resistor values with for 1k and 3k with something that totals between 10k and 50k and keep the voltage device ration between say 0.5 and 0.8 and uses values of restores we use elsewhere

Closed 2025-06-17.

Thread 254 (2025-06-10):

I2S termination resistors near the debug connector

fluffy, 2025-06-10:
So I2S_DAV and I2S_BCLK have termination reisotrs R46 and R30

Add similar ones to the other two I2S lines

Move them on the schematic to be beside the debug jack they connect to

Place them on PCB very close to debug connector (J3) so it does not act like antenna

Much like was done for MCLK with R50

Closed 2025-08-26.

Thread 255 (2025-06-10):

PCB text is too small for LED and button labels

fluffy, 2025-06-10:

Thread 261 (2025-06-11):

Fix mgmt not responding to commands on first power up

BrettRegnier, 2025-06-11:

Closed 2025-06-11.

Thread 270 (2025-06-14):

Store config in EEProm

fluffy, 2025-06-14:
- [ ] Make the USB connection so it can run terminal program and store config stuff in EEProm
- [ ] Store the WiFi SSID and pwd in the EEProm
- [ ] Store the Sframe Key in EEProm
- [ ] Store URL of MoQ relay in EEProm

fluffy, 2025-06-14:
If it helps, I have code in other project so to be able to read / write to eeprom we are using from stm32

BrettRegnier, 2025-06-15:
Will we have enough space on our eeprom? It's only 1024 bytes of storage

fluffy, 2025-08-05:
@bifurcation - currently when we upgrade the firmware on the net chip, we erase all the flash and surely you are not suggesting the crypto info is on the flash of the net chip ???

bifurcation, 2025-08-05:
1. We need persistence on the net chip.  If we don't have that today, that's a different problem.
2. We don't have a requirement to program any crypto info right now.

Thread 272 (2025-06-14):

On EV13 test loading firmware over USB

fluffy, 2025-06-14:
With an EV13 board that has not been programmed before, test that we load the firmware on all 3 CPU using only the USB connector.

Do we need the boot & reset buttons or not ?

Can we get the fuses on ESP?

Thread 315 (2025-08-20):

Fix P-Channel MOSFET on EV14

BrettRegnier, 2025-08-20:
https://jlcpcb.com/api/file/downloadByFileSystemAccessId/8588884110555426816

Closed 2025-08-26.

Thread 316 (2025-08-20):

Update headphone jacks on EV14 to use BF-888S/BF-88A Kenwood compatible earpieces

BrettRegnier, 2025-08-20:
- [x] Change wiring of jacks
- [x] Adjust distances between jacks on pcb
- [x] Remove old components no longer being used.

Closed 2025-08-26.

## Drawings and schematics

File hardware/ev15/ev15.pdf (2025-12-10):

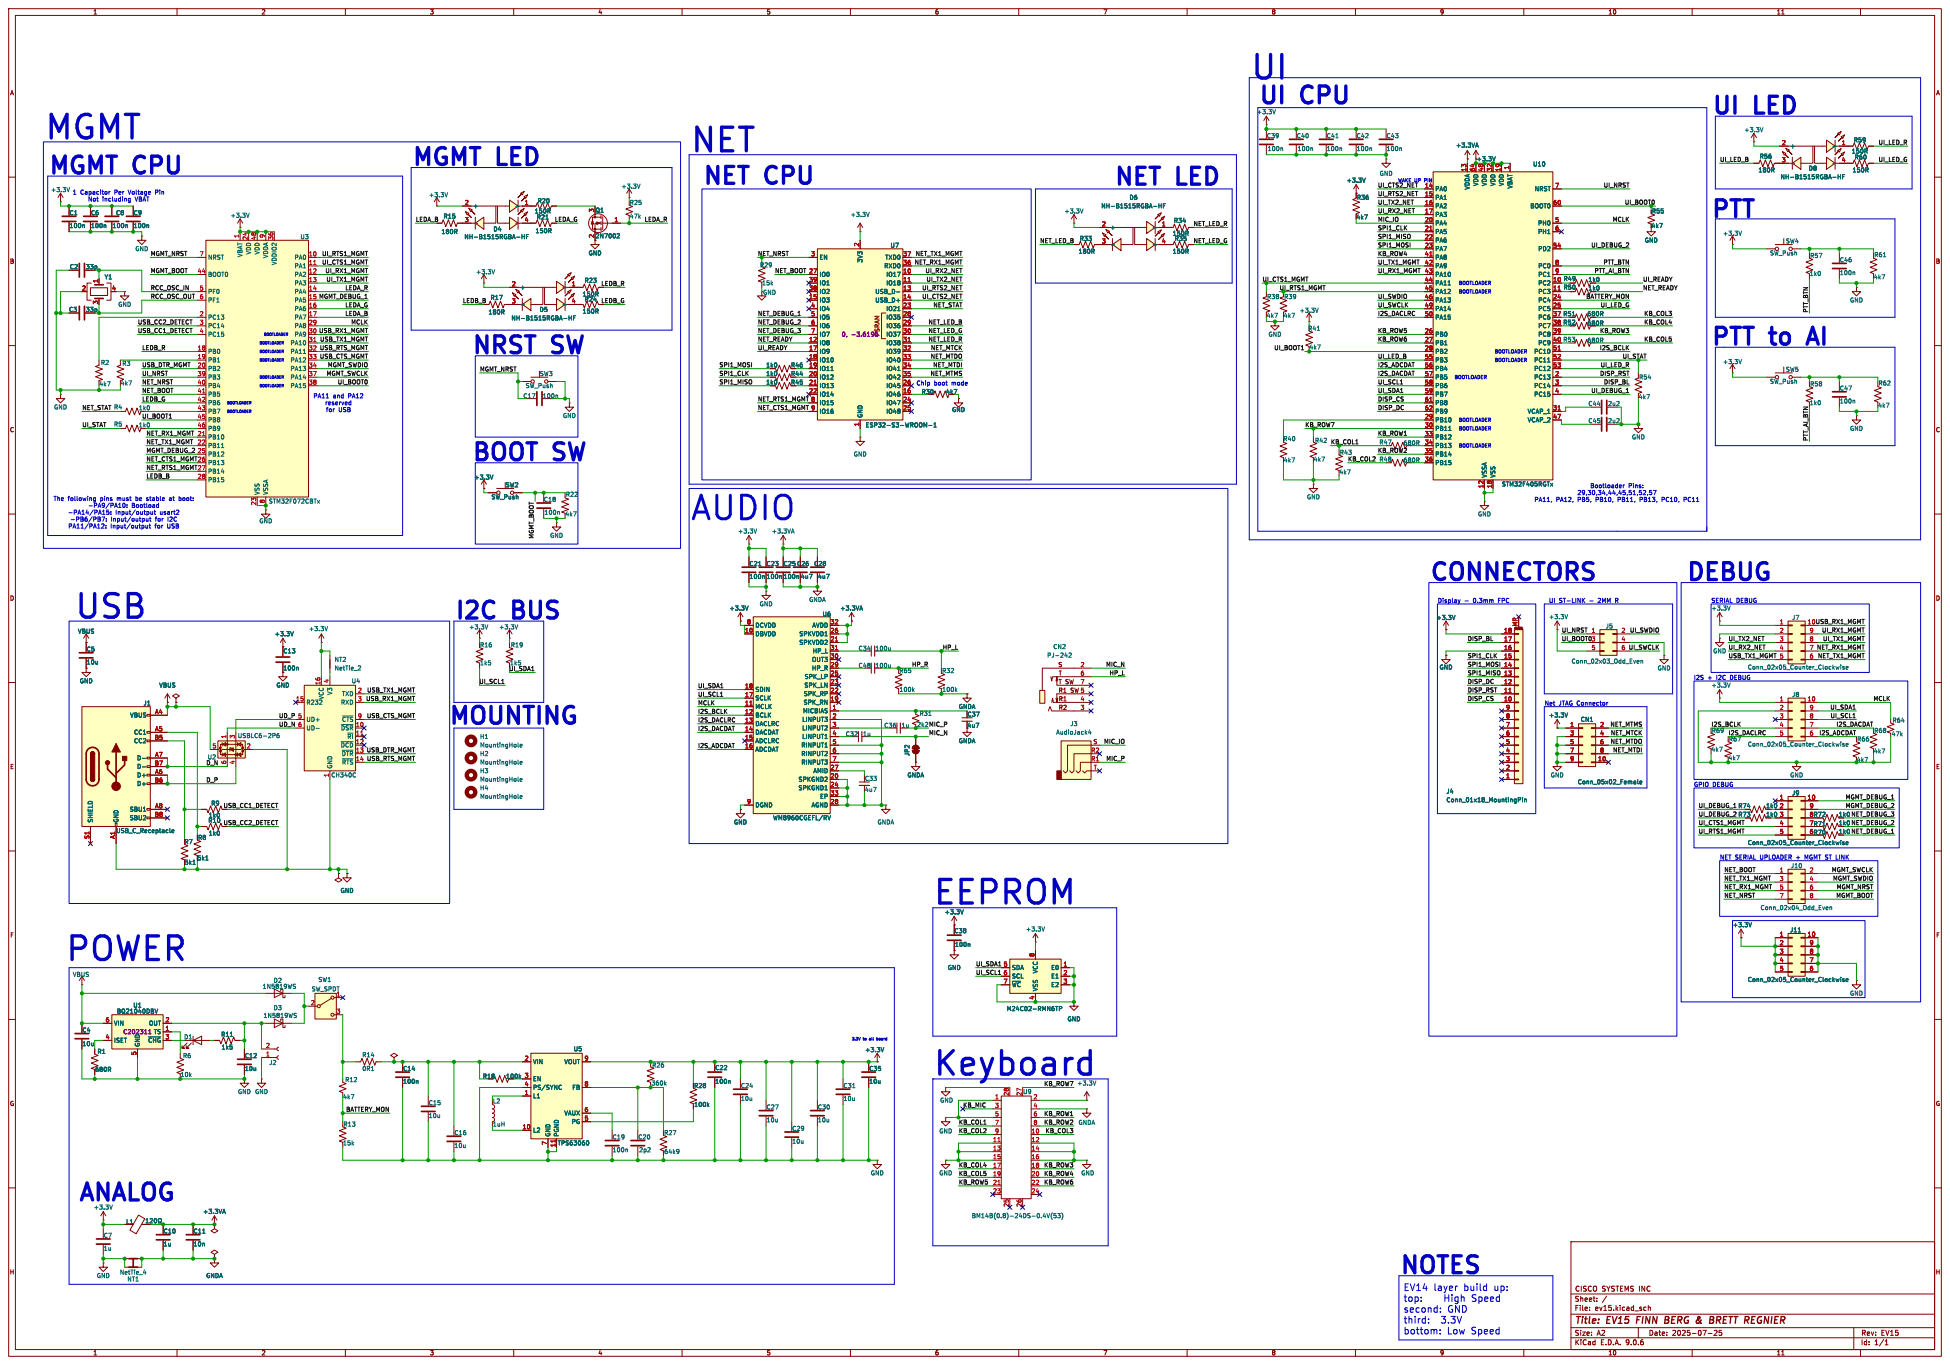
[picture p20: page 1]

1 VDD 19 VDD 32 VSS 18 VDD 48 VSSA 12 VDD 64 VDDA 13 PA0

1 VDD 24 VDD 48 VSS 23 VDDA

MGMT_NRST
3.3V to all board AUDIO

BOOT SW
LINPUT1 4 RINPUT1 5 RINPUT2 6 RINPUT3 7 AMID 27 SPKGND2 20 SPKGND1 24 EP 33 AGND 28 U6 WM8960CGEFL/RV GND

1 TXD 2 RXD 3 ~{CTS}9 ~{DSR} 10 ~{RI} 11 ~{DCD} 12 ~{DTR} 13 ~{RTS} 14 U4 CH340C GNDSHIELD S1 GND A1 VBUS A4 CC1 A5 CC2 B5 D- A7 D- B7 D+ A6 D+ B6 SBU1 A8 SBU2 B8

LINPUT1 4 RINPUT1 5 RINPUT2 6 RINPUT3 7 AMID 27 SPKGND2 20 SPKGND1 24 EP 33 AGND 28 GND

NET SERIAL UPLOADER + MGMT ST LINK NOTES

4 SDA 5 SCL 6 ~{WC} 7 GND

10u U5 TPS63060 VIN 2 EN 3 PS/SYNC 4

7 PGND 11 VOUT 9 FB 8 VAUX 6 PG 5 U5 TPS63060 C31
VIN 2 EN 3 PS/SYNC 4

7 PGND 11 VOUT 9 FB 8 VAUX 6 PG 5 +3.3VA C11

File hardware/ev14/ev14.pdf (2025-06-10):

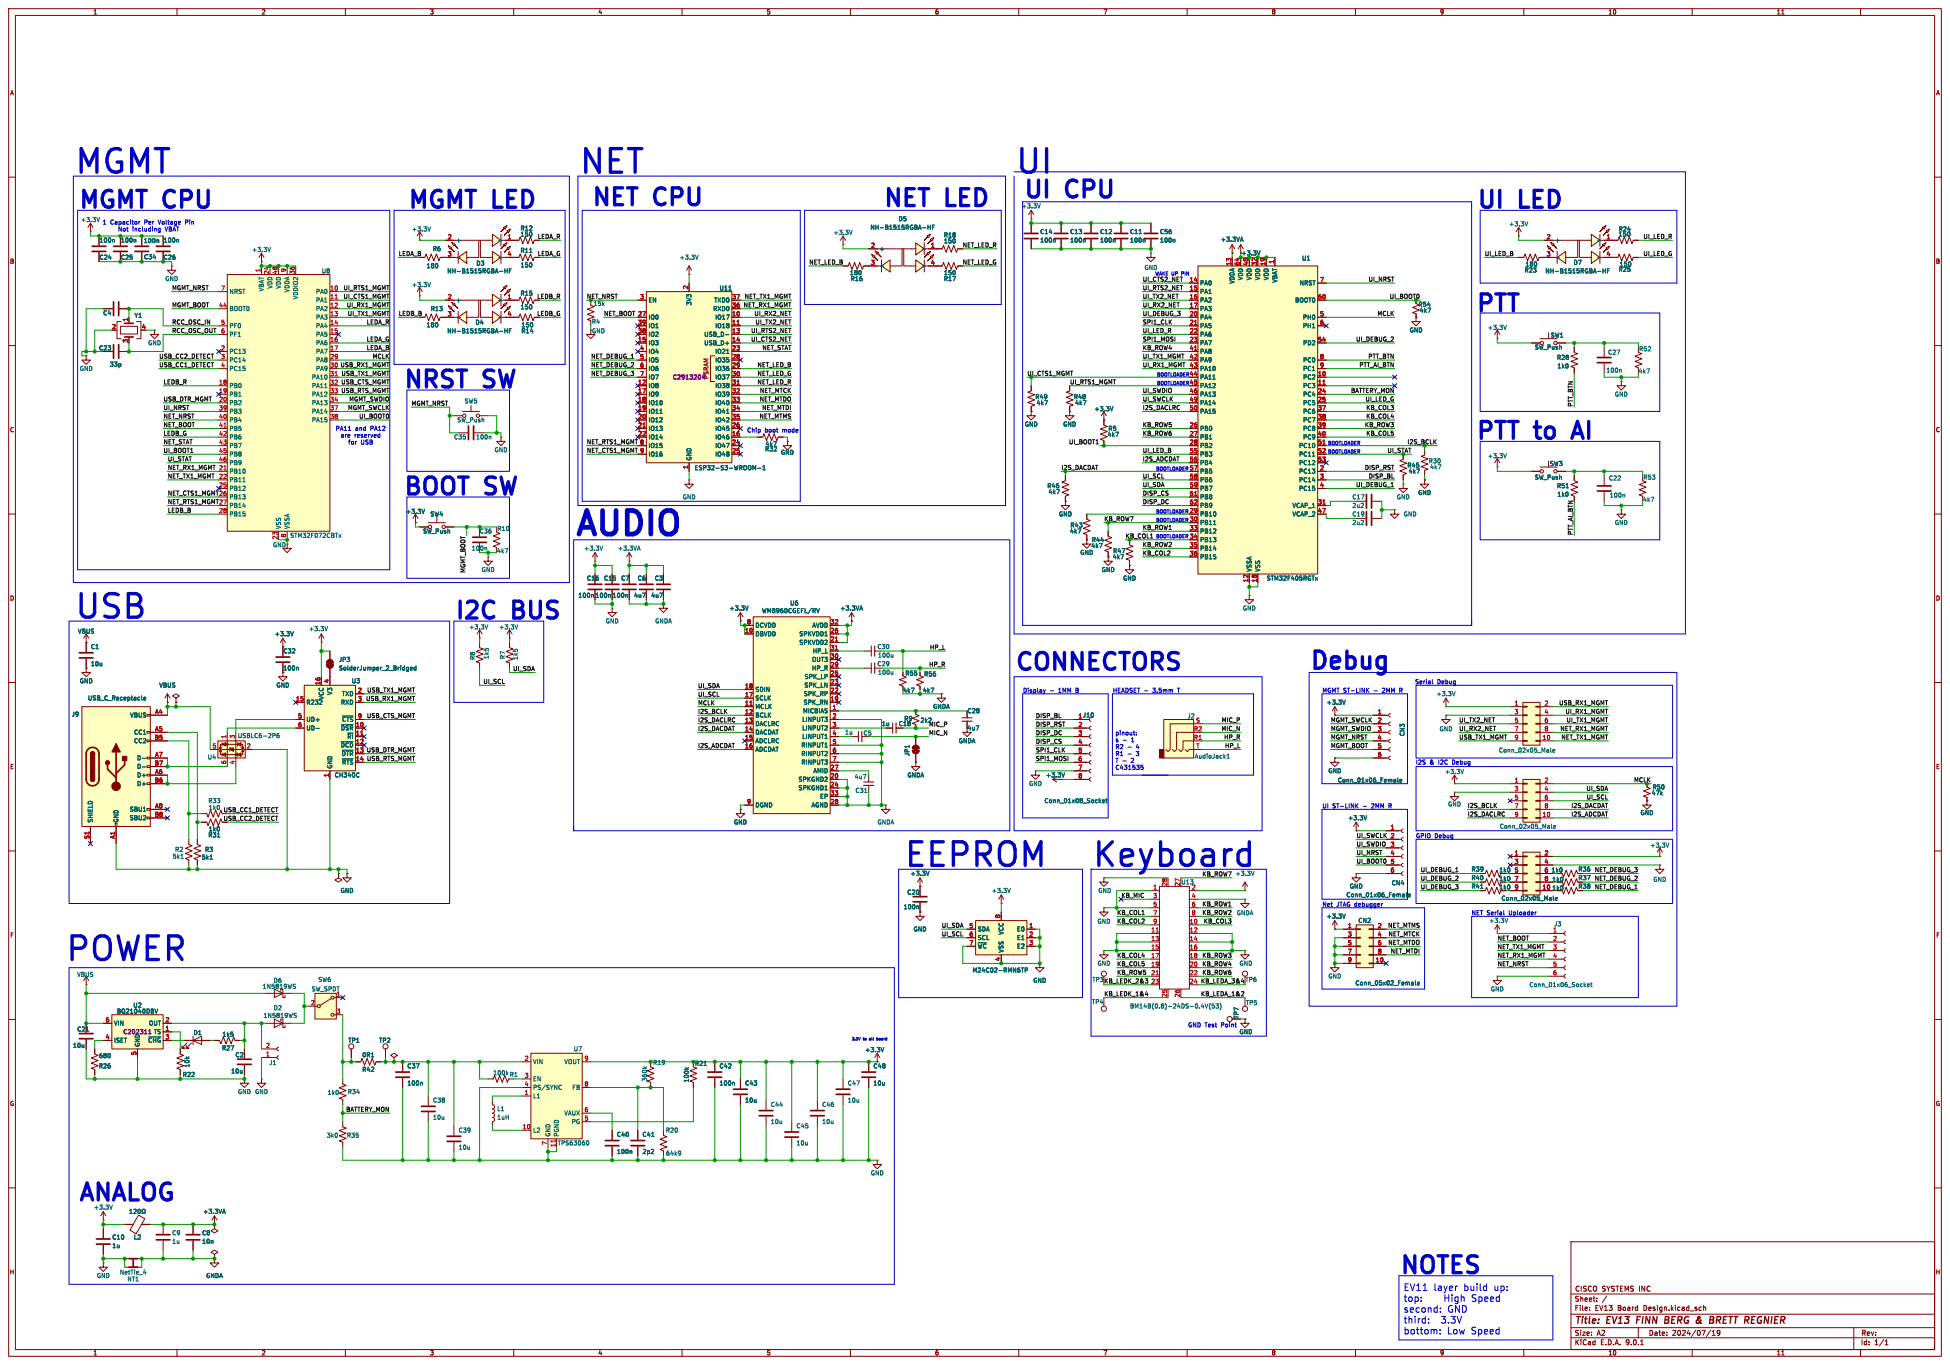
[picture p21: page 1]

BOOTLOADER MGMT
BOOTLOADER UI CPU MGMT CPU

Chip boot mode MGMT LED

WAKE UP PIN EEPROM

1 VDD 19 VDD 32 VSS 18 VDD 48 VSSA 12 VDD 64 VDDA 13 PA0

1 VDD 24 VDD 48 VSS 23 VDDA

UI ST-LINK - 2MM R I2C BUS

JP3 SolderJumper_2_Bridged GND
GND GND

1 TXD 2 RXD 3 ~{CTS}9 ~{DSR} 10 ~{RI} 11 ~{DCD} 12 ~{DTR} 13 ~{RTS} 14 VBUS

1 TXD 2 RXD 3 ~{CTS}9 ~{DSR} 10 ~{RI} 11 ~{DCD} 12 ~{DTR} 13 ~{RTS} 14 U3 CH340C

4 SDA 5 SCL 6 ~{WC} 7M24C02-RMN6TP GNDA GNDA C28

4 SDA 5 SCL 6 ~{WC} 7 GNDA GNDA C28

7 PGND 11 VOUT 9 FB 8 VAUX 6 PG 5 U7 TPS63060 C41

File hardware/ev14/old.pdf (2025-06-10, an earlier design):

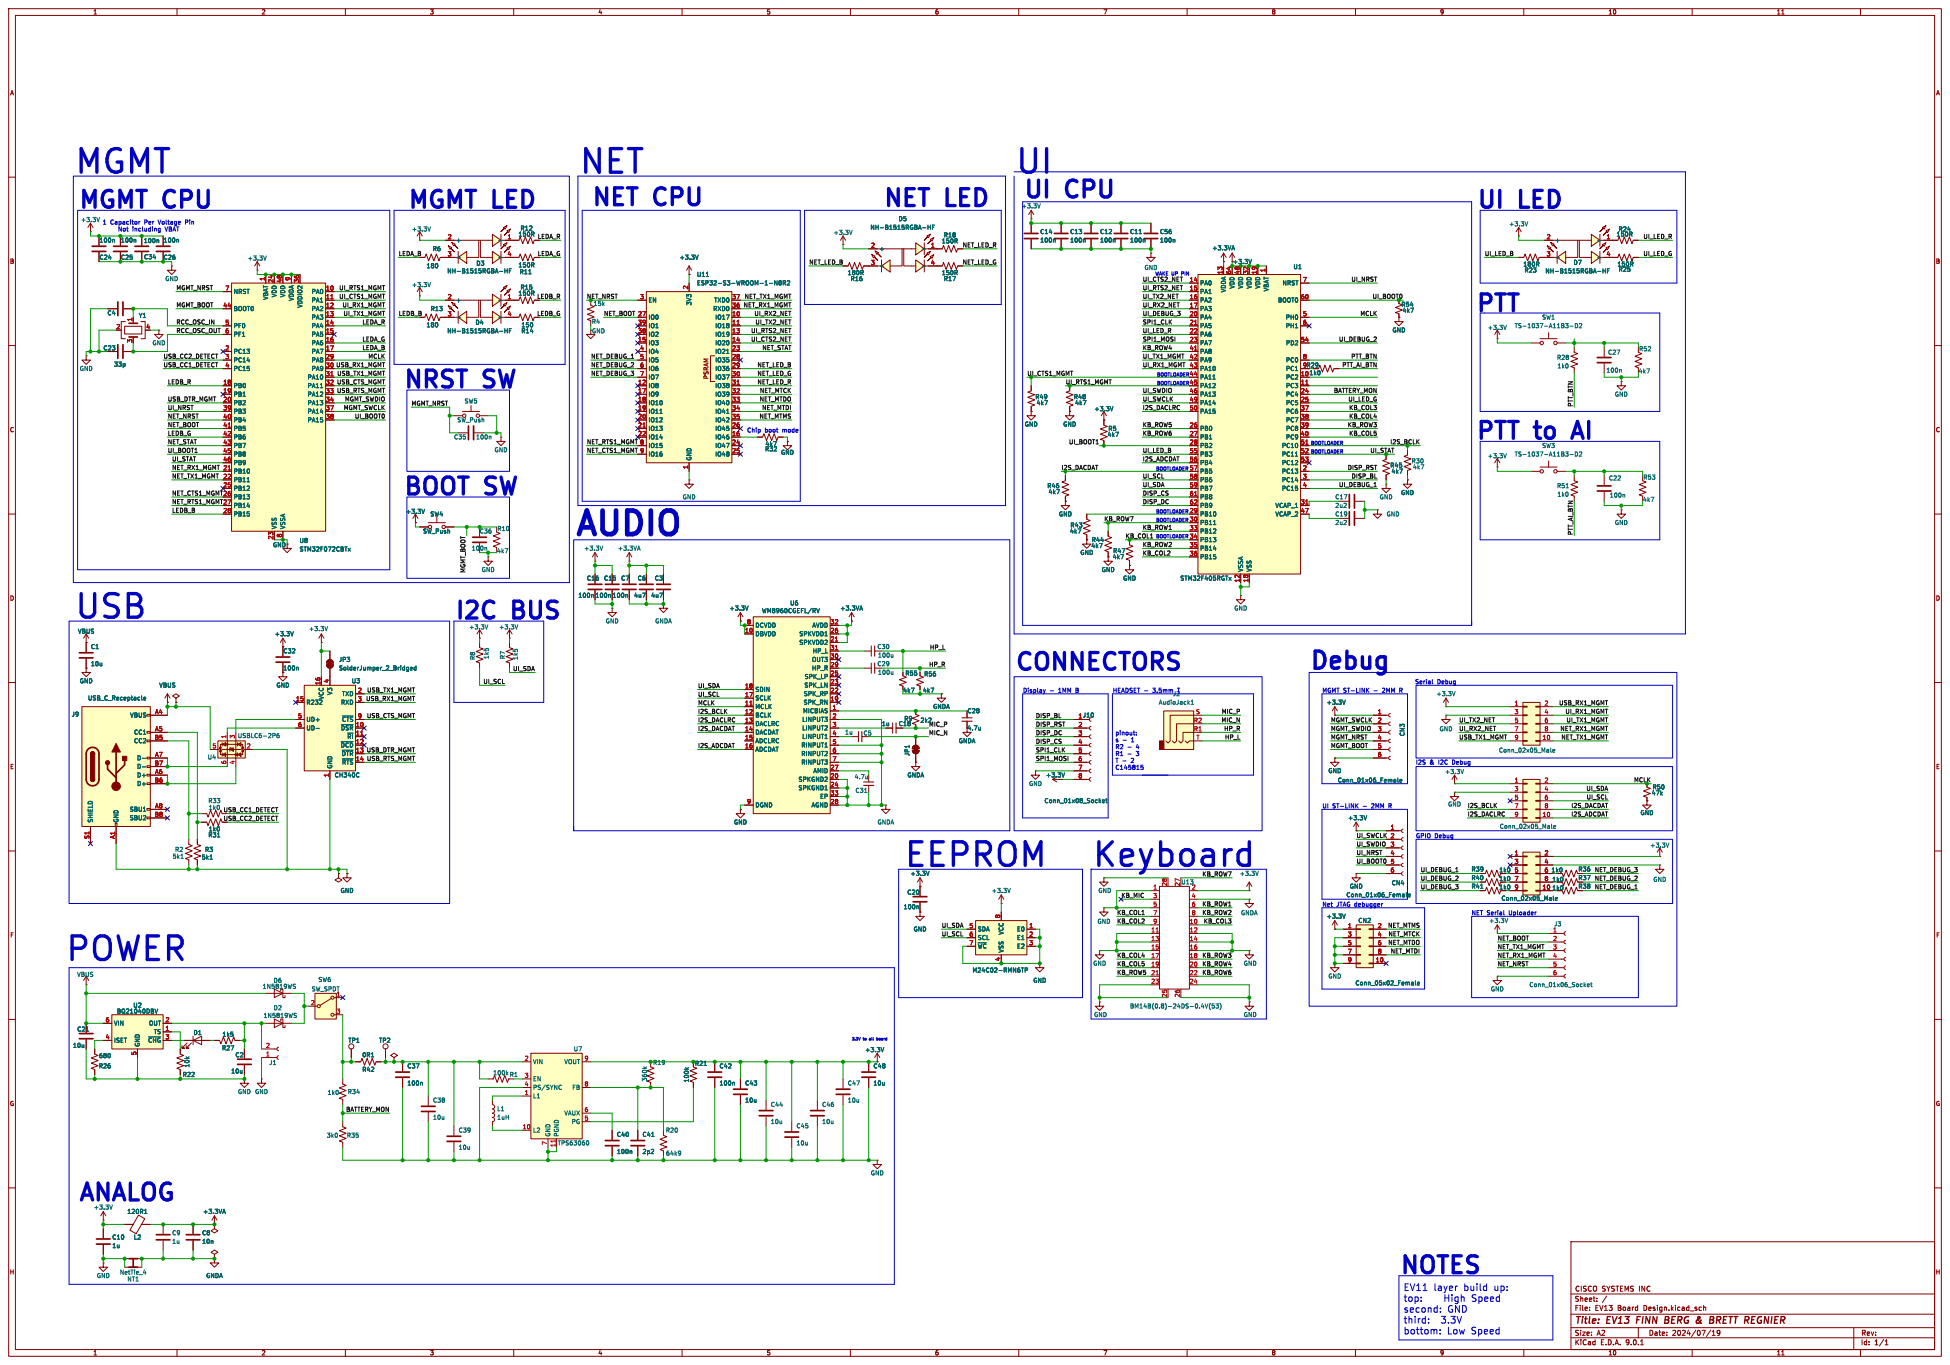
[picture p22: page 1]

WAKE UP PIN MGMT LED

1 VDD 24 VSS 23 VDD 48 VSSA

Debug Serial Debug UI ST-LINK - 2MM R MGMT ST-LINK - 2MM R NRST SW

BOOTLOADER Chip boot mode

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

1 TXD 2 RXD 3 ~{CTS}9 ~{DSR} 10 ~{RI} 11 ~{DCD} 12 ~{DTR} 13 ~{RTS} 14 U3 CH340C GND

47k +3.3V GND GND GND GND

4 SDA 5 SCL 6 ~{WC} 7 +3.3V GND

5 OUT 2 TS 1 ~{CHG}3 R22 R26 10k680 GNDA

7 PGND 11 VOUT 9 FB 8 VAUX 6 PG 5 U7 TPS63060 R20
VIN 2 EN 3 PS/SYNC 4

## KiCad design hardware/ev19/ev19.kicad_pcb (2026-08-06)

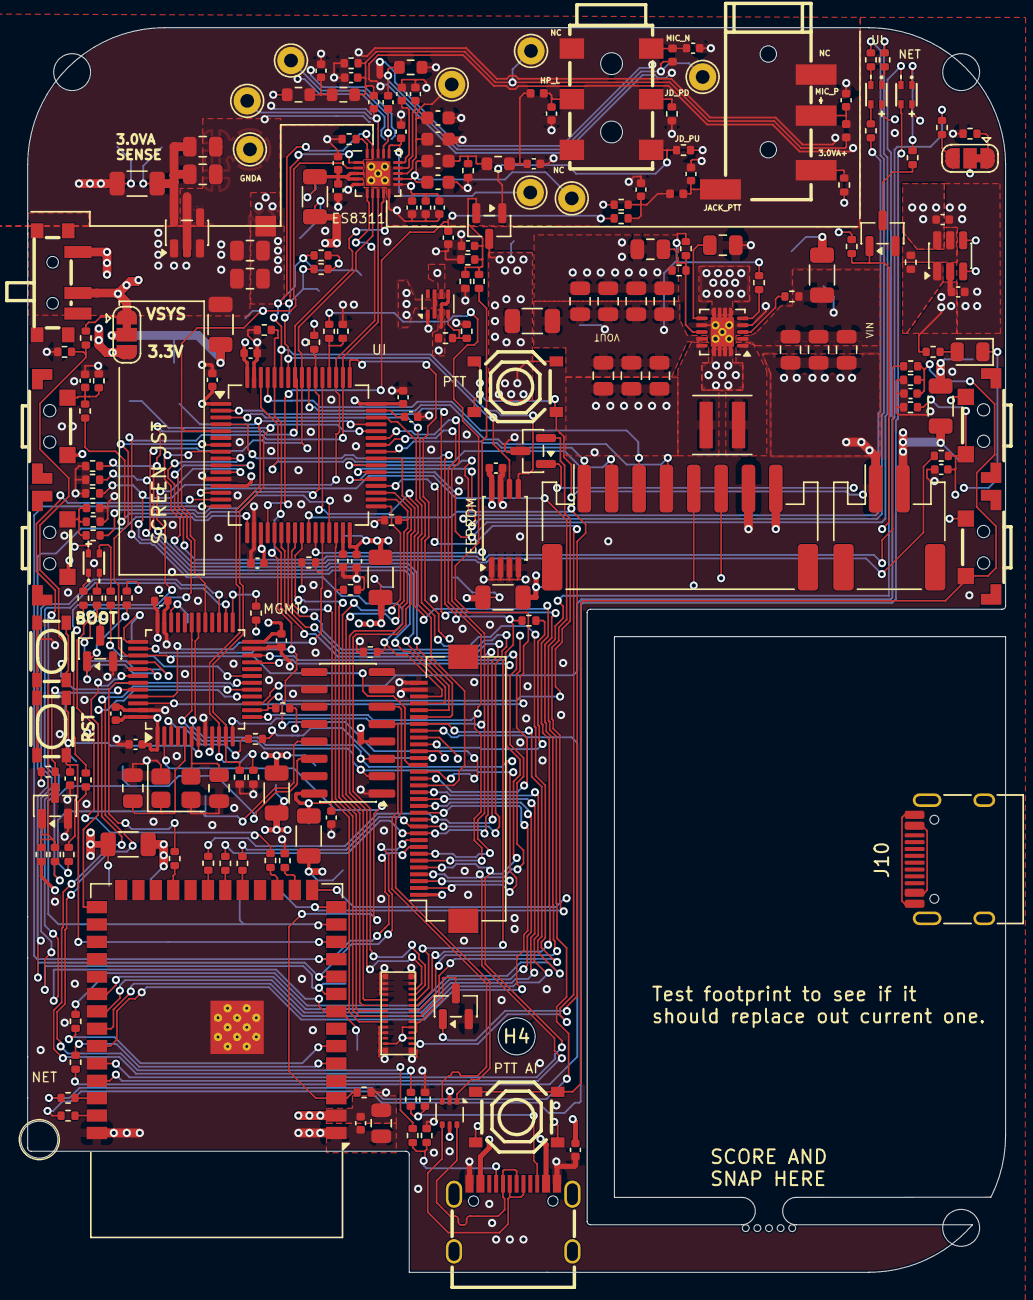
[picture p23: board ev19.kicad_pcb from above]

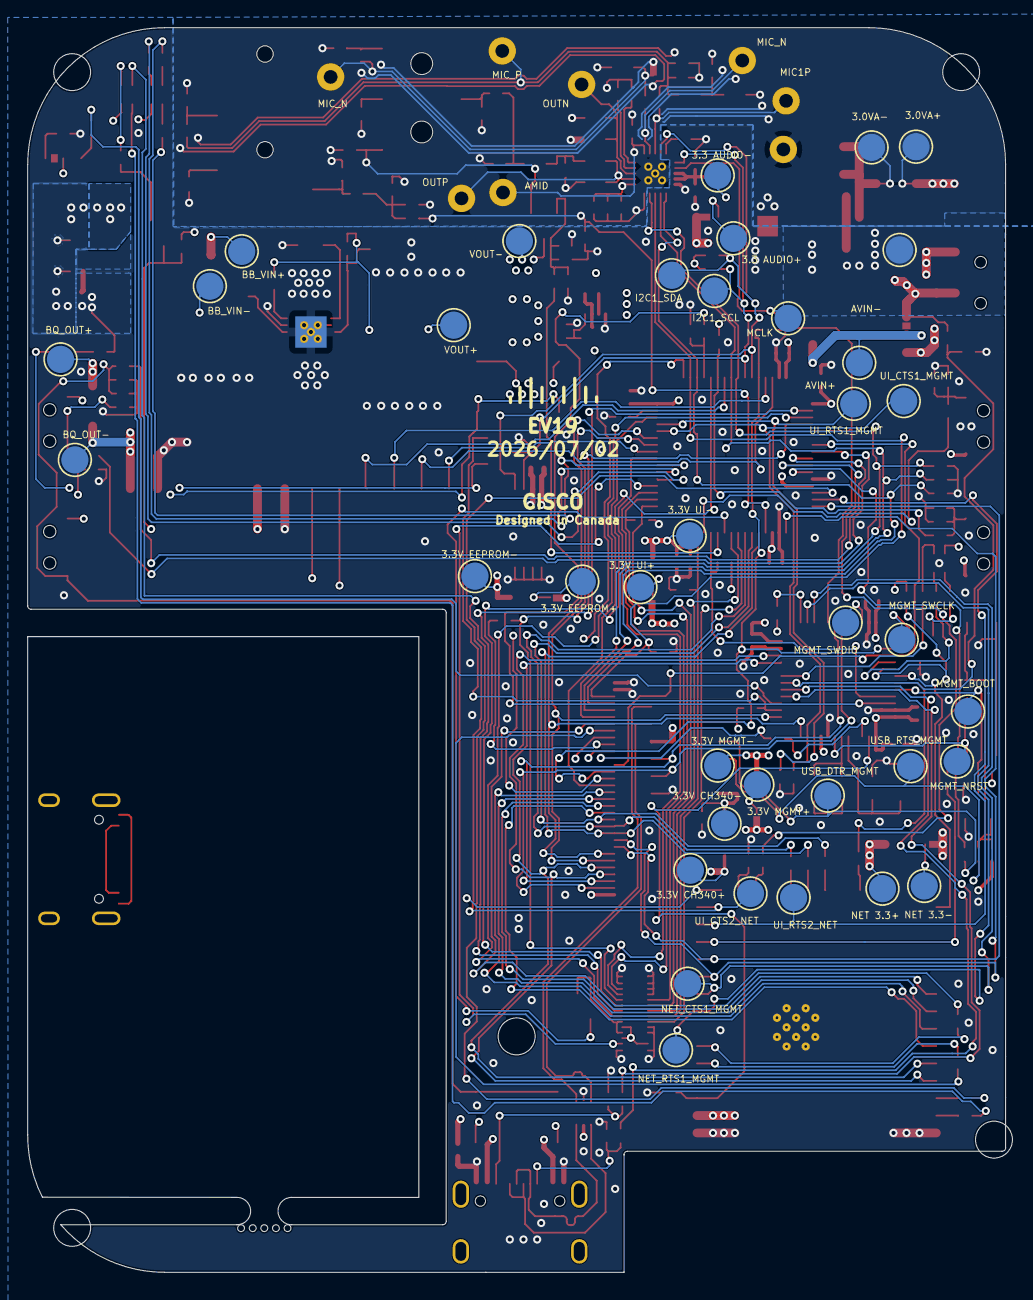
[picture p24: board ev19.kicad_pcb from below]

Board: 4 copper layers, 71.5 x 91.0 mm, 265 parts (37 on the bottom side), 192 nets.

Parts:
C1, C6, C8, C9, C13, C17, C21, C23, C25, C38, C39, C40, C41, C42, C43, C46, C47, C49, C50, C52, C53, C67: 100n; C_0402_1005Metric
C2, C3: 33p; C_0805_2012Metric
C4, C5, C12: 10u; C_0402_1005Metric
C7: 1u; C_0805_2012Metric
C10, C11, C14, C19, C22: 100n; C_0805_2012Metric
C15, C16, C51: 10u; C_0805_2012Metric
C18: 2u2; C_0805_2012Metric
C20: 2p2; C_0805_2012Metric
C24, C27, C29, C30, C31, C35: 22u; C_0805_2012Metric
C26, C28: 4u7; C_0402_1005Metric
C32, C33, C36, C37, C48, C56: 1u; C_0402_1005Metric
C34, C55: 1u; C_0603_1608Metric
C44, C45: 2u2; C_0402_1005Metric
C57, C59: 100p; C_0402_1005Metric
C58, C60, C61, C62, C63: 47p; C_0402_1005Metric
C65, C66: 22p; C_0603_1608Metric
CN3: BM14B(0.8)-24DS-0.4V(53); BM14B(0.B)-24DS-0.4V(53)
D1: LED; D_0805_2012Metric
D2, D3, D5: LED_BGAR; LED-ARRAY-SMD_4P-L1.6-W1.5-TL_NH-B1515RGBA
H1, H2, H3, H4: MountingHole; MountingHole_2.7mm_M2.5
H5: MountingHole; Standoff_Hole
J1: USB_C_Receptacle; USB-C_SMD-TYPE-C-31-M-12
J2: BATT_CONN; JST_PH_S2B-PH-SM4-TB_1x02-1MP_P2.00mm_Horizontal
J3: AudioJack4; AUDIO-SMD_PJ-320D
J6: Conn_01x32_MountingPin; Hirose_FH12-32S-0.5SH_1x32-1MP_P0.50mm_Horizontal
J10: USB_C_Receptacle; USB_C_Receptacle_HRO_TYPE-C-31-M-12
J12: PJ-242; AUDIO-SMD_PJ-242D-SMT
J14: Diplay_Connector; JST_PH_S8B-PH-SM4-TB_1x08-1MP_P2.00mm_Horizontal
JP1, JP3: SolderJumper_3_Bridged12; SolderJumper-3_P1.3mm_Bridged12_RoundedPad1.0x1.5mm
L1, L3, L4, L5: BLM15HG102SN1D; L_0402_1005Metric
L2: 1.5uH; L_Coilcraft_XxL4020
NT1: NetTie_4; NetTie-4_SMD_Pad0.5mm
NT2, NT5, NT6, NT7, NT8, NT9, NT10, NT11, NT12: NetTie_2; NetTie-2_SMD_Pad0.5mm
Q1, Q2, Q3, Q4, Q5, Q6: 2N7002; SOT-23
R1, R4, R5, R9, R10, R17, R24, R40, R44, R45, R46, R49, R50, R57, R58, R70, R71, R73, R74, R84, R89, R91, R104, R105: 1k0; R_0402_1005Metric
R2, R14, R48, R52, R63, R65, R76, R77, R78, R79, R80: 0R1; R_1206_3216Metric
R3, R25, R88: 47k; R_0402_1005Metric
R6, R12, R36, R47, R81, R87, R90, R92, R96: 10k; R_0402_1005Metric
R7, R8: 5k1; R_0402_1005Metric
R11, R16, R19: 1k5; R_0402_1005Metric
R13, R29, R53: 15k; R_0402_1005Metric
R15, R33, R56: 180R; R_0402_1005Metric
R18, R28, R32, R75: 100k; R_0402_1005Metric
R20, R21, R34, R35, R59, R60: 150R; R_0402_1005Metric
R22, R23, R30, R37, R38, R39, R41, R42, R43, R51, R54, R55, R61, R62, R66, R67, R68, R69, R95: 4k7; R_0402_1005Metric
R26: 360k; R_0402_1005Metric
R27: 64k9; R_0402_1005Metric
R31: 220R; R_0603_1608Metric
R83: 4R7; R_0603_1608Metric
R86: 33k; R_0402_1005Metric
R93, R94: 2k2; R_0603_1608Metric
SW1: SW_SPDT; SW-SMD_MK-12C02-G020
SW2, SW3: SW_Push; KEY-SMD_4P-L4.2-W3.2-P2.20-LS4.6
SW4, SW5, SW6, SW7: SW_Push; SW-SMD_SHOU_TS36CA-0.6
SW9, SW10: SW_Push; SW-SMD_4P-L5.1-W5.1-P3.70-LS6.5-TL_H1.5
TP1, TP2, TP3, TP5, TP6, TP7, TP8, TP9: TestPoint; TestPoint_THTPad_D2.0mm_Drill1.0mm
TP11, TP12, TP13, TP14, TP15, TP16, TP17, TP18, TP19, TP20, TP21, TP22, TP23, TP24, TP25, TP26, TP27, TP28, TP29, TP30, TP31, TP32, TP33, TP34, TP35, TP36, TP37, TP38, TP39, TP40, TP43, TP44, TP45, TP47, TP48, TP49, TP50: TestPoint; TestPoint_Pad_D2.0mm
U1: BQ21040DBV; SOT-23-6
U2: USBLC6-2P6; SOT-666
U3: STM32F072CBTx; LQFP-48_7x7mm_P0.5mm
U4: CH340C; SOIC-16_3.9x9.9mm_P1.27mm
U5: TPS63060; Texas_S-PWSON-N10_ThermalVias
U6: ES8311; QFN-20-1EP_3x3mm_P0.4mm_EP1.8x1.8mm_ThermalVias
U7: ESP32-S3-WROOM-1
U8: M24C02-RDW6TP; TSSOP-8_4.4x3mm_P0.65mm
U9: TPS2116DRL; SOT-583-8
U10: STM32F405RGTx; LQFP-64_10x10mm_P0.5mm
U12: XC6227C301MR-G; SOT-23-5
Y1: Crystal_GND24; Crystal_SMD_3225-4Pin_3.2x2.5mm

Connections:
+3.0VA: C25.2, C26.1, C28.1, R31.2, R36.2, R52.2, R87.2, R90.1, TP28.1 (1_1), U6.11 (AVDD)
+3.3V: CN3.2, CN3.24, CN3.26, D2.2 (A), D3.2 (A), D5.2 (A), J6.1, J14.8, JP3.3 (B), NT5.1, NT6.1, NT7.1, NT8.1, NT9.1, NT10.1, Q6.3 (D), R3.2, R16.1, R19.1, R22.2, R25.2, R41.1, R48.2, R75.2, R88.2, SW4.1, SW5.1, SW6.1, SW7.1, SW9.1, SW9.2, SW10.1, SW10.2, TP24.1 (1_1)
+3.3V_AUDIO: C21.2, C23.2, R63.2, TP13.1 (1_1), U6.3 (PVDD), U6.4 (DVDD)
+3.3V_CH340C: C13.1, NT2.2, R80.2, TP21.1 (1_1), U4.16 (VCC)
+3.3V_EEPROM: C38.2, R79.2, TP12.1 (1_1), U8.8 (VCC)
+3.3V_Mgmt: C1.2, C6.2, C8.2, C9.2, R77.2, TP19.1 (1_1), U3.1 (VBAT), U3.9 (VDDA), U3.24 (VDD), U3.36 (VDDIO2), U3.48 (VDD)
+3.3V_Net: C51.1, C52.1, R76.2, TP17.1 (1_1), U7.2 (3V3)
+3.3V_UI: C39.1, C40.1, C41.1, C42.1, C43.1, R78.2, TP15.1 (1_1), U10.1 (VBAT), U10.13 (VDDA), U10.19 (VDD), U10.32 (VDD), U10.48 (VDD), U10.64 (VDD)
+5V: J10.A4 (VBUS), J10.A9 (VBUS), J10.B4 (VBUS), J10.B9 (VBUS)
/3.3V_AUDIO_SENSE: NT9.2, R63.1, TP14.1 (1_1)
/AVIN: C7.1, C11.1, R2.2, TP30.1 (1_1), U12.1 (VIN), U12.3 (CE)
/Analog_Sense: C10.1, C18.1, R52.1, TP27.1 (1_1), U12.5 (VOUT)
/Audio/AMID: C48.1, TP7.1 (1_1), U6.16 (VMID)
/Audio/Jack_HP_L: C57.1, J12.T, L1.2
/Audio/Jack_MIC_N: C59.1, J12.S, L3.2
/Audio/Jack_MIC_P: C60.1, J3.R1, L4.1
/Audio/Jack_PTT: C62.1, J3.S, L5.1
/Audio/MIC1N: C32.1, TP3.1 (1_1), U6.17 (MIC1N)
/Audio/MIC1P: C36.1, TP1.1 (1_1), U6.18 (MIC1P)
/Audio/MIC_N: C32.2, L3.1, NT12.2, R94.2, TP9.1 (1_1)
/Audio/MIC_P: C36.2, C61.1, L4.2, R86.2, R93.1, TP2.1 (1_1)
/Audio/MIC_PTT_BTN: C53.1, R81.2, U10.20 (PA4)
/Audio/OUTN: C55.1, C65.2, TP6.1 (1_1), U6.13 (OUTN)
/Audio/OUTP: C34.1, C66.1, TP5.1 (1_1), U6.12 (OUTP)
/Audio/nJACK_R1N: C67.1, Q6.2 (S), R89.1, R95.2, R96.1
/BATTERY_MON: R12.1, R13.1, U3.18 (PB0)
/BB_Vin_Sense: C14.1, C15.1, C16.1, R14.2, R18.1, TP26.1 (1_1), U5.2 (VIN)
/BB_Vout: C22.1, C24.1, C27.1, C29.1, C30.1, C31.1, C35.1, R26.2, R28.2, R48.1, TP23.1 (1_1), U5.9 (VOUT)
/BQ_OUT: C12.1, R11.1, R65.1, TP31.1 (1_1), U1.2 (OUT)
/CH340C_SENSE: NT5.2, R80.1, TP22.1 (1_1)
/CHG_FB: Q2.2 (S), R3.1, U3.14 (PA4)
/D_N: J1.A7 (D-), J1.B7 (D-), U2.6 (I/O1)
/D_P: J1.A6 (D+), J1.B6 (D+), U2.4 (I/O2)
/EEPROM_SENSE: NT10.2, R79.1, TP11.1 (1_1)
/I2C1_SCL: R19.2, TP44.1 (1_1), U6.1 (SCL), U8.6 (SCL), U10.58 (PB6)
/I2C1_SDA: R16.2, TP45.1 (1_1), U6.19 (SDA), U8.5 (SDA), U10.59 (PB7)
/I2S_ADCDAT: J6.28, R69.1, U6.7 (ASDOUT), U10.56 (PB4)
/I2S_BCLK: J6.29, R68.1, U6.6 (BCLK), U10.51 (PC10)
/I2S_DACDAT: J6.27, R67.1, U6.9 (DSDIN), U10.57 (PB5)
/I2S_DACLRC: J6.30, R66.1, U6.8 (LRCK), U10.50 (PA15)
/MCLK: TP33.1 (1_1), U3.29 (PA8), U6.2 (MCLK), U10.5 (PH0)
/MGMT_BOOT: Q3.3 (D), R22.1, TP49.1 (1_1), U3.44 (BOOT0)
/MGMT_DAC2: R91.1, U3.15 (PA5)
/MGMT_DEBUG_1: R70.1, U3.3 (PC14)
/MGMT_DEBUG_2: R71.1, U3.25 (PB12)
/MGMT_LED_B: R15.2, U3.19 (PB1)
/MGMT_LED_G: R21.2, U3.40 (PB4)
/MGMT_LED_R: Q1.1 (G), R25.1, U3.41 (PB5)
/MGMT_NRST: C17.1, R40.1, SW3.3, SW3.4, TP50.1 (1_1), U3.7 (NRST)
/MGMT_SENSE: NT6.2, R77.1, TP20.1 (1_1)
/MGMT_SWCLK: TP47.1 (1_1), U3.37 (PA14)
/MGMT_SWDIO: TP48.1 (1_1), U3.34 (PA13)
/NET_BOOT: U3.42 (PB6), U7.27 (IO0)
/NET_CTS1_MGMT: TP37.1 (1_1), U3.27 (PB14), U7.9 (IO16)
/NET_DEBUG_1: R104.2, U7.5 (IO5)
/NET_DEBUG_2: R105.2, U7.6 (IO6)
/NET_LED_B: R33.1, U7.39 (IO1)
/NET_LED_G: R35.1, U7.38 (IO2)
/NET_LED_R: Q4.1 (G), R88.1, U7.15 (IO3)
/NET_MTCK: J6.14, U7.32 (IO39)
/NET_MTDI: J6.16, U7.34 (IO41)
/NET_MTDO: J6.15, U7.33 (IO40)
/NET_MTMS: J6.13, U7.35 (IO42)
/NET_NRST: R29.1, U3.2 (PC13), U7.3 (EN)
/NET_READY: R50.1, U7.12 (IO8)
/NET_RTS1_MGMT: TP36.1 (1_1), U3.26 (PB13), U7.8 (IO15)
/NET_RX1_MGMT: J6.5, U3.21 (PB10), U7.36 (RXD0)
/NET_SENSE: NT7.2, R76.1, TP18.1 (1_1)
/NET_STAT: R4.2, U7.23 (IO21)
/NET_TX1_MGMT: J6.4, U3.22 (PB11), U7.37 (TXD0)
/RCC_OSC_IN: C2.2, U3.5 (PF0), Y1.1
/RCC_OSC_OUT: C3.2, U3.6 (PF1), Y1.3
/SPI1_CLK: J6.10, J14.5, R44.1, U10.21 (PA5)
/SPI1_MISO: J6.12, R45.1, U10.22 (PA6)
/SPI1_MOSI: J6.11, J14.6, R46.1, U10.23 (PA7)
/UD_N: U2.1 (I/O1), U4.6 (UD-)
/UD_P: U2.3 (I/O2), U4.5 (UD+)
/UI MCU/DISP_BL: J14.1, U10.41 (PA8)
/UI MCU/DISP_CS: J14.4, U10.55 (PB3)
/UI MCU/DISP_DC: J14.3, U10.61 (PB8)
/UI MCU/DISP_RST: J14.2, U10.62 (PB9)
/UI MCU/KB_COL1: CN3.7, R42.2, U10.30 (PB11)
/UI MCU/KB_COL2: CN3.9, U10.33 (PB12)
/UI MCU/KB_COL3: CN3.10, R43.2, U10.34 (PB13)
/UI MCU/KB_COL4: CN3.17, U10.35 (PB14)
/UI MCU/KB_LEDS: Q5.1 (G), U10.26 (PB0)
/UI MCU/KB_ROW1: CN3.6, U10.24 (PC4)
/UI MCU/KB_ROW2: CN3.8, U10.25 (PC5)
/UI MCU/KB_ROW3: CN3.18, U10.40 (PC9)
/UI MCU/KB_ROW4: CN3.20, U10.53 (PC12)
/UI MCU/KB_ROW5: CN3.21, U10.2 (PC13)
/UI MCU/KB_ROW6: CN3.22, U10.3 (PC14)
/UI MCU/KB_ROW7: CN3.27, U10.36 (PB15)
/UI MCU/PTT_AI_BTN: R58.1, U10.9 (PC1)
/UI MCU/PTT_BTN: R57.1, U10.8 (PC0)
/UI MCU/UI_LED_B: R56.1, U10.39 (PC8)
/UI MCU/UI_LED_G: R60.1, U10.38 (PC7)
/UI MCU/UI_LED_R: R59.1, U10.37 (PC6)
/UI MCU/VOLUME+: R17.1, U10.29 (PB10)
/UI_BOOT0: J6.19, R55.1, U3.38 (PA15), U10.60 (BOOT0)
/UI_BOOT1: R41.2, U3.45 (PB8), U10.28 (PB2)
/UI_CTS1_MGMT: R38.2, TP39.1 (1_1), U3.11 (PA1), U10.44 (PA11)
/UI_CTS2_NET: TP43.1 (1_1), U7.14 (USB_D+), U10.14 (PA0)
/UI_NRST: J6.20, U3.39 (PB3), U10.7 (NRST)
/UI_READY: R49.1, U7.17 (IO9)
/UI_RTS1_MGMT: R39.2, TP38.1 (1_1), U3.10 (PA0), U10.45 (PA12)
/UI_RTS2_NET: TP40.1 (1_1), U7.13 (USB_D-), U10.15 (PA1)
/UI_RX1_MGMT: J6.7, U3.12 (PA2), U10.43 (PA10)
/UI_RX2_NET: J6.9, U7.10 (IO17), U10.17 (PA3)
/UI_SENSE: NT8.2, R78.1, TP16.1 (1_1)
/UI_STAT: R5.2, R54.2, U10.52 (PC11)
/UI_SWCLK: J6.17, U10.46 (PA13)
/UI_SWDIO: J6.18, U10.49 (PA14)
/UI_TX1_MGMT: J6.6, U3.13 (PA3), U10.42 (PA9)
/UI_TX2_NET: J6.8, U7.11 (IO18), U10.16 (PA2)
/USB_CC1_DETECT: R9.1, U3.16 (PA6)
/USB_CC2_DETECT: R10.1, U3.17 (PA7)
/USB_DTR_MGMT: R40.2, TP34.1 (1_1), U4.13 (~DTR)
/USB_RTS_MGMT: R51.1, TP35.1 (1_1), U4.14 (~RTS)
/USB_RX1_MGMT: J6.3, U3.30 (PA9), U4.3 (RXD)
/USB_TX1_MGMT: J6.2, U3.31 (PA10), U4.2 (TXD)
GND: C1.1, C2.1, C3.1, C4.2, C5.2, C6.1, C7.2, C8.1, C9.1, C11.2, C12.2, C13.2, C14.2, C15.2, C16.2, C17.2, C19.2, C20.2, C21.1, C22.2, C23.1, C24.2, C27.2, C29.2, C30.2, C31.2, C35.2, C38.1, C39.2, C40.2, C41.2, C42.2, C43.2, C44.1, C45.1, C46.2, C47.2, C49.2, C50.2, C51.2, C52.2, C53.2, C67.2, CN3.1, CN3.4, CN3.5, CN3.11, CN3.12, CN3.13, CN3.14, CN3.15, CN3.16, CN3.28, J1.A1 (GND), J1.A12 (GND), J1.B1 (GND), J1.B12 (GND), J2.1, J6.31, J6.32, J14.7, NT1.1, NT1.3, Q1.2 (S), Q2.3 (D), Q3.2 (S), Q4.2 (S), Q5.2 (S), R1.2, R6.2, R7.1, R8.1, R13.2, R23.1, R27.1, R29.2, R30.2, R37.1, R38.1, R39.1, R42.1, R43.1, R47.1, R54.1, R55.2, R61.1, R62.1, R66.2, R67.2, R68.2, R69.2, R92.1, R95.1, R96.2, SW2.1, SW2.2, SW3.1, SW3.2, U1.5 (GND), U2.2 (GND), U3.8 (VSSA), U3.23 (VSS), U3.35 (VSS), U3.47 (VSS), U4.1 (GND), U5.4 (PS/SYNC), U5.7 (GND), U5.11 (PGND), U6.5 (DGND), U7.1 (GND), U7.40 (GND), U7.41 (GND), U8.1 (E0), U8.2 (E1), U8.3 (E2), U8.4 (VSS), U8.7 (~WC), U9.1 (GND), U10.12 (VSSA), U10.18 (VSS), U10.63 (VSS), Y1.2 (G), Y1.4 (G)
GND1: J10.A1 (GND), J10.A12 (GND), J10.B1 (GND), J10.B12 (GND)
GNDA: C10.2, C18.2, C25.1, C26.2, C28.2, C33.2, C37.2, C48.2, C56.2, C57.2, C58.2, C59.2, C60.2, C61.2, C62.2, C63.2, C65.1, C66.2, NT1.2, NT1.4, NT11.1, NT12.1, R32.1, R84.2, R86.1, R94.1, TP8.1 (1_1), U6.10 (AGND), U6.21 (PAD), U12.2 (VSS)
unnamed: C34.2, R32.2, R83.1
unnamed: C46.1, R57.2, R61.2, SW4.2, SW9.3, SW9.4
unnamed: C47.1, R58.2, R62.2, SW5.2, SW10.3, SW10.4
unnamed: C49.1, R17.2, R23.2, SW6.2
unnamed: C50.1, R24.2, R37.2, SW7.2
unnamed: C55.2, NT11.2
unnamed: C56.1, R31.1, R93.2
unnamed: C58.1, L1.1, R83.2
unnamed: C63.1, L5.2, R36.1, R81.1
unnamed: D1.2 (A), R11.2
unnamed: D1.1 (K), Q2.1 (G), U1.3 (~CHG)
unnamed: D2.3 (BK), R33.2
unnamed: D2.4 (GK), R35.2
unnamed: D2.1 (RK), R34.2
unnamed: D3.3 (BK), R56.2
unnamed: D3.4 (GK), R60.2
unnamed: D3.1 (RK), R59.2
unnamed: D5.3 (BK), R15.1
unnamed: D5.4 (GK), R21.1
unnamed: D5.1 (RK), R20.1
unnamed: J1.A5 (CC1), R8.2, R10.2
unnamed: J1.B5 (CC2), R7.2, R9.2
unnamed: J2.2, R65.2, TP32.1 (1_1), U9.6 (VIN2)
unnamed: J3.T, R87.1
unnamed: J6.21, R70.2
unnamed: J6.22, R71.2
unnamed: J6.23, R74.1
unnamed: J6.24, R73.1
unnamed: J6.25, R104.1
unnamed: J6.26, R105.1
unnamed: J12.R1, R84.1
unnamed: JP1.1 (A), R1.1
unnamed: JP1.3 (B), R91.2
unnamed: JP1.2 (C), U1.4 (ISET)
unnamed: JP3.2 (C), R2.1, TP29.1 (1_1)
unnamed: Q1.3 (D), R20.2
unnamed: Q3.1 (G), R51.2, R75.1, SW2.3, SW2.4
unnamed: Q4.3 (D), R34.1
unnamed: CN3.23, CN3.25, Q5.3 (D)
unnamed: J12.R1N, Q6.1 (G), R90.2
unnamed: SW1.1 (A), U9.2 (VOUT), U9.7 (VOUT)
unnamed: R6.1, U1.1 (TS)
unnamed: R4.1, U3.43 (PB7)
unnamed: R5.1, U3.46 (PB9)
unnamed: NT2.1, U4.4 (V3)
unnamed: R18.2, U5.3 (EN)
unnamed: C20.1, R26.1, R27.2, U5.8 (FB)
unnamed: L2.1, U5.1 (L1)
unnamed: L2.2, U5.10 (L2)
unnamed: R28.1, U5.5 (PG)
unnamed: C19.1, U5.6 (VAUX)
unnamed: C37.1, U6.15 (ADCVREF)
unnamed: R92.2, U6.20 (CE)
unnamed: C33.1, U6.14 (DACVREF)
unnamed: R46.2, U7.19 (IO11)
unnamed: R44.2, U7.20 (IO12)
unnamed: R45.2, U7.21 (IO13)
unnamed: R30.1, U7.16 (IO46)
unnamed: R47.2, R53.1, U9.4 (PR1)
unnamed: R89.2, U10.27 (PB1)
unnamed: R49.2, U10.10 (PC2)
unnamed: R50.2, U10.11 (PC3)
unnamed: C44.2, U10.31 (VCAP_1)
unnamed: C45.2, U10.47 (VCAP_2)
UI_DEBUG_1: CN3.19, R74.2, U10.4 (PC15)
UI_DEBUG_2: R24.1, R73.2, U10.54 (PD2)
VBUS: C4.1, C5.1, J1.A4 (VBUS), J1.A9 (VBUS), J1.B4 (VBUS), J1.B9 (VBUS), R53.2, U1.6 (VIN), U2.5 (VBUS), U9.3 (VIN1), U9.5 (MODE)
VSYS: JP3.1 (A), R12.2, R14.1, SW1.2 (B), TP25.1 (1_1)

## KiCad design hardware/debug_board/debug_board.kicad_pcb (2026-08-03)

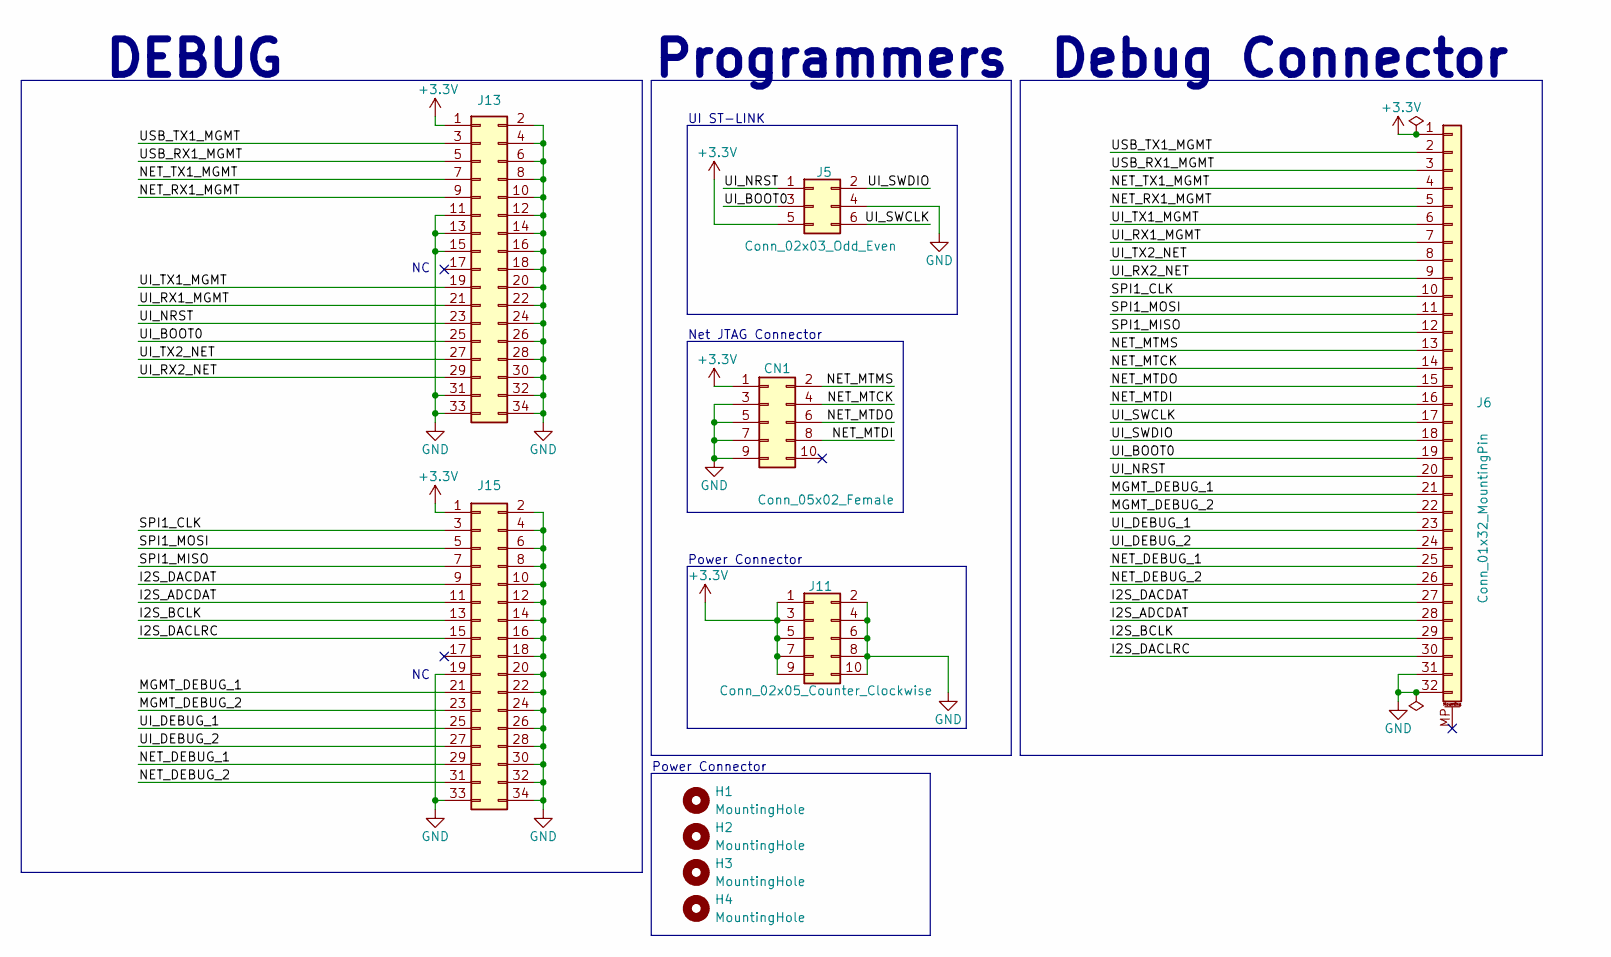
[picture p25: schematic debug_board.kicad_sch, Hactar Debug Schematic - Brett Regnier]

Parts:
CN1: Conn_05x02_Female; IDC-SMD_10P-P1.27_X1270WVS-2X05B-6TV01; JLCPCB Part # C2962222
H1, H2, H3, H4: MountingHole; MountingHole_2.7mm_M2.5
J5: Conn_02x03_Odd_Even; PinHeader_2x03_P2.54mm_Vertical_SMD; JLCPCB Part # C3294461
J6: Conn_01x32_MountingPin; Hirose_FH12-32S-0.5SH_1x32-1MP_P0.50mm_Horizontal; JLCPCB Part # C597985
J11: Conn_02x05_Counter_Clockwise; PinSocket_2x05_P2.54mm_Vertical_SMD; JLCPCB Part # C3975150
J13, J15: Conn_02x17_Counter_Clockwise; PinHeader_2x17_P2.54mm_Vertical_SMD; JLCPCB Part # C22436164

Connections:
+3.3V: CN1.1, J5.5, J6.1, J11.1, J11.3, J11.5, J11.7, J11.9, J13.1, J15.1
/I2S_ADCDAT: J6.28, J15.11
/I2S_BCLK: J6.29, J15.13
/I2S_DACDAT: J6.27, J15.9
/I2S_DACLRC: J6.30, J15.15
/MGMT_DEBUG_1: J6.21, J15.21
/MGMT_DEBUG_2: J6.22, J15.23
/NET_DEBUG_1: J6.25, J15.29
/NET_DEBUG_2: J6.26, J15.31
/NET_MTCK: CN1.4, J6.14
/NET_MTDI: CN1.8, J6.16
/NET_MTDO: CN1.6, J6.15
/NET_MTMS: CN1.2, J6.13
/NET_RX1_MGMT: J6.5, J13.9
/NET_TX1_MGMT: J6.4, J13.7
/SPI1_CLK: J6.10, J15.3
/SPI1_MISO: J6.12, J15.7
/SPI1_MOSI: J6.11, J15.5
/UI_BOOT0: J5.3, J6.19, J13.25
/UI_DEBUG_1: J6.23, J15.25
/UI_DEBUG_2: J6.24, J15.27
/UI_NRST: J5.1, J6.20, J13.23
/UI_RX1_MGMT: J6.7, J13.21
/UI_RX2_NET: J6.9, J13.29
/UI_SWCLK: J5.6, J6.17
/UI_SWDIO: J5.2, J6.18
/UI_TX1_MGMT: J6.6, J13.19
/UI_TX2_NET: J6.8, J13.27
/USB_RX1_MGMT: J6.3, J13.5
/USB_TX1_MGMT: J6.2, J13.3
GND: CN1.3, CN1.5, CN1.7, CN1.9, J5.4, J6.31, J6.32, J11.2, J11.4, J11.6, J11.8, J11.10, J13.2, J13.4, J13.6, J13.8, J13.10, J13.11, J13.12, J13.13, J13.14, J13.15, J13.16, J13.18, J13.20, J13.22, J13.24, J13.26, J13.28, J13.30, J13.31, J13.32, J13.33, J13.34, J15.2, J15.4, J15.6, J15.8, J15.10, J15.12, J15.14, J15.16, J15.18, J15.19, J15.20, J15.22, J15.24, J15.26, J15.28, J15.30, J15.32, J15.33, J15.34

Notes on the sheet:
Programmers
UI ST-LINK
Net JTAG Connector
DEBUG
Power Connector
Debug Connector

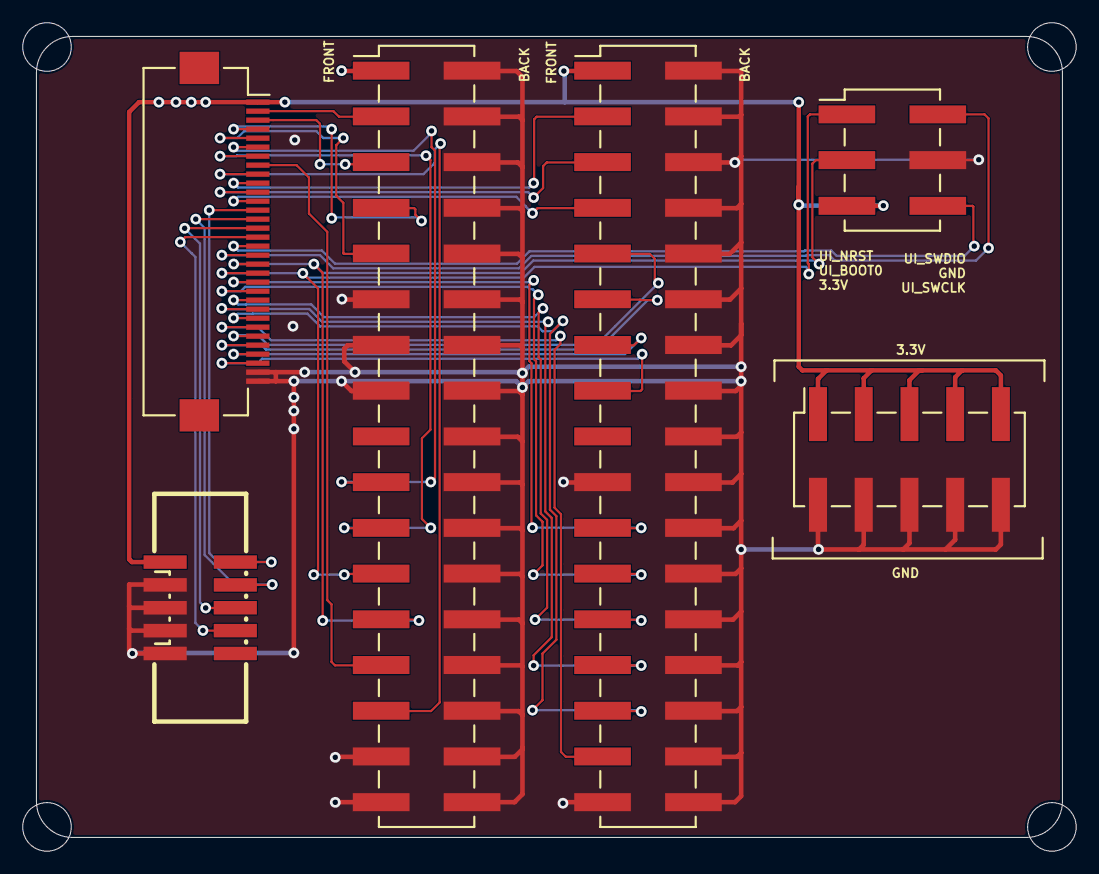
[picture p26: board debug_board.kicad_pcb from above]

Board: 4 copper layers, 57.0 x 44.5 mm, 10 parts (0 on the bottom side), 31 nets.

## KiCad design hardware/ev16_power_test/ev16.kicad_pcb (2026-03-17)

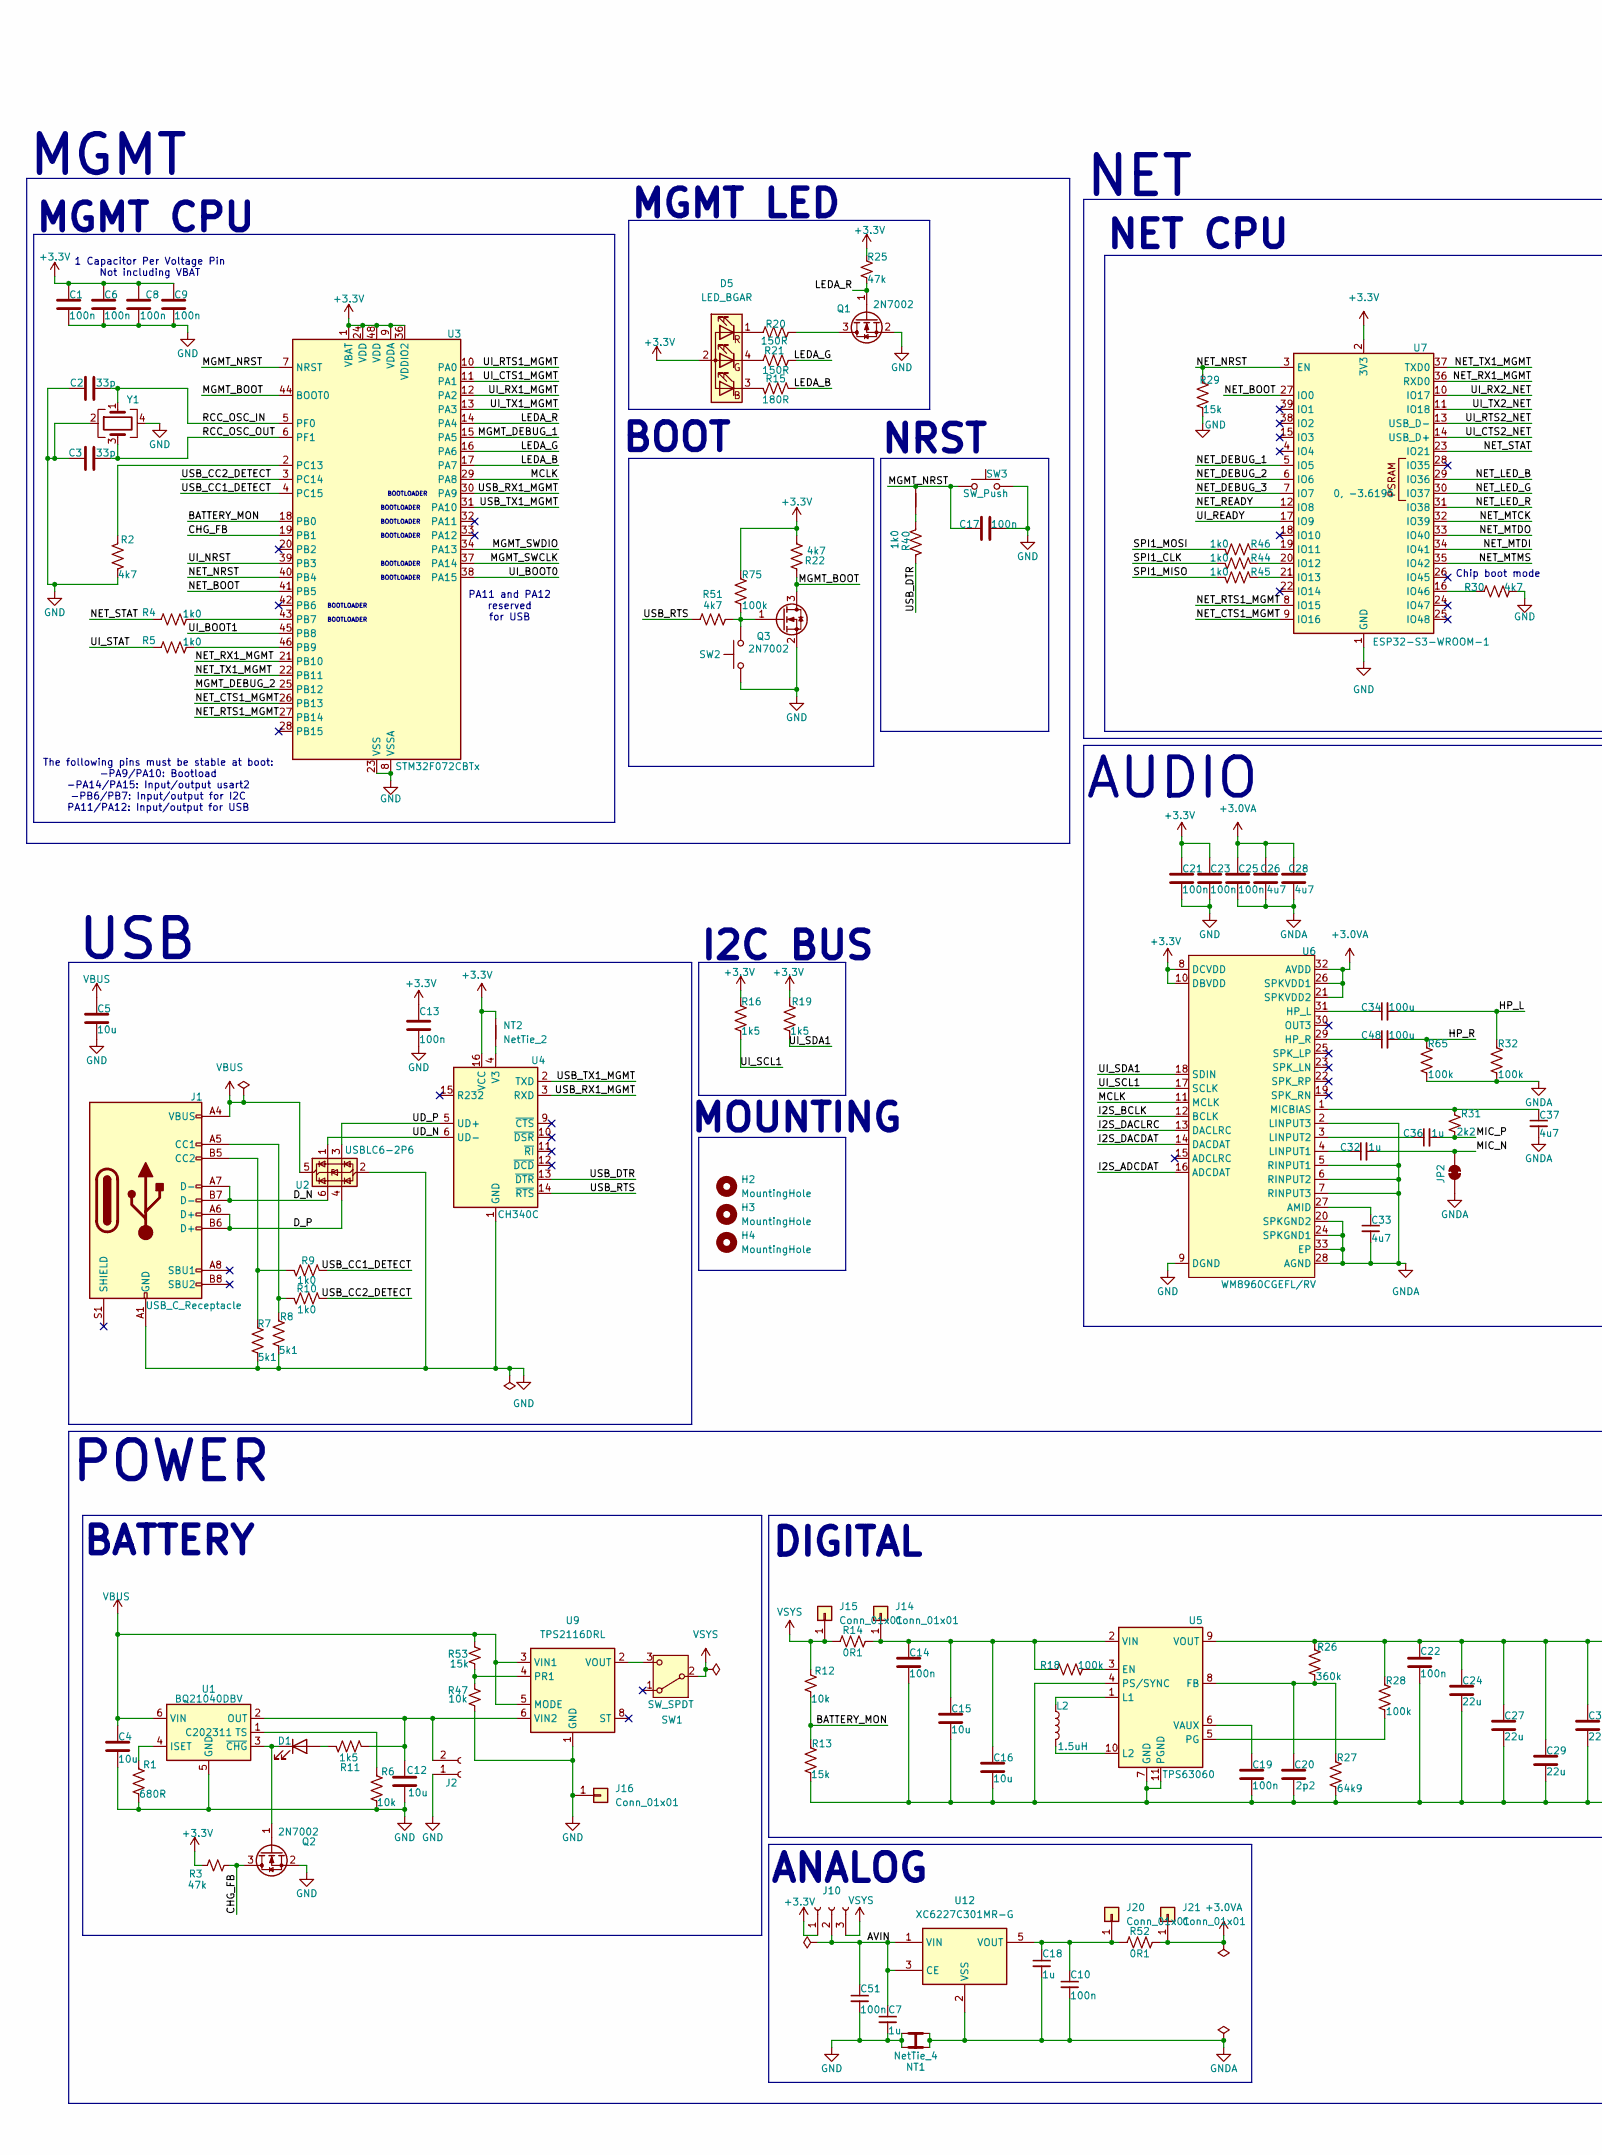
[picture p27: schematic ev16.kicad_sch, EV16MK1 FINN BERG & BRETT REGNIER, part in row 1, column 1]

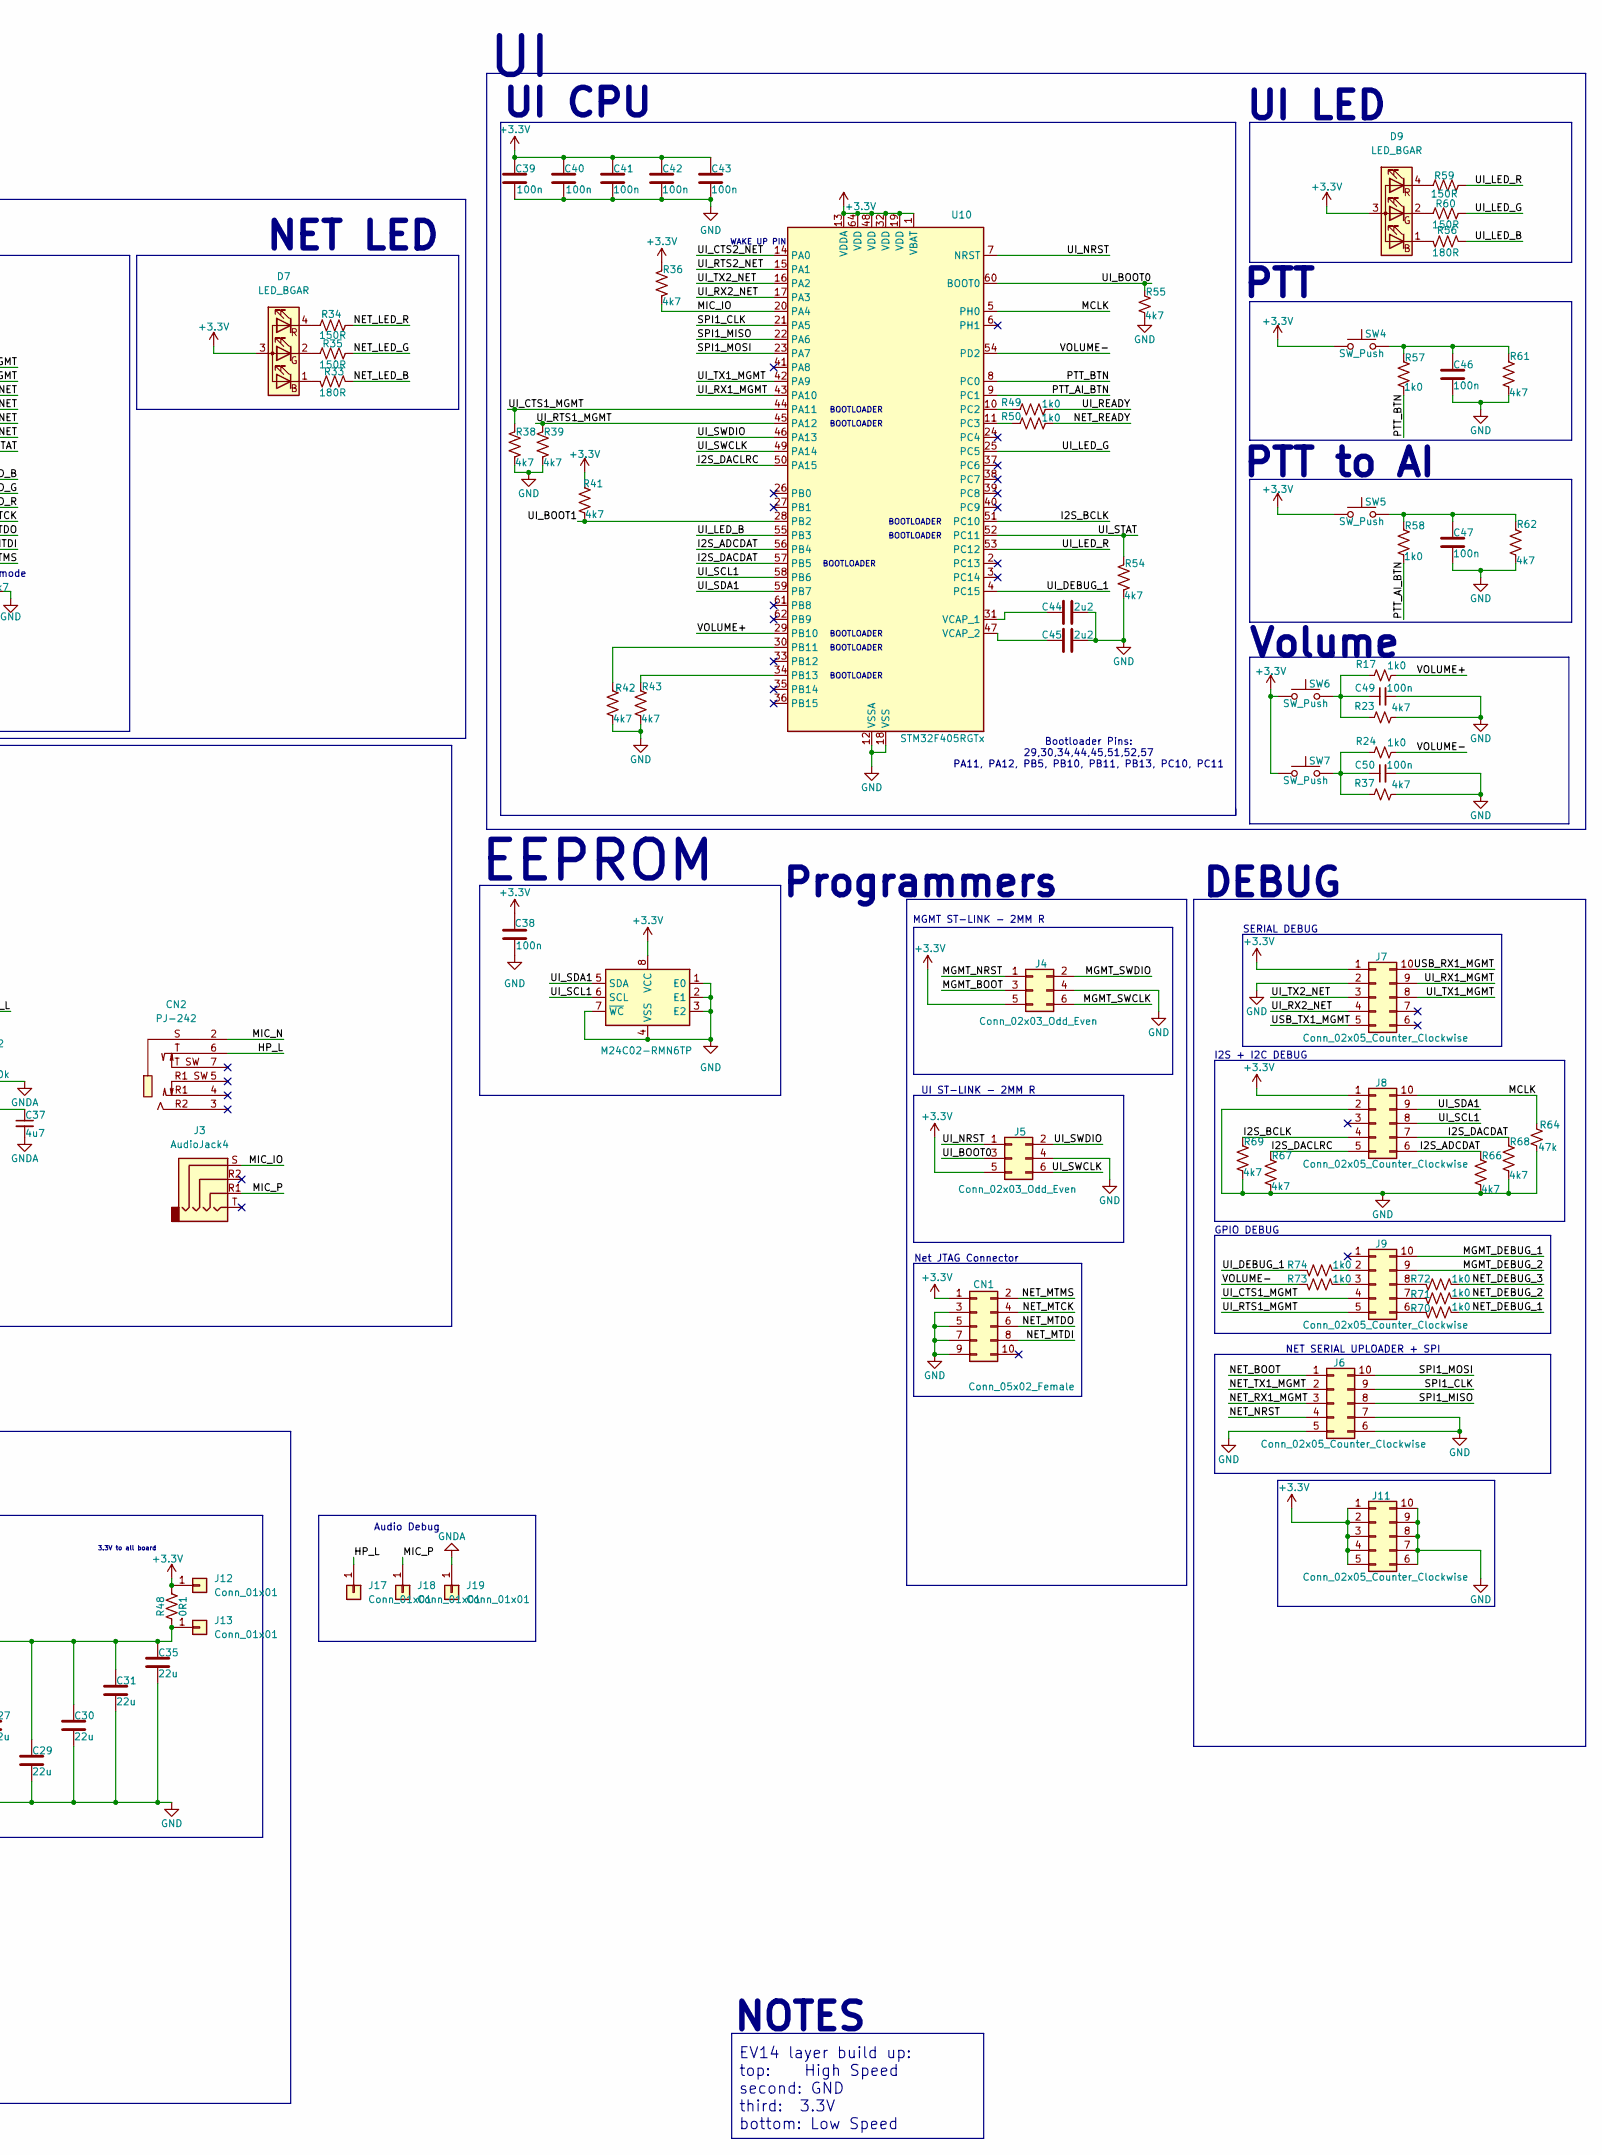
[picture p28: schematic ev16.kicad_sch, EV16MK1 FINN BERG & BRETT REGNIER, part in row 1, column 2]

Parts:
C1, C6, C8, C9, C13, C17, C21, C23, C25, C38, C39, C40, C41, C42, C43, C46, C47, C49, C50: 100n; C_0402_1005Metric; JLCPCB Part # C1525
C2, C3: 33p; C_0805_2012Metric; JLCPCB Part # C107115
C4, C5, C12: 10u; C_0402_1005Metric; JLCPCB Part # C307415
C7, C18, C32, C36: 1u; C_0402_1005Metric; JLCPCB Part # C52923
C10, C51: 100n; C_0402_1005Metric; JLCPCB Part # C85866
C14, C19, C22: 100n; C_0805_2012Metric; JLCPCB Part # C85866
C15, C16: 10u; C_0805_2012Metric; JLCPCB Part # C17024
C20: 2p2; C_0805_2012Metric; JLCPCB Part # C519933
C24, C27, C29, C30, C31, C35: 22u; C_0805_2012Metric; JLCPCB Part # C5674
C26, C28, C33, C37: 4u7; C_0402_1005Metric; JLCPCB Part # C23733
C34, C48: 100u; C_1206_3216Metric; JLCPCB Part # C15008
C44, C45: 2u2; C_0402_1005Metric; JLCPCB Part # C12530
CN1: Conn_05x02_Female; IDC-SMD_10P-P1.27_X1270WVS-2X05B-6TV01; JLCPCB Part # C2962222
CN2: PJ-242; AUDIO-SMD_PJ-242D-SMT
D1: LED; D_0805_2012Metric; JLCPCB Part # C130114
D5: LED_BGAR; LED-ARRAY-SMD_4P-L1.6-W1.5-TL_NH-B1515RGBA; JLCPCB Part # C2874115
D7, D9: LED_BGAR; LED-ARRAY-SMD_HS-1204-RGB; JLCPCB Part # C965884
H2, H3, H4: MountingHole; MountingHole_2.7mm_M2.5
J1: USB_C_Receptacle; USB-C_SMD-TYPE-C-31-M-12; JLCPCB Part # C165948
J2: Conn_01x02_Socket; JST_PH_S2B-PH-SM4-TB_1x02-1MP_P2.00mm_Horizontal; JLCPCB Part # C295747
J3: AudioJack4; AUDIO-SMD_PJ-320D
J4, J5: Conn_02x03_Odd_Even; HDR-SMD_6P-P2.54-V-M-R2-C3-LS7.5-2; JLCPCB Part # C3294461
J6, J7, J8, J9, J11: Conn_02x05_Counter_Clockwise; HDR-SMD_10P-P2.54-V-F-R2-C5-LS7.1-1; JLCPCB Part # C3975150
J10: Conn_01x03_Pin; PinHeader_1x03_P2.54mm_Vertical; JLCPCB Part # C146690
J12, J13, J14, J15, J16, J17, J18, J19, J20, J21: Conn_01x01; PinHeader_1x01_P2.54mm_Vertical
JP2: SolderJumper_2_Bridged; NetTie-2_SMD_Pad0.5mm
L2: 1.5uH; L_Coilcraft_XxL4020; JLCPCB Part # C3033018
NT1: NetTie_4; NetTie-4_SMD_Pad0.5mm
NT2, NT3: NetTie_2; NetTie-2_SMD_Pad0.5mm
Q1, Q2, Q3: 2N7002; SOT-23; JLCPCB Part # C8545
R1: 680R; R_0402_1005Metric; JLCPCB Part # C25130
R2, R22, R23, R30, R36, R37, R38, R39, R41, R42, R43, R51, R54, R55, R61, R62, R66, R67, R68, R69: 4k7; R_0402_1005Metric; JLCPCB Part # C25900
R3, R25, R64: 47k; R_0402_1005Metric; JLCPCB Part # C25792
R4, R5, R9, R10, R17, R24, R40, R44, R45, R46, R49, R50, R57, R58, R70, R71, R72, R73, R74: 1k0; R_0402_1005Metric; JLCPCB Part # C11702
R6, R12, R47: 10k; R_0402_1005Metric; JLCPCB Part # C25744
R7, R8: 5k1; R_0402_1005Metric; JLCPCB Part # C25905
R11, R16, R19: 1k5; R_0402_1005Metric; JLCPCB Part # C25867
R13, R29, R53: 15k; R_0402_1005Metric; JLCPCB Part # C25756
R14, R48, R52: 0R1; R_0603_1608Metric; JLCPCB Part # C111027
R15, R33, R56: 180R; R_0402_1005Metric; JLCPCB Part # C25087
R18, R28, R32, R65, R75: 100k; R_0402_1005Metric; JLCPCB Part # C25741
R20, R21, R34, R35, R59, R60: 150R; R_0402_1005Metric; JLCPCB Part # C25082
R26: 360k; R_0402_1005Metric; JLCPCB Part # C45956
R27: 64k9; R_0402_1005Metric; JLCPCB Part # C26984
R31: 2k2; R_0402_1005Metric; JLCPCB Part # C25879
SW1: SW_SPDT; SW-TH_SS-12D11G5R; JLCPCB Part # C388633
SW2, SW3: SW_Push; KEY-SMD_4P-L4.2-W3.2-P2.20-LS4.6; JLCPCB Part # C139797
SW4, SW5: SW_Push; SW-SMD_4P-L5.1-W5.1-P3.70-LS6.5-TL_H1.5; JLCPCB Part # C318884
SW6, SW7: SW_Push; SW-SMD_SHOU_TS36CA-0.6; JLCPCB Part # C2906288
U1: BQ21040DBV; SOT-23-6; JLCPCB Part # C202311
U2: USBLC6-2P6; SOT-666; JLCPCB Part # C2827693
U3: STM32F072CBTx; LQFP-48_7x7mm_P0.5mm; JLCPCB Part # C80488
U4: CH340C; SOIC-16_3.9x9.9mm_P1.27mm; JLCPCB Part # C84681
U5: TPS63060; Texas_S-PWSON-N10_ThermalVias; JLCPCB Part # C48567
U6: WM8960CGEFL/RV; QFN-32-1EP_5x5mm_P0.5mm_EP3.45x3.45mm_ThermalVias; JLCPCB Part # C18752
U7: ESP32-S3-WROOM-1; JLCPCB Part # C2913204
U8: M24C02-RMN6TP; SOIC-8_3.9x4.9mm_P1.27mm; JLCPCB Part # C83836
U9: TPS2116DRL; SOT-583-8; JLCPCB Part # C3235557
U10: STM32F405RGTx; LQFP-64_10x10mm_P0.5mm; JLCPCB Part # C15742
U12: XC6227C301MR-G; SOT-23-5; JLCPCB Part # C484285
Y1: Crystal_GND24; Crystal_SMD_3225-4Pin_3.2x2.5mm; JLCPCB Part # C13738

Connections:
+3.0VA: C25.2, C26.1, C28.1, J21.1, R52.2, U6.21 (SPKVDD2), U6.26 (SPKVDD1), U6.32 (AVDD)
+3.3V: C1.2, C6.2, C8.2, C9.2, C13.1, C21.2, C23.2, C38.2, C39.1, C40.1, C41.1, C42.1, C43.1, CN1.1, D5.2 (A), D7.3 (A), D9.3 (A), J4.5, J5.5, J7.1, J8.1, J10.1, J11.1, J11.2, J11.3, J11.4, J11.5, J12.1, NT2.2, R3.2, R16.1, R19.1, R22.2, R25.2, R36.2, R41.1, R48.2, R75.2, SW4.1, SW4.2, SW5.1, SW5.2, SW6.1, SW7.1, U3.1 (VBAT), U3.9 (VDDA), U3.24 (VDD), U3.36 (VDDIO2), U3.48 (VDD), U4.16 (VCC), U6.8 (DCVDD), U6.10 (DBVDD), U7.2 (3V3), U8.8 (VCC), U10.1 (VBAT), U10.13 (VDDA), U10.19 (VDD), U10.32 (VDD), U10.48 (VDD), U10.64 (VDD)
/AVIN: C7.1, C51.1, J10.2, U12.1 (VIN), U12.3 (CE)
/BATTERY_MON: R12.1, R13.1, U3.18 (PB0)
/CHG_FB: Q2.3 (D), R3.1, U3.19 (PB1)
/D_N: J1.A7 (D-), J1.B7 (D-), U2.6 (I/O1)
/D_P: J1.A6 (D+), J1.B6 (D+), U2.4 (I/O2)
/HP_L: C34.2, CN2.6, J17.1, R32.2
/HP_R: C48.2, R65.2
/I2S_ADCDAT: J8.6, R66.1, U6.16 (ADCDAT), U10.56 (PB4)
/I2S_BCLK: J8.4, R69.1, U6.12 (BCLK), U10.51 (PC10)
/I2S_DACDAT: J8.7, R68.1, U6.14 (DACDAT), U10.57 (PB5)
/I2S_DACLRC: J8.5, R67.1, U6.13 (DACLRC), U10.50 (PA15)
/LEDA_B: R15.2, U3.17 (PA7)
/LEDA_G: R21.2, U3.16 (PA6)
/LEDA_R: Q1.1 (G), R25.1, U3.14 (PA4)
/MCLK: J8.10, R64.1, U3.29 (PA8), U6.11 (MCLK), U10.5 (PH0)
/MGMT_BOOT: J4.3, Q3.3 (D), R22.1, U3.44 (BOOT0)
/MGMT_DEBUG_1: J9.10, U3.15 (PA5)
/MGMT_DEBUG_2: J9.9, U3.25 (PB12)
/MGMT_NRST: C17.1, J4.1, NT3.2, SW3.1, SW3.2, U3.7 (NRST)
/MGMT_SWCLK: J4.6, U3.37 (PA14)
/MGMT_SWDIO: J4.2, U3.34 (PA13)
/MIC_IO: J3.S, R36.1, U10.20 (PA4)
/MIC_N: C32.2, CN2.2, JP2.1 (A)
/MIC_P: C36.2, J3.R1, J18.1, R31.1
/NET_BOOT: J6.1, U3.41 (PB5), U7.27 (IO0)
/NET_CTS1_MGMT: U3.26 (PB13), U7.9 (IO16)
/NET_DEBUG_1: R70.1, U7.5 (IO5)
/NET_DEBUG_2: R71.1, U7.6 (IO6)
/NET_DEBUG_3: R72.1, U7.7 (IO7)
/NET_LED_B: R33.1, U7.29 (IO36)
/NET_LED_G: R35.1, U7.30 (IO37)
/NET_LED_R: R34.1, U7.31 (IO38)
/NET_MTCK: CN1.4, U7.32 (IO39)
/NET_MTDI: CN1.8, U7.34 (IO41)
/NET_MTDO: CN1.6, U7.33 (IO40)
/NET_MTMS: CN1.2, U7.35 (IO42)
/NET_NRST: J6.4, R29.1, U3.40 (PB4), U7.3 (EN)
/NET_READY: R50.1, U7.12 (IO8)
/NET_RTS1_MGMT: U3.27 (PB14), U7.8 (IO15)
/NET_RX1_MGMT: J6.3, U3.21 (PB10), U7.36 (RXD0)
/NET_STAT: R4.2, U7.23 (IO21)
/NET_TX1_MGMT: J6.2, U3.22 (PB11), U7.37 (TXD0)
/PTT_AI_BTN: R58.1, U10.9 (PC1)
/PTT_BTN: R57.1, U10.8 (PC0)
/RCC_OSC_IN: C2.2, U3.5 (PF0), Y1.1
/RCC_OSC_OUT: C3.2, U3.6 (PF1), Y1.3
/SPI1_CLK: J6.9, R44.1, U10.21 (PA5)
/SPI1_MISO: J6.8, R45.1, U10.22 (PA6)
/SPI1_MOSI: J6.10, R46.1, U10.23 (PA7)
/UD_N: U2.1 (I/O1), U4.6 (UD-)
/UD_P: U2.3 (I/O2), U4.5 (UD+)
/UI_BOOT0: J5.3, R55.1, U3.38 (PA15), U10.60 (BOOT0)
/UI_BOOT1: R41.2, U3.45 (PB8), U10.28 (PB2)
/UI_CTS1_MGMT: J9.4, R38.2, U3.11 (PA1), U10.44 (PA11)
/UI_CTS2_NET: U7.14 (USB_D+), U10.14 (PA0)
/UI_DEBUG_1: R74.2, U10.4 (PC15)
/UI_LED_B: R56.1, U10.55 (PB3)
/UI_LED_G: R60.1, U10.25 (PC5)
/UI_LED_R: R59.1, U10.53 (PC12)
/UI_NRST: J5.1, U3.39 (PB3), U10.7 (NRST)
/UI_READY: R49.1, U7.17 (IO9)
/UI_RTS1_MGMT: J9.5, R39.2, U3.10 (PA0), U10.45 (PA12)
/UI_RTS2_NET: U7.13 (USB_D-), U10.15 (PA1)
/UI_RX1_MGMT: J7.9, U3.12 (PA2), U10.43 (PA10)
/UI_RX2_NET: J7.4, U7.10 (IO17), U10.17 (PA3)
/UI_SCL1: J8.8, R16.2, U6.17 (SCLK), U8.6 (SCL), U10.58 (PB6)
/UI_SDA1: J8.9, R19.2, U6.18 (SDIN), U8.5 (SDA), U10.59 (PB7)
/UI_STAT: R5.2, R54.2, U10.52 (PC11)
/UI_SWCLK: J5.6, U10.49 (PA14)
/UI_SWDIO: J5.2, U10.46 (PA13)
/UI_TX1_MGMT: J7.8, U3.13 (PA3), U10.42 (PA9)
/UI_TX2_NET: J7.3, U7.11 (IO18), U10.16 (PA2)
/USB_CC1_DETECT: R9.1, U3.4 (PC15)
/USB_CC2_DETECT: R10.1, U3.3 (PC14)
/USB_DTR: R40.2, U4.13 (~DTR)
/USB_RTS: R51.1, U4.14 (~RTS)
/USB_RX1_MGMT: J7.10, U3.30 (PA9), U4.3 (RXD)
/USB_TX1_MGMT: J7.5, U3.31 (PA10), U4.2 (TXD)
/VOLUME+: R17.1, U10.29 (PB10)
/VOLUME-: R24.1, R73.2, U10.54 (PD2)
GND: C1.1, C2.1, C3.1, C4.2, C5.2, C6.1, C7.2, C8.1, C9.1, C12.2, C13.2, C14.2, C15.2, C16.2, C17.2, C19.2, C20.2, C21.1, C22.2, C23.1, C24.2, C27.2, C29.2, C30.2, C31.2, C35.2, C38.1, C39.2, C40.2, C41.2, C42.2, C43.2, C44.1, C45.1, C46.2, C47.2, C49.2, C50.2, C51.2, CN1.3, CN1.5, CN1.7, CN1.9, J1.A1 (GND), J1.A12 (GND), J1.B1 (GND), J1.B12 (GND), J2.1, J4.4, J5.4, J6.5, J6.6, J6.7, J7.2, J8.2, J11.6, J11.7, J11.8, J11.9, J11.10, J16.1, NT1.1, NT1.3, Q1.2 (S), Q2.2 (S), Q3.2 (S), R1.2, R2.1, R6.2, R7.1, R8.1, R13.2, R23.1, R27.1, R29.2, R30.2, R37.1, R38.1, R39.1, R42.1, R43.1, R47.1, R54.1, R55.2, R61.1, R62.1, R64.2, R66.2, R67.2, R68.2, R69.2, SW2.1, SW2.2, SW3.3, SW3.4, U1.5 (GND), U2.2 (GND), U3.8 (VSSA), U3.23 (VSS), U3.35 (VSS), U3.47 (VSS), U4.1 (GND), U5.4 (PS/SYNC), U5.7 (GND), U5.11 (PGND), U6.9 (DGND), U7.1 (GND), U7.40 (GND), U7.41 (GND), U8.1 (E0), U8.2 (E1), U8.3 (E2), U8.4 (VSS), U8.7 (~WC), U9.1 (GND), U10.12 (VSSA), U10.18 (VSS), U10.63 (VSS), Y1.2, Y1.4
GNDA: C10.2, C18.2, C25.1, C26.2, C28.2, C33.2, C37.2, J19.1, JP2.2 (B), NT1.2, NT1.4, R32.1, R65.1, U6.2 (LINPUT3), U6.5 (RINPUT1), U6.6 (RINPUT2), U6.7 (RINPUT3), U6.20 (SPKGND2), U6.24 (SPKGND1), U6.28 (AGND), U6.33 (EP), U12.2 (VSS)
unnamed: C46.1, R57.2, R61.2, SW4.3, SW4.4
unnamed: C47.1, R58.2, R62.2, SW5.3, SW5.4
unnamed: C49.1, R17.2, R23.2, SW6.2
unnamed: C50.1, R24.2, R37.2, SW7.2
unnamed: D1.2 (A), R11.2
unnamed: D1.1 (K), Q2.1 (G), U1.3 (~CHG)
unnamed: D5.3 (BK), R15.1
unnamed: D5.4 (GK), R21.1
unnamed: D5.1 (RK), R20.1
unnamed: D7.1 (BK), R33.2
unnamed: D7.2 (GK), R35.2
unnamed: D7.4 (RK), R34.2
unnamed: D9.1 (BK), R56.2
unnamed: D9.2 (GK), R60.2
unnamed: D9.4 (RK), R59.2
unnamed: J1.A5 (CC1), R8.2, R10.2
unnamed: J1.B5 (CC2), R7.2, R9.2
unnamed: C12.1, J2.2, R11.1, U1.2 (OUT), U9.6 (VIN2)
unnamed: J9.2, R74.1
unnamed: J9.3, R73.1
unnamed: J9.6, R70.2
unnamed: J9.7, R71.2
unnamed: J9.8, R72.2
unnamed: C22.1, C24.1, C27.1, C29.1, C30.1, C31.1, C35.1, J13.1, R26.2, R28.2, R48.1, U5.9 (VOUT)
unnamed: C14.1, C15.1, C16.1, J14.1, R14.2, R18.1, U5.2 (VIN)
unnamed: C10.1, C18.1, J20.1, R52.1, U12.5 (VOUT)
unnamed: NT3.1, R40.1
unnamed: Q1.3 (D), R20.2
unnamed: Q3.1 (G), R51.2, R75.1, SW2.3, SW2.4
unnamed: SW1.3 (C), U9.2 (VOUT), U9.7 (VOUT)
unnamed: R1.1, U1.4 (ISET)
unnamed: R6.1, U1.1 (TS)
unnamed: R4.1, U3.43 (PB7)
unnamed: R5.1, U3.46 (PB9)
unnamed: R2.2, U3.2 (PC13)
unnamed: NT2.1, U4.4 (V3)
unnamed: R18.2, U5.3 (EN)
unnamed: C20.1, R26.1, R27.2, U5.8 (FB)
unnamed: L2.1, U5.1 (L1)
unnamed: L2.2, U5.10 (L2)
unnamed: R28.1, U5.5 (PG)
unnamed: C19.1, U5.6 (VAUX)
unnamed: C33.1, U6.27 (AMID)
unnamed: C34.1, U6.31 (HP_L)
unnamed: C48.1, U6.29 (HP_R)
unnamed: C32.1, U6.4 (LINPUT1)
unnamed: C36.1, U6.3 (LINPUT2)
unnamed: C37.1, R31.2, U6.1 (MICBIAS)
unnamed: R46.2, U7.19 (IO11)
unnamed: R44.2, U7.20 (IO12)
unnamed: R45.2, U7.21 (IO13)
unnamed: R30.1, U7.16 (IO46)
unnamed: R47.2, R53.1, U9.4 (PR1)
unnamed: R42.2, U10.30 (PB11)
unnamed: R43.2, U10.34 (PB13)
unnamed: R49.2, U10.10 (PC2)
unnamed: R50.2, U10.11 (PC3)
unnamed: C44.2, U10.31 (VCAP_1)
unnamed: C45.2, U10.47 (VCAP_2)
VBUS: C4.1, C5.1, J1.A4 (VBUS), J1.A9 (VBUS), J1.B4 (VBUS), J1.B9 (VBUS), R53.2, U1.6 (VIN), U2.5 (VBUS), U9.3 (VIN1), U9.5 (MODE)
VSYS: J10.3, J15.1, R12.2, R14.1, SW1.2 (B)

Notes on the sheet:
MGMT
BOOTLOADER
Audio Debug
NET CPU
MGMT CPU
WAKE UP PIN
PTT to AI
NET
POWER
Programmers
MOUNTING
BATTERY
NET LED
UI CPU
Bootloader Pins: 29,30,34,44,45,51,52,57 PA11, PA12, PB5, PB10, PB11, PB13, PC10, PC11
UI ST-LINK - 2MM R
Chip boot mode
Net JTAG Connector
NRST
The following pins must be stable at boot: -PA9/PA10: Bootload -PA14/PA15: Input/output usart2 -PB6/PB7: Input/output for I2C PA11/PA12: Input/output for USB
DIGITAL
Volume
EV14 layer build up: top: High Speed second: GND third: 3.3V bottom: Low Speed
NET SERIAL UPLOADER + SPI
AUDIO
PTT
BOOT
PA11 and PA12 reserved for USB
EEPROM
I2C BUS
USB
MGMT LED
3.3V to all board
DEBUG
NOTES
MGMT ST-LINK - 2MM R
GPIO DEBUG
SERIAL DEBUG
1 Capacitor Per Voltage Pin Not including VBAT
UI LED

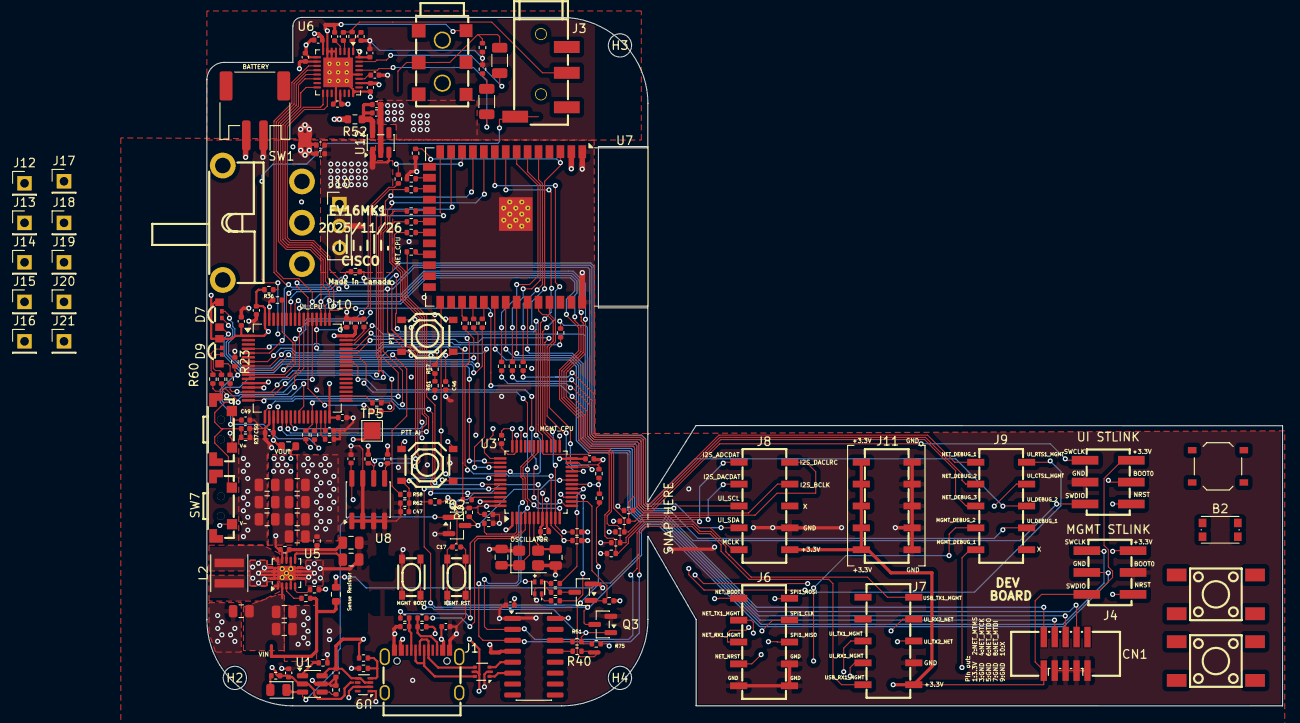
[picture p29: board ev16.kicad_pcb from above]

Board: 4 copper layers, 125.0 x 80.0 mm, 186 parts (0 on the bottom side), 145 nets.

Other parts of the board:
B1: SW_Push_1P1T_XKB_TS-1187A
B2: SW_Push_1P1T_NO_CK_KMR2
B3, B4: SW-SMD_4P-L6.0-W6.0-P4.50-LS9.0_H5.0; SW-SMD_4P-L6.0-W6.0-P4.5
TP5: TestPoint; TestPoint_Pad_2.0x2.0mm

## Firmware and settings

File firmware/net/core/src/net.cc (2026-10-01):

#include "net.hh"
#include "config_state.hh"
#include "driver/gpio.h"
#include "driver/uart.h"
#include "esp_heap_caps.h"
#include "esp_mac.h"
#include "esp_pthread.h"
#include "freertos/FreeRTOS.h"
#include "freertos/projdefs.h"
#include "freertos/queue.h"
#include "freertos/task.h"
#include "link_packet_t.hh"
#include "logger.hh"
#include "mgmt_link_handler.hh"
#include "moq_context.hh"
#include "net_mgmt_link.h"
#include "peripherals.hh"
#include "portmacro.h"
#include "serial.hh"
#include "spdlog/common.h"
#include "storage.hh"
#include "stored_value.hh"
#include "ui_link_handler.hh"
#include "ui_net_link.hh"
#include "wifi.hh"
#include <nlohmann/json.hpp>
#include <quicr/client.h>
#include <stdio.h>
#include <stdlib.h>
#include <string.h>

static Runtime runtime_ctx{
    .device_id = 0,
    .audio_req_smpr = xSemaphoreCreateBinary(),
    .curr_audio_isr_time = 0,
    .last_audio_isr_time = 0,
};

// TODO remove me some day
#ifdef __has_include
#if __has_include("wifi_creds.hh")
#include "wifi_creds.hh"
#else
#warning "wifi_creds.hh not found!!"
#endif
#else
#include "wifi_creds.hh"
#endif

static void IRAM_ATTR GpioIsrRisingHandler(void* arg)
{
    int gpio_num = (int)arg;

    if (gpio_num == UI_READY)
    {
        runtime_ctx.last_audio_isr_time = runtime_ctx.curr_audio_isr_time;
        runtime_ctx.curr_audio_isr_time = esp_timer_get_time();
        xSemaphoreGiveFromISR(runtime_ctx.audio_req_smpr, NULL);
    }
}

void PrintRAM()
{
    NET_LOG_ERROR("Internal SRAM available: %d bytes",
                  heap_caps_get_free_size(MALLOC_CAP_INTERNAL));
    NET_LOG_ERROR("PSRAM available: %d bytes", heap_caps_get_free_size(MALLOC_CAP_SPIRAM));
}

void SetPThreadDefault()
{
    esp_pthread_cfg_t cfg = esp_pthread_get_default_config();
    cfg.stack_size = 32000;
    cfg.stack_alloc_caps = MALLOC_CAP_SPIRAM | MALLOC_CAP_8BIT;
    esp_pthread_set_cfg(&cfg);
}

extern "C" void app_main(void)
{
    SetPThreadDefault();
    PrintRAM();
    InitializeGPIO();
    IntitializeLEDs();
    InitializeUIReadyISR(GpioIsrRisingHandler);

    Diagnostics diagnostics = {
        .loopback = NetLoopbackMode::Off,
        .logs_disabled = false,
        .last_spd_log_level = static_cast<spdlog::level::level_enum>(SPDLOG_ACTIVE_LEVEL),
        .blaster = {false, nullptr, 1},
    };
    Storage storage;
    ConfigState config(storage);

    Serial ui_layer(NetTraits::UiUart::port, NetTraits::UiUart::Uart(), ETS_UART1_INTR_SOURCE,
                    NetTraits::UiUart::config, NetTraits::UiUart::tx_pin, NetTraits::UiUart::rx_pin,
                    UART_PIN_NO_CHANGE, UART_PIN_NO_CHANGE, NetTraits::UiUart::TxBuff(),
                    NetTraits::UiUart::tx_buffer_size, NetTraits::UiUart::RxBuff(),
                    NetTraits::UiUart::rx_buffer_size, NetTraits::UiUart::ring_rx_count, 8192, 8192,
                    20, true, false);

    Serial mgmt_layer(NetTraits::MgmtUart::port, NetTraits::MgmtUart::Uart(), ETS_UART0_INTR_SOURCE,
                      NetTraits::MgmtUart::config, NetTraits::MgmtUart::tx_pin,
                      NetTraits::MgmtUart::rx_pin, UART_PIN_NO_CHANGE, UART_PIN_NO_CHANGE,
                      NetTraits::MgmtUart::TxBuff(), NetTraits::MgmtUart::tx_buffer_size,
                      NetTraits::MgmtUart::RxBuff(), NetTraits::MgmtUart::rx_buffer_size,
                      NetTraits::MgmtUart::ring_rx_count, 0, 256, 2, true, false);

    Wifi wifi(storage);
    MoqContext moq_context(ui_layer, runtime_ctx, diagnostics);
    UiLinkHandler ui_link_handler(ui_layer, mgmt_layer, moq_context, runtime_ctx, diagnostics);
    MgmtLinkHandler mgmt_link_handler(mgmt_layer, ui_layer, wifi, storage, config, diagnostics,
                                      moq_context, runtime_ctx);

    NET_LOG_INFO("Starting Net Main");

    mgmt_link_handler.Begin();
    ui_link_handler.Begin();

    wifi.Begin();

#if defined(my_ssid) && defined(my_ssid_pwd)
    wifi.Connect(my_ssid, my_ssid_pwd);
#endif

    if (config.moq_server_url->empty())
    {
        // No moq url found, using default
        NET_LOG_WARN(
            "No moq server url found, using default moq://relay.us-west-2.quicr.ctgpoc.com:33435");
        config.moq_server_url = "moq://relay.us-west-2.quicr.ctgpoc.com:33435";
    }

    NET_LOG_WARN("Using moq server url of %s len %u", config.moq_server_url->c_str(),
                 config.moq_server_url->length());

    // Set default language if not configured
    if (config.language->empty())
    {
        config.language = "en-US";
    }

    // Load namespaces from storage
    config.LoadNamespacesFromStorage();

    // Log warnings if namespaces are not configured (no defaults - must be configured via
    // fl-identity)
    // TODO maybe we should loop forever at this point?
    if (config.channel_ns.empty())
    {
        NET_LOG_WARN("Channel namespace not configured - device needs configuration");
    }
    if (config.ai_query_ns.empty() || config.ai_audio_response_ns.empty()
        || config.ai_cmd_response_ns.empty())
    {
        NET_LOG_WARN("AI namespaces not configured - device needs configuration");
    }

    config.user_id.Load();
    if (config.user_id.stored == 0)
    {
        NET_LOG_ERROR("User id is zero");
    }

    config.user_name.Load();
    if (config.user_name->empty())
    {
        config.user_name = "unknown";
    }

    NET_LOG_INFO("User id %d user name %s", (int)config.user_id.stored, config.user_name->c_str());

    // Use mac addr as id for my session
    uint64_t mac = 0;
    esp_efuse_mac_get_default((uint8_t*)&mac);
    mac = mac << 2;
    mac = mac >> 2;
    runtime_ctx.device_id = mac;

    NET_LOG_ERROR("mac addr %llu", mac);

    // setup moq transport
    quicr::ClientConfig moq_config;
    moq_config.endpoint_id = std::to_string(runtime_ctx.device_id);
    moq_config.connect_uri = config.moq_server_url.Load();
    moq_config.transport_config.debug = true;
    moq_config.transport_config.use_reset_wait_strategy = false;
    moq_config.transport_config.time_queue_max_duration = 5000;
    moq_config.transport_config.tls_cert_filename = "";
    moq_config.transport_config.tls_key_filename = "";
    moq_config.tick_service_sleep_delay_us = 30000;

    moq_context.InitializeSession(moq_config);

    PrintRAM();

    NET_LOG_INFO("Components ready");

    // Set up initial tracks based on stored configuration
    moq_context.UpdateAITracks(config);
    moq_context.UpdateChannelTracks(config);

    moq::Session::Status prev_status = moq::Session::Status::kNotConnected;
    Wifi::State prev_wifi_state = Wifi::State::Connected;
    while (true)
    {
        moq::Session::Status status = moq_context.GetStatus();

        Wifi::State wifi_state = wifi.GetState();

        if (prev_wifi_state != wifi_state)
        {
            prev_wifi_state = wifi_state;

            switch (wifi_state)
            {
            case Wifi::State::Disconnected:
            {
                // Back to yellow
                gpio_set_level(NET_LED_R, 0);
                gpio_set_level(NET_LED_G, 0);
                gpio_set_level(NET_LED_B, 1);

                if (status == moq::Session::Status::kConnecting
                    || status == moq::Session::Status::kPendingServerSetup
                    || status == moq::Session::Status::kReady)
                {
                    moq_context.RestartSession(moq_config);
                }
                break;
            }
            case Wifi::State::Initialized:
            {
                break;
            }
            case Wifi::State::Connected:
            {
                gpio_set_level(NET_LED_R, 1);
                gpio_set_level(NET_LED_G, 0);
                break;
            }
            default:
            {
                // Do nothing.
                break;
            }
            }
        }

        if (prev_status != status && wifi.IsConnected())
        {
            NET_LOG_INFO("New moq state %d", (int)status);
            switch (status)
            {
            case moq::Session::Status::kReady:
            {
                // Create tracks from stored config (may have been set before session was ready)
                moq_context.UpdateChannelTracks(config);
                moq_context.UpdateAITracks(config);
                moq_context.StartTracks();

                break;
            }
            case moq::Session::Status::kNotConnected:
                [[fallthrough]];
            case moq::Session::Status::kFailedToConnect:
            {
                moq_context.RestartSession(moq_config);
                break;
            }
            case moq::Session::Status::kNotReady:
            {
                NET_LOG_INFO("MOQ Transport Calling Connect");

                if (!moq_context.Connect())
                {
                    NET_LOG_ERROR("MOQ Transport Session Connection Failure");
                }

                break;
            }
            default:
            {
                // TODO the rest
                NET_LOG_INFO("No handler for this moq state");
                break;
            }
            }
            prev_status = status;
        }

        if (moq_config.connect_uri != config.moq_server_url)
        {
            NET_LOG_INFO("Load moq server uri");
            moq_config.connect_uri = config.moq_server_url;
            NET_LOG_INFO("Make a new session with uri %s", moq_config.connect_uri.c_str());
            moq_context.RestartSession(moq_config);
        }
        vTaskDelay(1000 / portTICK_PERIOD_MS);
    }
}

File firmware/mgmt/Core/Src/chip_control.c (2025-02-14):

#include "chip_control.h"

#include "io_control.h"
#include "app_mgmt.h"
#include "main.h"

void NetBootloaderMode()
{
    ChangeToOutput(NET_BOOT_GPIO_Port, NET_BOOT_Pin);
    ChangeToOutput(NET_NRST_GPIO_Port, NET_NRST_Pin);

    // Bring the boot low for esp, bootloader mode (0)
    HAL_GPIO_WritePin(NET_BOOT_GPIO_Port, NET_BOOT_Pin, GPIO_PIN_RESET);

    // Power cycle
    PowerCycle(NET_NRST_GPIO_Port, NET_NRST_Pin, 10);
}

void NetNormalMode()
{
    ChangeToOutput(NET_BOOT_GPIO_Port, NET_BOOT_Pin);
    ChangeToOutput(NET_NRST_GPIO_Port, NET_NRST_Pin);

    HAL_GPIO_WritePin(NET_BOOT_GPIO_Port, NET_BOOT_Pin, GPIO_PIN_SET);

    // Power cycle
    PowerCycle(NET_NRST_GPIO_Port, NET_NRST_Pin, 10);

    // ChangeToInput(NET_BOOT_GPIO_Port, NET_BOOT_Pin);
    // ChangeToInput(NET_NRST_GPIO_Port, NET_NRST_Pin);
}

void NetHoldInReset()
{
    ChangeToOutput(NET_NRST_GPIO_Port, NET_NRST_Pin);
    // Reset
    HAL_GPIO_WritePin(NET_NRST_GPIO_Port, NET_NRST_Pin, GPIO_PIN_RESET);
}

void UIBootloaderMode()
{
    ChangeToOutput(UI_BOOT0_GPIO_Port, UI_BOOT0_Pin);
    ChangeToOutput(UI_NRST_GPIO_Port, UI_NRST_Pin);

    // Normal boot mode (boot0 = 1 and boot1 = 0)
    HAL_GPIO_WritePin(UI_BOOT0_GPIO_Port, UI_BOOT0_Pin, GPIO_PIN_SET);
    HAL_GPIO_WritePin(UI_BOOT1_GPIO_Port, UI_BOOT1_Pin, GPIO_PIN_RESET);

    // Power cycle
    PowerCycle(UI_NRST_GPIO_Port, UI_NRST_Pin, 10);
}

void UINormalMode()
{
    ChangeToOutput(UI_BOOT0_GPIO_Port, UI_BOOT0_Pin);
    ChangeToOutput(UI_NRST_GPIO_Port, UI_NRST_Pin);

    // Normal boot mode (boot0 = 0 and boot1 = 1)
    HAL_GPIO_WritePin(UI_BOOT0_GPIO_Port, UI_BOOT0_Pin, GPIO_PIN_RESET);
    HAL_GPIO_WritePin(UI_BOOT1_GPIO_Port, UI_BOOT1_Pin, GPIO_PIN_SET);

    // Power cycle
    PowerCycle(UI_NRST_GPIO_Port, UI_NRST_Pin, 10);

    ChangeToInput(UI_BOOT0_GPIO_Port, UI_BOOT0_Pin);
    ChangeToInput(UI_NRST_GPIO_Port, UI_NRST_Pin);
}

void NormalStart()
{
    // HAL_GPIO_WritePin(UI_STAT_GPIO_Port, UI_STAT_Pin, LOW);
    NetNormalMode();
    HAL_Delay(200);
    UINormalMode();
}

void UIHoldInReset()
{
    ChangeToOutput(UI_NRST_GPIO_Port, UI_NRST_Pin);

    HAL_GPIO_WritePin(UI_NRST_GPIO_Port, UI_NRST_Pin, GPIO_PIN_RESET);
}



/**
 * @brief Waits for the network chip to send a ready signal
 *
 */
void WaitForNetReady(const enum State* state)
{
    // // Read from the Net chip
    // uint32_t timeout = HAL_GetTick() + 5000;
    // while (*state != Reset
    //     && HAL_GetTick() < timeout
    //     && HAL_GPIO_ReadPin(NET_STAT_GPIO_Port, NET_STAT_Pin) != GPIO_PIN_SET
    //     )
    // {
    //     // Stay here until the Net is done booting
    //     HAL_Delay(10);
    // }

    // HAL_GPIO_WritePin(UI_STAT_GPIO_Port, UI_STAT_Pin, HIGH);
}

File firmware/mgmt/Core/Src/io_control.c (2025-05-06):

#include "io_control.h"

extern UART_HandleTypeDef huart1;


void PowerCycle(GPIO_TypeDef* port, uint16_t pin, uint32_t delay)
{
    HAL_GPIO_WritePin(port, pin, GPIO_PIN_RESET);
    HAL_Delay(delay);
    HAL_GPIO_WritePin(port, pin, GPIO_PIN_SET);
}

void HoldInReset(GPIO_TypeDef* port, uint16_t pin)
{
    HAL_GPIO_WritePin(port, pin, GPIO_PIN_RESET);
}

void ChangeToInput(GPIO_TypeDef* port, uint16_t pin)
{
    HAL_GPIO_WritePin(port, pin, GPIO_PIN_RESET);

    HAL_GPIO_DeInit(port, pin);

    GPIO_InitTypeDef GPIO_InitStruct = {0};

    GPIO_InitStruct.Pin = pin;
    GPIO_InitStruct.Mode = GPIO_MODE_INPUT;
    GPIO_InitStruct.Pull = GPIO_NOPULL;
    GPIO_InitStruct.Speed = GPIO_SPEED_FREQ_LOW;
    HAL_GPIO_Init(port, &GPIO_InitStruct);
}

void ChangeToOutput(GPIO_TypeDef* port, uint16_t pin)
{
    HAL_GPIO_WritePin(port, pin, GPIO_PIN_RESET);

    HAL_GPIO_DeInit(port, pin);

    GPIO_InitTypeDef GPIO_InitStruct = {0};

    GPIO_InitStruct.Pin = pin;
    GPIO_InitStruct.Mode = GPIO_MODE_OUTPUT_PP;
    GPIO_InitStruct.Pull = GPIO_NOPULL;
    GPIO_InitStruct.Speed = GPIO_SPEED_FREQ_LOW;
    HAL_GPIO_Init(port, &GPIO_InitStruct);
}

/**
 * @brief TODO
 *
 */
void NormalAndNetUploadUartInit(uart_stream_t* usb_stream, UART_HandleTypeDef* tx_uart)
{
    // Init uart1 for UI upload
    HAL_UART_DeInit(&huart1);

    huart1.Instance = USART1;
    huart1.Init.BaudRate = BAUD;
    huart1.Init.WordLength = UART_WORDLENGTH_8B;
    huart1.Init.StopBits = UART_STOPBITS_1;
    huart1.Init.Parity = UART_PARITY_NONE;
    huart1.Init.Mode = UART_MODE_TX_RX;
    huart1.Init.HwFlowCtl = UART_HWCONTROL_NONE;
    huart1.Init.OverSampling = UART_OVERSAMPLING_16;
    huart1.Init.OneBitSampling = UART_ONE_BIT_SAMPLE_DISABLE;
    huart1.AdvancedInit.AdvFeatureInit = UART_ADVFEATURE_NO_INIT;
    if (HAL_UART_Init(&huart1) != HAL_OK)
    {
        Error_Handler();
    }

    usb_stream->tx.uart = tx_uart;
}

/**
 * @brief TODO
 *
 */
void UIUploadStreamInit(uart_stream_t* usb_stream, UART_HandleTypeDef* tx_uart)
{
    // Init uart1 for UI upload
    if (HAL_UART_DeInit(&huart1) != HAL_OK)
    {
        Error_Handler();
    }

    huart1.Instance = USART1;
    huart1.Init.BaudRate = BAUD;
    huart1.Init.WordLength = UART_WORDLENGTH_9B;
    huart1.Init.StopBits = UART_STOPBITS_1;
    huart1.Init.Parity = UART_PARITY_EVEN;
    huart1.Init.Mode = UART_MODE_TX_RX;
    huart1.Init.HwFlowCtl = UART_HWCONTROL_NONE;
    huart1.Init.OverSampling = UART_OVERSAMPLING_16;
    huart1.Init.OneBitSampling = UART_ONE_BIT_SAMPLE_DISABLE;
    huart1.AdvancedInit.AdvFeatureInit = UART_ADVFEATURE_NO_INIT;
    if (HAL_UART_Init(&huart1) != HAL_OK)
    {
        Error_Handler();
    }

    usb_stream->tx.uart = tx_uart;
}

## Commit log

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2023-05-25 Added a reset when the RTS pin is taken low after uploading, added a debug serial feature if the same upload button is pressed twice. ESP now properly gets its code
    [main.h]
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2023-05-26 Added usage of the external clock coming from the mgmt chip, fixed bug with the keyboard
    [main.h]
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2023-06-15 Updated pins for MGMT--Net and MGMT--UI, Net works, UI doesn't want ot upload
    [main.h]
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2023-07-13 ui -> net serial messages are coming in, there is a bug in the serial manager
    [net.cc]
2023-07-14 Fixed an error that caused the esp to not receive any data. UI <--> Net serial is 'functioning'
    [net.cc]
2023-07-17 Fixed issue where the serial communication was backing up the ui resulting in it erroring out.
    [net.cc]
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2023-08-10 Fixed memory leak that was plaguing the ui chip. Improve serial communication to be more reliable
    [ui.ioc]
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2023-09-22 Finally getting a response from esp32, but it is always an error, I think I need to do other stuff for it to start working first... see test.txt
    [esp32.py, stm32.py]
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2023-09-28 Flasher now searches for a hactar connected to a computer, python version for stm32 uploading has bugs somewhere
    [esp32.py, stm32.py]
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2023-10-27 Added self loopback for tx packets, and loopback from net chip to ui chip. QChat messages flow correctly across ui and net.
    [esp32.py, stm32.py]
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2024-01-12 Added support for auto-bootloader and reset dtr and rts signals to web page
    [stm32.py]
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2024-04-22 All pcb components are orientated correctly in jlcpcb pick n place tool
    [EV10.1.kicad_pcb, EV10.1.kicad_sch]
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2024-07-11 Added audio serial messages, updated serial to be faster, changed serial to no longer required ok messages
    [app_main.cc, audio_chip.cc, net.cc]
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2024-09-11 fix bug that was not setting the columns correctly, added diagonal lines
    [screen.cc]
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2024-09-19 Fixed race condition with the spi, waiting, and timer, added filled arrows, triangles, and polygons
    [app_main.cc, screen.cc, ui.ioc]
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2024-09-28 Fixed bug in screen code where the interrupts were causing conflictions with code that wasn't executing because of interruptions??
    [app_main.cc, chip_control.c, screen.cc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]
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2025-01-14 Cleanup net code a bit and rename moqt to moq. (#131)
    * Cleanup net code a bit and rename moqt to moq.
    * Fix review comments.
    [moq_track_reader.cc, net.cc]
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2025-01-30 feat(ui): Add better error function so we can identify who called the error
    [app_main.cc, screen.cc, serial.cc]
2025-02-04 feat: Updated net serial to go through all of the interrupts, added in a hacky forever loop into ring buffer insane of an read/write error
    [app_main.cc, net.cc, serial.cc]
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2025-02-10 chore: Fix bug in net serial, add internal loopback to ui, update net code to be using the common serial
    [app_main.cc, audio_chip.cc, net.cc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]
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2025-02-13 chore: Clean up some code, add notifying tasks, might have identified frame error issues
    [app_main.cc, net.cc, serial.cc]
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2025-03-12 feat: Fix several issues with model that required a bit of a rework
    [case-hactar-dev-casebot.step, case-hactar-dev-casetop.step, case.FCStd]
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2025-03-13 feat: add dev window, got correct screw sizing to bite into the plastic, adjusted width, adjusted antenna holder
    [case.FCStd]
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2025-03-26 feat: switch to espressif's built in uart handlers, even though its slower, but I don't have the time to fix the interrupt handling for our implementation
    [app_main.cc, net.cc, serial.cc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]
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2025-04-05 Fix: logic bug that once a track reader started transmitting audio it would never stop trying to take the semaphore
    [moq_track_reader.cc, net.cc]
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2025-05-07 Replaced side buttons, updated capacitor part #, removed extra 1k resistor, switched connectors to new part #
    [BOM-EV12 Board Design.csv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]
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2025-05-14 Added CMOX crypto (#208)
    * Added crypto.
    * Undo net changes.
    * Remove cmox specific files.
    * Improve makefile.
    * Fix extra semicolon.
    * Improve sframe ctx.
    * Improve protect/unprotect and mls ctx and key.
    * Better error message.
    * Address review comments.
    * Exclude sframe from formatting.
    * Exclude gsl
    * chore: remove include wifi_connect.hh
    * Changed serial communication to build chunks on UI.
    * FIx bad serialise.
    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
    [app_main.cc, moq_track_reader.cc, net.cc]
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2025-06-02 feat: Audio adapter board (#223)
    * feat: Audio adapter board
    * feat: Add audio test circuit and board
    * chore: cleaned up schematic
    * feat: Added in voltage divider and diode to detect ptt from midlands headset
    * chore: clean up sch box
    * feat: Moved the jacks slightly to be inline diagonally
    * feat: Changed resistor part number, and jumpers, and re-arranged things a bit
    * chore: fix misaligned 2.5mm jack
    * bugfix: updated the footprint to be what it actually is a TRRS and match what the datasheet says. As well, updated the sch to match that it is a TRRS
    * bugfix: cleanup the schematic and pcb
    [jack_adapter.kicad_pcb, jack_adapter.kicad_sch]
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2025-06-03 Make ui use cmake. (#240)
    * Make ui use cmake.
    * Update sframe with better temp version.
    * Update cmake.
    * The ultimate fix.
    * Adding cmox. (#243)
    * Adding cmox.
    * Addressing review comments and updating sframe.
    * Update format exclusions.
    [ui.ioc]
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2025-06-30 bugfix: fix issue with ui uploading (#285)
    * bugfix: fix issue with ui uploading by adding a slightly larger delay to the net chip reset
    * bugfix: fixed issue with the net chip never finishing due to timeout on transmissions while writing
    [app_mgmt.c, chip_control.c, uart_stream.c]
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2025-07-14 Fix up quicr connect flow and added methods to start stop readers/writers. (#294)
    [moq_track_reader.cc, net.cc]
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2025-07-25 Ev13 case (#301)
    * feat: finished bottom part of ev13 case
    * feat: finished ev13 case
    * feat: added buttons for ev13 rst and boot
    * feat: Add push buttons to boot and reset pcb buttons
    * feat: round corners for top case
    [bbq10keyboard.step, ev13_case-boot-rst-btn.step, ev13_case-hactar-dev-casebot.step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]
2025-07-28 Extend ev13 case buttons (#304)
    * chore: extend length of buttons by .5mm
    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
    [ev13_case-boot-rst-btn.step]
2025-08-26 EV14 final draft (#302)
    * Initial commit of EV14
    * Updated ev14 with audio added
    * Fet array for analog jack switching
    * Latest version of Ev14
    * Latest version of EV14
    * fix: move and rename ev14 board folder and fix paths
    * Jack breakout (#295)
    * feat: make jack breakout
    * chore: adjust schematic
    * chore: add jlcpcb part numbers
    * chore: add missing jlcpcb numbers and rotations
    * First finished draft of Ev14
    * Updated complete EV14 draft
    * Final Version of EV14
    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
    [earpiece_mega_schematic.kicad_pcb, earpiece_mega_schematic.kicad_sch, ev14.kicad_pcb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]
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2025-08-26 Update to frontline-latest libquicr (#313)
    * chore: Update to frontline-latest libquicr
    * Fix pub ok.
    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
    [partitions.csv]
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2025-08-29 bugfix: changing channels and ai responses work again (#324)
    * bugfix: changing channels and ai responses work again
    * chore: disable loopback
    * chore: address pr review
    [app_main.cc, moq_track_reader.cc, net.cc]
2025-09-16 Remake mgmt uart, monitor, and flasher tools (#303)
    * feat: adding eeprom back in and cleaning it up
    * feat: add configuration storage class
    * feat: add loading all configs at start of main
    * feat: added tlv packet handling for configuration mode in the mgmt chip
    * feat: add configuration mode for mgmt chip
    * feat: fixed error with device addressing
    * chore: remove file that shouldn't exist
    * feat: fleshing out config storage a little more, need to rewrite saving and loading configs, eeprom was doing too much
    * feat: reworked config to be simpler
    * feat: making a cleaner command handler
    * feat: loopback is officially working
    * feat: first fruits are taking shape
    * feat: more comm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
    [app_main.cc, app_mgmt.c, chip_control.c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]
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2025-10-07 chore: clean up restarting moq sessions, and fix bug with clearning a stored value
    [net.cc]
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2025-11-21 bugfix: update the no screen and no dev models to actually be what they are called
    [ev15-case-bottom-no-dev-hole.step, ev15-case-top-no-screen.step]
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2025-12-23 fixed issue with error on version and who are you because an ack byte was sent instead of actual characters
    [chip_control.c]
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2026-01-12 made the gap on the hinge larger so elephant footing wouldn't seal it, hopefully. Made side buttons slightly longer so they have more travel and increased their gap. Fixed issue with the screw pegs o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
    [ev16-case-bottom-demo.step, ev16-case-bottom-dev.step, ev16-case-side-buttons.step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]
2026-01-12 Fixed issue with the groovy button being too weak at the hinge, made the side buttons a little less sloppy
    [ev16-case-bottom-demo.step, ev16-case-bottom-dev.step, ev16-case-side-buttons.step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]
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2026-03-09 Separate AI and channel configuration in NET firmware
    Refactor the NET chip to independently configure AI namespaces and
    channel namespaces instead of conflating them in ChannelBuilder.
    Changes:
    - Replace ChannelBuilder with namespace utility functions
    - Add Set/Get_Language commands with validation (en-US, es-ES, de-DE, hi-IN, nb-NO)
    - Add Set/Get_Channel commands for channel namespace configuration
    - Add Set/Get_AI commands for AI query/audio/command response namespaces
    - Remove Set_Frontline_Config command
    - Update hactar-cli with new command handlers and namespace encoding
    - Command responses now update channel namespace dynamically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
    [net.cc]
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2026-03-11 Added link packet to python and mgmt codebases, fixed bugs between ui and net chips for transmitting packets
    [link_packet_handler.cc, net.cc]
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2026-03-14 Fix UART buffer overflow and NVS key length issues
    MGMT firmware:
    - Fix buffer overflow in uart_router_copy_to_tx when write wraps around
    - Increase PACKET_SZ and INTERNAL_BUFF_SZ from 64 to 256 bytes
    - Add LINK protocol line scanning for clean NET command responses
    NET firmware:
    - Shorten AI namespace NVS keys to fit 15-char ESP-IDF limit
    - Add key length validation and error logging to StoredValue class
    CLI:
    - Add namespace encoder support to monitor.py
    - Add test_nvs_persistence.py for NVS persistence testing
    [net.cc]
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2026-03-19 Remove hardcoded default namespaces from NET firmware
    Namespaces must now be explicitly configured via fl-identity tool.
    Replaced defaults with warning logs to help identify unconfigured devices.
    [net.cc]
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2026-03-24 Address PR review feedback: use JSON wire format, remove LINK filtering
    Changes based on @bifurcation and @BrettRegnier feedback:
    Firmware (C++):
    - Remove binary namespace encoding (EncodeNamespace/DecodeNamespace)
    - Use JSON for all namespace wire format (set_channel, set_ai)
    - set_ai now expects JSON object: {"query":[...],"audio":[...],"cmd":[...]}
    - JsonToNamespace now returns std::optional for proper error handling
    - Simplify NamespaceToJson to single expression
    - Remove LINK prefix filtering from uart_router (per Brett's feedback)
    - Use NET's internal disable_logs command instead
    Python CLI:
    - Remove binary encode_namespace function
    - Add shared encode_command_payload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
    [net.cc]
2026-03-24 Fix config command ACK/NACK response interleaving with logs
    - Use non-throwing JSON parse in JsonToNamespace to avoid ESP32 crashes
    - Send ACK/NACK before async track updates to prevent TLV bytes from
    interleaving with log output on the serial line
    - Add null checks for moq_session in CreateReadTrack/CreateWriteTrack
    - Reuse existing tracks if namespace matches (compare FullTrackName)
    - Call UpdateChannelTracks/UpdateAITracks when MoQ session becomes ready
    - Increase MgmtLinkPacketTask stack to 8KB for JSON parsing headroom
    - Improve test_config_commands.py to wait for device boot and enable logs
    [net.cc]
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2026-03-24 Fix blue LED not turning on when MOQ connects
    Initialize prev_status to kNotConnected instead of kReady so the
    status change detection actually triggers when MOQ becomes ready.
    [net.cc]
2026-03-24 Improve NET LED status indicators
    - Yellow on startup (no wifi)
    - Green when wifi connected
    - Blue when MOQ ready (set in StatusChanged callback)
    - Yellow when wifi disconnects
    - Add reset to upload_debugger target
    [net.cc, peripherals.cc]
2026-03-24 Refactor CreateReadTrack/CreateWriteTrack to take typed parameters
    Replace json parameter with explicit typed parameters:
    - channel_name: string
    - track_namespace: vector<string>
    - trackname: string
    - codec: string
    This removes intermediate json object construction in UpdateAITracks
    and UpdateChannelTracks, making the code cleaner and more type-safe.
    [net.cc]
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2026-03-24 Apply remaining PR comment suggestions
    - Shorten comment in uart_router.c (line 253)
    - Remove unnecessary comment in net.cc Get_Channel case
    [net.cc]
2026-03-25 Fix UART buffer handling and reduce UI-NET baud rate to 460800
    - Fix static sync_matched bug causing cross-instance TLV parser corruption
    - Fix circular buffer logic in serial.cc ReadTask and QueueReadTask
    - Increase UART task priorities from 10 to 20
    - Increase driver buffer sizes (tx: 2048→8192, rx: 4096→8192)
    - Increase NET_UI_UART_RX_BUFF_SIZE from 8192 to 16384
    - Reduce UI-NET baud rate from 921600 to 460800 to prevent FIFO overflows
    - Drain all available audio packets before sleeping in moq_track_reader
    [moq_track_reader.cc, net.cc, serial.cc]
2026-03-25 Fix compiler warnings in NET firmware
    - Add missing struct initializers for uart_config_t (flags field)
    - Add missing struct initializers for ledc_timer_config_t (deconfigure field)
    - Add missing struct initializers for ledc_channel_config_t (sleep_mode, flags)
    - Add missing initializer for quicr::ObjectHeaders::immutable_extensions
    - Fix StaticTask_t initialization (use {} instead of nullptr)
    - Remove unused variables (next, heartbeat, ready_to_connect_moq,
    channel_id, writer, payload_offset, bytes_to_read, offset)
    [moq_track_reader.cc, net.cc, peripherals.cc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]
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2026-03-25 Replace UI Version stub with Ping command (Phase 2)
    Phase 2 of unified protocol migration.
    - Replace Version enum with Ping in UI mgmt link protocol
    - Implement ping handler that echoes payload back (pong behavior)
    - Update CLI: "ui ping" replaces "ui version"
    [link_packet_handler.cc]
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2026-03-26 Unified WiFi commands with JSON (Phase 4)
    Phase 4 of unified protocol migration.
    Replace legacy WiFi commands with JSON-based unified commands:
    - Set_Ssid → Add_Wifi (accepts JSON: {"ssid":"...","password":"..."})
    - Get_Ssid_Names + Get_Ssid_Passwords → Get_Wifi (returns JSON array)
    - Clear_Ssids → Clear_Wifi
    CLI updated:
    - net add_wifi '{"ssid":"...","password":"..."}'
    - net get_wifi
    - net clear_wifi
    [net.cc]
2026-03-26 Replace toggle/enable/disable loopback and logs with get/set commands
    Phase 5 of unified protocol migration:
    - Add Get_Loopback (id 20), Set_Loopback (id 21) with u8 mode (0=off, 1=raw)
    - Add Get_Logs_Enabled (id 22), Set_Logs_Enabled (id 23) with u8 (0=disabled, 1=enabled)
    - Remove Toggle_Logs, Enable_Logs, Disable_Logs, Enable_Loopback, Disable_Loopback handlers
    - Update CLI to use new command names and IDs
    - Update docs/commands.md to reflect new commands
    [net.cc]
2026-03-26 Fix mgmt_serial TX complete callback not being called
    The HAL_UART_TxCpltCallback only handled net_serial, causing the
    mgmt_serial TX buffer to fill up and never drain. This resulted in
    "Transmit buffer full" errors for any UI command that sends a response.
    [app_main.cc]
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2026-03-26 Fix mgmt_serial DMA completion and EEPROM write offset
    - Add mgmt_serial handling to HAL_UART_TxCpltCallback so tx_free resets
    - Fix EEPROM PerformWrite to write data at given address (was adding spurious offset)
    - Move UI_LOG calls before serial replies to avoid DMA/blocking UART conflict
    - Use ReplyData with std::span for Get_Sframe_Key response
    [app_main.cc, link_packet_handler.cc]
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2026-03-26 Fix UI get_loopback/get_logs_enabled to use ReplyData TLV
    Was using serial.Write() which sends raw bytes without TLV wrapper,
    so CLI didn't recognize the response.
    [link_packet_handler.cc]
2026-03-27 Revise typed responses to match Link protocol
    - Remove generic Response_Data, use typed responses for all data
    - Rename Response_Nack to Response_Error (matches Link)
    - Rename response types to match Link naming conventions:
    - Response_WifiSsids (was SSID_NAMES/PASSWORDS, now JSON array)
    - Response_RelayUrl (was Moq_Url)
    - Response_AiConfig (was AI_Config)
    - Add missing response types: Response_Loopback, Response_LogsEnabled
    - Add UI response types: Response_SframeKey, Response_StackInfo
    - Update all firmware handlers to use typed responses
    - Update CLI to recognize and display typed responses
    - Update API documentation
    [link_packet_handler.cc, net.cc]
2026-03-28 Align protocol with Link TLV message types
    Update firmware and CLI to use Link-aligned command/response codes:
    UI Commands (CtlToUi): 0x0020-0x002C
    - Ping, GetSframeKey, SetSframeKey, Get/SetLoopback, etc.
    UI Responses (UiToCtl): 0x0030-0x0039
    - Pong, SframeKey, Ack, Error, Loopback, StackInfo, LogsEnabled
    NET Commands (CtlToNet): 0x0040-0x0052
    - AddWifiSsid, GetWifiSsids, Get/SetRelayUrl, Get/SetLoopback, etc.
    NET Responses (NetToCtl): 0x0050-0x005A
    - WifiSsids, RelayUrl, Ack, Error, Loopback, Language, Channel, Ai
    UI<->NET (audio frames): 0x0060-0x0071
    - UiToNet::AudioFrame = 0x0061
    - NetToUi::AudioFrame = 0x0071
    Legacy Configuration enum preserved for backwards compatibility.
    Co-Au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
    [link_packet_handler.cc]
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2026-03-28 Add missing command handlers and align EEPROM with Link format
    - Add CircularPing handler for UI chip (returns payload echo)
    - Add GetVersion/SetVersion handlers for UI (4-byte big-endian u32)
    - Add CircularPing handler for NET chip
    - Update ConfigStorage to match Link EEPROM layout:
    - Version: 4 bytes at offset 0 (was 1 byte with length prefix)
    - SFrame key: 16 bytes at offset 16 (aligned with Link)
    - Add version encoder to CLI for set_version command
    [link_packet_handler.cc, net.cc]
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2026-03-28 Upgrade MGMT-UI/NET baud to 1Mbaud and fix circular ping
    - Change MGMT-UI and MGMT-NET UART baud rates from 115200 to 1000000
    - Fix NET Pong to echo payload back (was returning empty)
    - Fix CircularPing to forward through the full circular path:
    - MGMT -> UI -> NET -> MGMT
    - MGMT -> NET -> UI -> MGMT
    [app_main.cc, link_packet_handler.cc, net.cc]
2026-03-30 Fix ClearStorage to also clear in-memory caches
    StoredValue::Clear() now resets the cached value and loaded flag.
    ClearStorage handler clears all StoredValue objects, namespace vectors,
    and WiFi credentials so changes take effect without reboot.
    [net.cc]
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2026-03-30 Fix circular include by using callback for TLV logging
    Use a callback function instead of directly including serial.hh to
    avoid circular dependency: logger.hh -> serial.hh -> link_packet_t.hh
    -> logger.hh.
    [app_main.cc]
2026-03-30 Add ReplyError method to SerialHandler with error messages
    - Add ReplyError(uint16_t type, const char* msg) method to SerialHandler
    - Replace all empty error responses with descriptive messages
    - UI errors: version, SFrame key, loopback, logs enabled
    - NET errors: storage, wifi, loopback, logs, language, channel, AI config, eFuse
    [link_packet_handler.cc, net.cc]
2026-03-31 Fix ClearStorage to clear in-memory caches without NVS writes
    - Use .stored.clear() instead of .Clear() to avoid writing to already-cleared NVS
    - Clear stored_creds cache in Wifi::ClearSavedSSIDs()
    [net.cc]
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2026-05-05 Add rule to erase net flash and fix endpoint id for quicr metrics.
    [net.cc]
2026-05-07 EV17 firmware (#478)
    * Changing to link ctl format:
    * Getting C mgmt up to date with the CTL
    * Remove software and C mgmt
    * Added commands for adjusting volume and mic-preamp
    * Added ui loopback, mic preamp controls
    * Added button class to clean up main
    * Updated timer to tick every 1ms
    * Added audio direction
    * Got transmitting to mgmt chip working
    * Restore mgmt folder
    * Restore software
    * Restore link to original
    * Restore link?
    * Added sending raw audio to net and to mgmt
    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
    [app_main.cc, audio_chip.cc, link_packet_handler.cc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]
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2026-05-28 Fix reordering bug on startup and fix bug with the tx and rx buffer sizes
    [net.cc]
2026-05-28 Flattened out TrackReader::WriteToSerial, left old code for reference (#451)
    * Flattened out TrackReader::WriteToSerial, left old code for reference
    * Fix missing reference to type and len
    * Address PR review
    [moq_track_reader.cc]
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2026-06-04 update caps for ldo, flip jp3 to default to vsys, update wm8960 and ch340c part, change holes to solder pads 2mm (refs #497, #546, #542, #472, #590)
    [ev18.kicad_sch]
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2026-08-03 Added missing footprints, used kicad10 wizard tool to design them, designed starting point of the board layout
    [audio.kicad_sch, ev19.kicad_pcb, ev19.kicad_sch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]
2026-08-03 Fixed a couple mistakes on the schematic, got general power layout of the hactar designed, finding layout for audio section
    [audio.kicad_sch, ev19.kicad_pcb, ev19.kicad_sch]
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2026-08-03 Fixed ES8311 symbol, pins were wrong. Laid out audio section. Routed many non-high speed traces
    [audio.kicad_sch, ev19.kicad_pcb, ev19.kicad_sch]
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2026-08-03 Redesigned and partially laid out where the ev19 will sit, designing around battery cut out and display connector
    [ev19.kicad_pcb]
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2026-08-03 Redesigned digital section again to fit the battery better. Chose where the screen connector and battery connector go
    [.step, ev19-case.FCStd, ev19.kicad_pcb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]
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2026-08-03 Debug pcb
    * Added missing footprints, used kicad10 wizard tool to design them, designed starting point of the board layout
    * Fixed a couple mistakes on the schematic, got general power layout of the hactar designed, finding layout for audio section
    * wip- laid out the analog power section, added screen cut outs, decided on positions
    * Laid out all high speed lines, created gnda, 3.0va, and dgnd 3.3vd in analog sections
    * Fixed ES8311 symbol, pins were wrong. Laid out audio section. Routed many non-high speed traces
    * Moved audio debug pins to audio page
    * Added wire for mic ptt, widened screen
    * Added lcd and battery models
    * Redesigned and partially laid out where the ev19 will sit,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
    [.step, debug_board.kicad_pcb, debug_board.kicad_sch]
2026-08-06 Fixed eeprom footprint, moved mount holes, added ptt buttons, adjusted location of screen jst connector
    [eeprom.kicad_sch, ev19.kicad_pcb, ui.kicad_sch]
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2026-09-29 Added lip to be able to open the top, gave more tolerance to the lip interlocking
    [debug-board-case-bottom.step, debug-board-case-top.step, debug-board-case.FCStd]
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2026-09-29 Fixed mistakes in the bottom and changed the way that the lip is calculated. Did the right hand side holes and added imprints for parts
    [ev19-case.FCStd]
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2026-09-29 fixed with keyboard sizing, missing notch for kb cable, missing hole for screen connector, screw pegs too thin, screen pocket too big, screw holes for keyboard wrong size
    [ev19-case.FCStd]
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2026-09-29 Change cable management system by shortening it and adding extra blocks, adjust thickness of push buttons, adjust hole size and location for m1.4 keyboard screws.
    [ev19-case.FCStd]
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
